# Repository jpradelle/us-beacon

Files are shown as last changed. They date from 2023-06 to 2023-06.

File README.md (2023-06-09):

# Ultrasonic indoor positioning system
This project contains electronic card design and software to build an indoor 2D positioning system based on ultrasonic 
emitters and receivers with Time Difference Of Arrival (TDOA) algorithm to determine position.

## Context
This project has been made during French Robotic Cup which takes place in european Eurobot contest. During this contest,
2 teams are playing one against the other, with one or two bots, to achieve some objectives, on a game table of 2 per 3
meters. Bots must not enter in collision with other team bots, purpose of this project is to determine quite precisely
position of 2 opponent bots.

Contest rules allow to place 3 fixed beacons on dedicated table places which will be called receivers, and a 
80mm\*80mm\*80mm beacon on each opponent bot which will be called emitters.

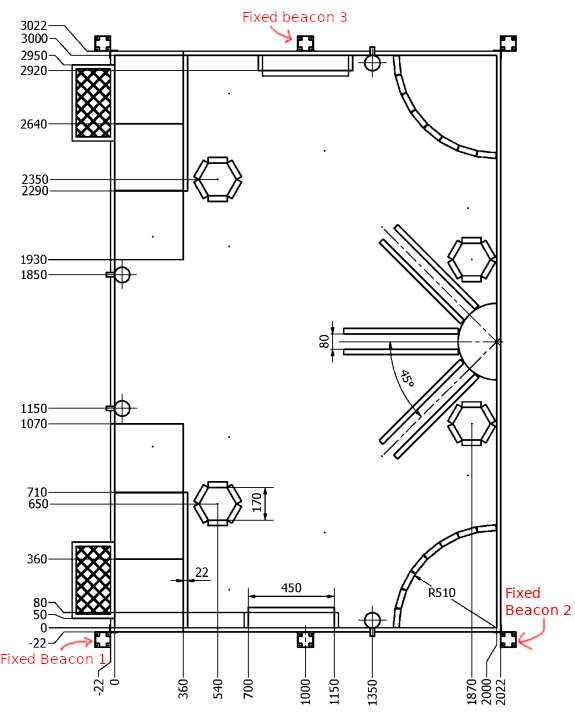
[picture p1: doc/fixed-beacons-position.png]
Fixed beacons position


See [contest rules](doc/E2017_Rules_EN.pdf) for more details.

### Extra considerations
* Due to intensive usage of 40kHz ultrasonic modules by other teams, we avoided use of 40kHz frequency.
* To avoid possible interference with other teams, a sort of "modulation" have been implemented.
* Using low frequency ultrasonic transceivers and receivers allow to emit/receive on a wide angle.

## Principle
An emitter is placed on opponent bot, emitter will emit every 75ms a signal over 360°. One of the three fixed receivers
will receive the signal first at time reference T. Due to slow speed of sound, the 2nd receives a bit later at T + dt1,
and the 3rd later next at T + dt2. Knowing speed of sound, dt1 and dt2 can be converted to distance dr1 and dr2. With
only dr1 and dr2 and a Time Difference Of Arrival (TDOA) algorithm, we can compute position of emitter on a plan.

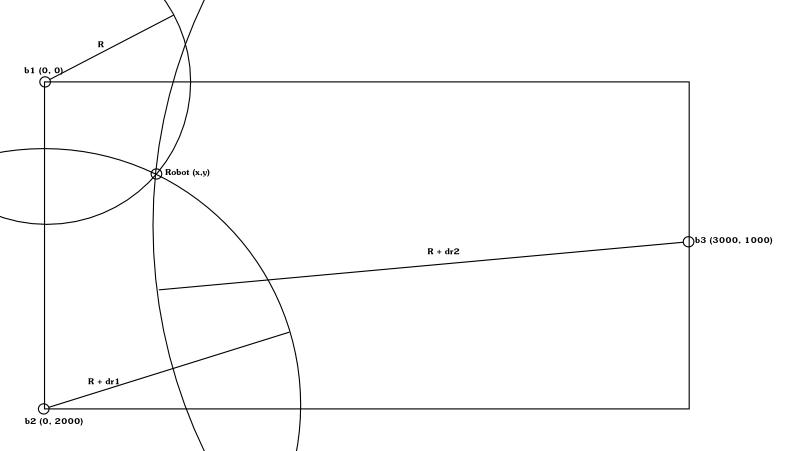
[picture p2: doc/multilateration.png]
multilateration


R is unknown, only dr1 and dr2 are determined by the system.

## System accuracy
TODO

## Architecture
Project is made of following parts.

### 2 emitters
One working with 25kHz frequency, one with 32.8kHz frequency. Emitters are made of:
* 1 9V battery
* 1 ATtiny45 microcontroller for pulse generation
* 4 ultrasonic transceivers
* some electronic for power supply, H bridge to run transceivers, ...

### 3 receivers
Each receiver beacon is made with one cards to receive 25kHz another one to receive 32.8kHz signals with 2 or 3
ultrasonic receivers.

Each ultrasonic receiver is made of
* 1 ultrasonic receiver
* 1 4 channels TLO74CN Operational Amplifier
* Some resistors, capacitors and schottky diodes for signal amplification and filtering
* 1 ATtiny45 for reading analog input and building a simple HIGH signal when ultrasonic signal is received

It contains also a power card which ensure different power conversions and aggregate demodulated signals from receivers,
made of:
* 2 9V battery
* 1 12V NCP1117DT12RKG convertor
* 1 5V R-78E5.0-0.5 convertor
* 1 3.3 LP2950ACDT-3.3RG convertor (for receiver beacon 1 only)
* Few connectors

#### Receiver 1
Contains 1 power card, 1 card with 2 receiver channels of 25kHz and 1 card with 2 receiver channels of 32.8kHz.

It also contains 1 RF card, which receive all numerical signals produced by receivers channels, compute TDOA algorithm
and send position by serial to RF module. It is made of:
* 1 Teensy 3.2 micro controller
* 1 RFBee (or 1 ESP8266, extra adaptor card needed)
* Few 3.3V zener diodes and schottky diodes
* Few connectors

#### Receiver 2
Contains 1 power card, 1 card with 2 receiver channels of 25kHz and 1 card with 2 receiver channels of 32.8kHz.

#### Receiver 3
Contains 1 power card, 1 card with 3 receiver channels of 25kHz and 1 card with 3 receiver channels of 32.8kHz.

## Folder structure of project
### Simulation
[simu](simu) folder contains some simulations for testing different TOA and TDOA algorithms.
See [simu/README.md](simu/README.md) for more details of algorithms performances.

### Electronics
[elec](elec) folder contains electronic designs of one 25kHz emitter, one 32.8kHz emitter, 3 receivers of 25kHz and
32.8kHz, and other power cards. See [elec/README.md](elec/README.md) for more information.

### Code
[code](code) folder contains code of all microcontroller used in this project. See [code/README.md](code/README.md) for
more information.

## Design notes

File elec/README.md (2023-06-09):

# Electronic
This folder contains needed electronics schema made with Kicad software for building working solution for 2 bots
positioning.

## Kicad projects
### 25kHz emitter
Electronic schematics and PCB drawings are made in [emetteur 25khz](emetteur%2025khz) project.

PDF schematics [here](../doc/elec/25khz_emitter_schematics.pdf)

### 32.8kHz emitter
Electronic schematics and PCB drawings are made in [emetteur 32khz](emetteur%2032khz) project.

PDF schematics [here](../doc/elec/32khz_emitter_schematics.pdf)

### 3 sets of 25kHz receivers
Electronic schematics and PCB drawings are made in [recepteur 25khz](recepteur%2025khz) project.

PDF schematics [here](../doc/elec/25khz_receiver_schematics.pdf)

Project contains stuff for building 2 fixed receiving beacons made of 2 ultrasonic receivers and 1 fixed receiving
beacon made of 3 ultrasonic receivers.

This projects contains other cards, see after.

### 3 sets of 32.8kHz receivers
Electronic schematics and PCB drawings are made in [recepteur 32khz](recepteur%2032khz) project.

PDF schematics [here](../doc/elec/32khz_receiver_schematics.pdf)

Project contains stuff for building 2 fixed receiving beacons made of 2 ultrasonic receivers and 1 fixed receiving
beacon made of 3 ultrasonic receivers.

### 3 power cards
Electronic schematics and PCB drawings are made in [recepteur 25khz](recepteur%2025khz) project.

Those 3 power cards are made for powering receiving cards and aggregating receiving cards signal to output them on one
connector.

### RF card
Electronic schematics and PCB drawings are made in [recepteur 25khz](recepteur%2025khz) project.

This RF card made for running TDOA algorithm with signals given from 3 power cards on a teensy microcontroller, found
position is expected to be transmitted by serial to RF card.

## Bill Of Material
### 25kHz emitter
| Item | Qty | Reference(s) | RadioSpares ref |
|---|-----|---|---|
| 100n | 1 | C1 | 264-4416 |
| LED | 1 | D1 | |
| ATTINY45-P | 1 | IC1 | 696-2614 |
| CONN_2 | 5 | P1, P3, P4, P5, P6 | 163-5303, 163-5305 |
| 2N3904 | 8 | Q1, Q4, Q5, Q7, Q9, Q12, Q14, Q16 | 739-0397 |
| 2N3906 | 8 | Q2, Q3, Q6, Q8, Q10, Q11, Q13, Q15 | 739-0375 |
| 22k | 16  | R1, R2, R4, R5, R7, R8, R9, R10, R11, R12, R16, R17, R18, R19, R20, R21 | 740-9016 |
| 1k | 5 | R3, R6, R13, R14, R15 | 740-8971 |
| 10k | 1 | R22 | 740-9072 |
| R-78E5.0-0.5 | 1 | REGUL1 | 757-7239 |
| SWITCH | 1 | U1 | 734-7315 |

+ 4 25kHz Ultrasonic transmitters

### 32.8kHz emitter
| Item | Qty | Reference(s) | RadioSpares ref |
|---|-----|---|---|
| 100n | 1 | C1 | 264-4416 |
| LED | 1 | D1 | |
| ATTINY45-P | 1 | IC1 | 696-2614 |
| CONN_2 | 5 | P1, P3, P4, P5, P6 | 163-5303, 163-5305 |
| 2N3904 | 8 | Q1, Q4, Q5, Q7, Q9, Q12, Q14, Q16 | 739-0397 |
| 2N3906 | 8 | Q2, Q3, Q6, Q8, Q10, Q11, Q13, Q15 | 739-0375 |
| 22k | 16  | R1, R2, R4, R5, R7, R8, R9, R10, R11, R12, R16, R17, R18, R19, R20, R21 | 740-9016 |
| 1k | 5 | R3, R6, R13, R14, R15 | 740-8971 |
| 10k | 1 | R22 | 740-9072 |
| R-78E5.0-0.5 | 1 | REGUL1 | 757-7239 |
| SWITCH | 1 | U1 | 734-7315 |

+ 4 32.8kHz Ultrasonic transmitters

### 25kHz receivers + power cards + RF card
| Value | Qty | Reference(s) | RadioSpares ref |
|---|-----|---|---|
| 10n | 14  | C1, C5, C12, C16, C23, C27, C34, C38, C45, C49, C56, C60, C67, C71 | 264-4371 |
| 470p | 14  | C2, C8, C13, C19, C24, C30, C35, C41, C46, C52, C57, C63, C68, C74 | 264-4315 |
| 47n | 14  | C3, C4, C14, C15, C25, C26, C36, C37, C47, C48, C58, C59, C69, C70 | 147-998 |
| 100n | 21  | C6, C7, C11, C17, C18, C22, C28, C29, C33, C39, C40, C44, C50, C51, C55, C61, C62, C66, C72, C73, C77 | 264-4416 |
| 1n | 14  | C9, C10, C20, C21, C31, C32, C42, C43, C53, C54, C64, C65, C75, C76 | 264-4337 |
| 10µ | 6 | C78, C79, C80, C81, C82, C83 | 440-6553 |
| 1µ | 1 | C84 | |
| DIODESCH | 42  | D1, D2, D3, D4, D5, D6, D7, D8, D9, D10, D11, D12, D13, D14, D15, D16, D17, D18, D19, D20, D21, D22, D23, D24, D25, D26, D27, D28, D39, D41, D43, D45, D47, D49, D51, D53, D55, D57, D59, D61, D63, D65 | 743-5894 |
| LED | 10  | D29, D30, D31, D32, D33, D34, D35, D36, D37, D38 | |
| ZENER | 14  | D40, D42, D44, D46, D48, D50, D52, D54, D56, D58, D60, D62, D64, D66 | 710-4216 |
| ATTINY45-P | 7 | IC1, IC2, IC3, IC4, IC5, IC6, IC7 | 696-2614 |
| TEENSY | 1 | IC8 | |
| CONN_3 | 1 | K1 | 163-5303, 163-5305 |
| CONN_6 | 6 | P1, P4, P5, P8, P10, P17 | 163-5303, 163-5305 |
| CONN_2 | 6 | P2, P3, P6, P7, P12, P13 | 163-5303, 163-5305 |
| CONN_5 | 2 | P9, P19 | 163-5303, 163-5305 |
| CONN_7 | 7 | P11, P14, P15, P16, P18, P20, P21 | 163-5303, 163-5305 |
| CONN_4 | 1 | P22 | 163-5303, 163-5305 |
| 1k | 21  | R1, R2, R5, R11, R12, R13, R14, R17, R27, R33, R34, R37, R45, R46, R49, R55, R56, R59, R65, R66, R69 | 740-8971 |
| 10k | 37  | R3, R4, R8, R15, R16, R20, R23, R24, R25, R26, R30, R35, R36, R40, R43, R44, R47, R48, R52, R57, R58, R62, R67, R68, R72, R75, R76, R77, R78, R79, R80, R81, R82, R83, R84, R85, R86 | 740-9072 |
| 47k | 28  | R6, R7, R9, R10, R18, R19, R21, R22, R28, R29, R31, R32, R38, R39, R41, R42, R50, R51, R53, R54, R60, R61, R63, R64, R70, R71, R73, R74 | 740-9035 |
| 2.2k | 14  | R87, R88, R89, R90, R91, R92, R93, R94, R95, R96, R97, R98, R99, R100 | 810-1750 |
| RFBEE | 1 | RF1 | |
| TL074 | 7 | U1, U2, U3, U4, U9, U10, U11 | 302-621 |
| R-78E5.0-0.5 | 3 | U5, U7, U12 | 757-7239 |
| NCP1117DT12RKG | 3 | U6, U8, U13 | 518-8341 |
| SWITCH | 3 | U14, U15, U16 | 734-7315 |
| LP2950ACDT-3.3RG | 1 | U17 | 805-1416 |
| ULTRASON | 7 | US1, US2, US3, US4, US5, US6, US7 | |

### 32.8kHz receivers
| Value | Qty | Reference(s) | RadioSpares ref |
|---|-----|---|---|
| 6.8n | 14  | C1, C5, C12, C16, C23, C27, C34, C38, C45, C49, C56, C60, C67, C71 | |
| 220p | 14  | C2, C8, C13, C19, C24, C30, C35, C41, C46, C52, C57, C63, C68, C74 | 264-4309 |
| 47n | 14  | C3, C4, C14, C15, C25, C26, C36, C37, C47, C48, C58, C59, C69, C70 | 147-998 |
| 100n | 21  | C6, C7, C11, C17, C18, C22, C28, C29, C33, C39, C40, C44, C50, C51, C55, C61, C62, C66, C72, C73, C77 | 264-4416 |
| 1n | 7 | C9, C20, C31, C42, C53, C64, C75 | 264-4337 |
| 2.2n | 7 | C10, C21, C32, C43, C54, C65, C76 | 264-4359 |
| DIODESCH | 28  | D1, D2, D3, D4, D5, D6, D7, D8, D9, D10, D11, D12, D13, D14, D15, D16, D17, D18, D19, D20, D21, D22, D23, D24, D25, D26, D27, D28 | 743-5894 |
| LED | 7 | D29, D30, D31, D32, D33, D34, D35 | |
| ATTINY45-P | 7 | IC1, IC2, IC3, IC4, IC5, IC6, IC7 | 696-2614 |
| CONN_6 | 2 | P4, P5 | 163-5303, 163-5305 |
| CONN_7 | 1 | P11 | 163-5303, 163-5305 |
| 1k | 21  | R1, R2, R5, R11, R12, R13, R14, R17, R27, R33, R34, R37, R45, R46, R49, R55, R56, R59, R65, R66, R69 | 740-8971 |
| 22k | 14  | R3, R8, R15, R20, R25, R30, R35, R40, R47, R52, R57, R62, R67, R72 | 740-9016 |
| 6.8k | 7 | R4, R16, R26, R36, R48, R58, R68 | 810-1889 |
| 47k | 28  | R6, R7, R9, R10, R18, R19, R21, R22, R28, R29, R31, R32, R38, R39, R41, R42, R50, R51, R53, R54, R60, R61, R63, R64, R70, R71, R73, R74 | 740-9035 |
| 10k | 7 | R77, R78, R79, R80, R81, R82, R83 | 740-9072 |
| TL074 | 7 | U1, U2, U3, U4, U9, U10, U11 | 302-621 |
| ULTRASON | 7 | US1, US2, US3, US4, US5, US6, US7 | |

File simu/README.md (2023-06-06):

# Simulation
This contains some algorithm implementation of Time Of Arrival (TOA) and Time Difference Of Arrival (TDOA) case.
Choosing TOA algorithm would be in case we have access to the 3 distances between each fixed beacon and emitter.
Choosing TDOA algorithm would be in case we only have access to distance difference between 1st and 2nd receiver and 1st
and 3rd receiver, which is the case in that project.

Purpose of this project is to test algorithm result error if we add a small distance error in measurements. We iterate
every table position several times, compute real distances between beacons, add a random error on each distance, compute
algorithm from those errored measurement and compare result with real position.

## Simulated algorithms
### TDOA Fang
Paper explaining it: 
[http://xml.jips-k.org/full-text/view?doi=10.3745/JIPS.04.0172](http://xml.jips-k.org/full-text/view?doi=10.3745/JIPS.04.0172)

Implemented in
[SimuMultilateration/src/com/opensabot/multilateration/tdoa/FangThreePointsLateration.java](SimuMultilateration/src/com/opensabot/multilateration/tdoa/FangThreePointsLateration.java)

### TDOA Iterative three points
Kind of brute force not working solution, you can ignore it.

Implemented in
[SimuMultilateration/src/com/opensabot/multilateration/tdoa/IterativeThreePointsLateration.java](SimuMultilateration/src/com/opensabot/multilateration/tdoa/IterativeThreePointsLateration.java)

### TOA Circle three points
Principle: draw circles around each fixed receiver of radius of measured value, find intersection of the three circules.

Implemented in
[SimuMultilateration/src/com/opensabot/multilateration/toa/CircleThreePointsToaLateration.java](SimuMultilateration/src/com/opensabot/multilateration/toa/CircleThreePointsToaLateration.java)

### TOA TULIP three points
Principle: https://confluence.slac.stanford.edu/display/IEPM/TULIP+Algorithm+Alternative+Trilateration+Method

Implemented in
[SimuMultilateration/src/com/opensabot/multilateration/toa/TulipThreePointsToaLateration.java](SimuMultilateration/src/com/opensabot/multilateration/toa/TulipThreePointsToaLateration.java)

# Run project
Project contains several entry points for different tests. We will focus on `com.opensabot.multilateration.ImageSimu`
which generate a graph of average error of algorithm.

## Configure project
In `com.opensabot.multilateration.ImageSimu` you can update constants:
* `NB_ITERATION = 100` is the number of iteration to run algorithm for each position.
* `ERROR = 68` is the maximum of random error to be added on measurements. 68mm correspond to the distance ran by 5 
  25kHz ultrasonic pulses (340 * 1/25000 * 5 = 0.068m), which feels achievable objective for the hardware.
* `ERROR_THRESHOLD_AVG = 100` is the max value of scale displayed at right of generated image for average error graph.
* `ERROR_THRESHOLD_MAX = 250` is the max value of scale displayed at right of generated image for max error graph.

You can also comment algorithm you don't want to run and chose one and only to run in this block of code
```java
		// Run wanted algorithm
		// TOA algorithms
//		runToa1CircleThreePointsToaLateration(b1, b2, b3, errorMap);
//		runToa2CircleThreePointsToaLateration(b1, b2, b3, b12, b22, b32, errorMap);
//		runToa1TulipThreePointsToaLateration(b1, b2, b3, errorMap);
//		runToa2TulipThreePointsToaLateration(b1, b2, b3, b12, b22, b32, errorMap);
		// TDOA algorithms
		runTdoa1FangThreePointsLateration(b1, b2, b3, errorMap);
//		runTdoa2FangThreePointsLateration(b1, b2, b3, b12, b22, b32, errorMap);
//		runTdoa1IterativeThreePointsLateration(b1, b2, b3, errorMap);
```

Some configuration run only one measurement compute with one set of fixed beacons, and other run it with two sets of
fixed beacons and get average of two measurements.

## Run simulation
Either open and run project with and IDE and ensure working directory is set to `simu/SimuMultilateration`.

Or open a console and go to SimuMultilateration project, and compile it.
```bash
cd simu/SimuMultilateration
javac src/**/*.java -d target/
```

Run viewer
```bash
java -cp target/ com.opensabot.multilateration.ImageSimu
```

# Results
All simulations were ran with a random error between 0 to 68mm added in values that hardware will measure, 500
iterations.

68mm error correspond to an error of 5 ultrasonic pulses at 25kHz.

## TDOA
### Fang algorithm
With one set of 3 fixed receiving beacon:

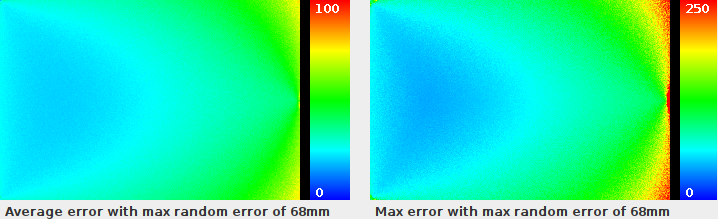
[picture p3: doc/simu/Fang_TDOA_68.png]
FANG_TDOA


With one 2 sets of 3 fixed receiving beacon, final point is average of 2 found positions:

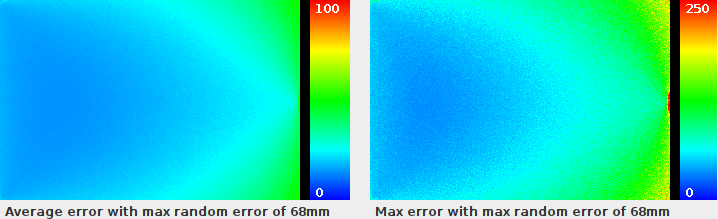
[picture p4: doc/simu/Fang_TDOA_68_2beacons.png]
FANG_TDOA


## TOA
### Circle algorithm
With one set of 3 fixed receiving beacon:

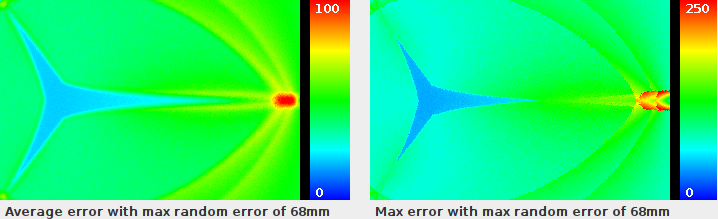
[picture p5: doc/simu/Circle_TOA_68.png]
CIRCLE_TDOA


With one 2 sets of 3 fixed receiving beacon, final point is average of 2 found positions:

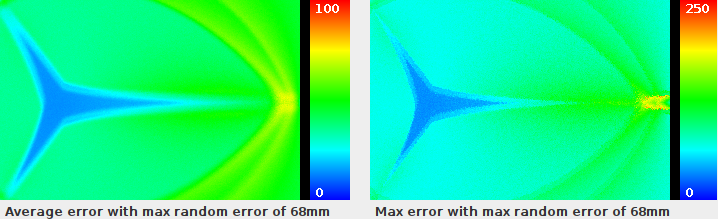
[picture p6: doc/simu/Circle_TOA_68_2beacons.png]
CIRCLE_TDOA


### TULIP algorithm
With one set of 3 fixed receiving beacon:

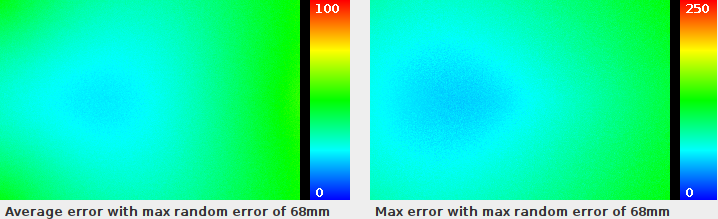
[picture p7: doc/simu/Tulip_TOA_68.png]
TULIP_TDOA


With one 2 sets of 3 fixed receiving beacon, final point is average of 2 found positions:

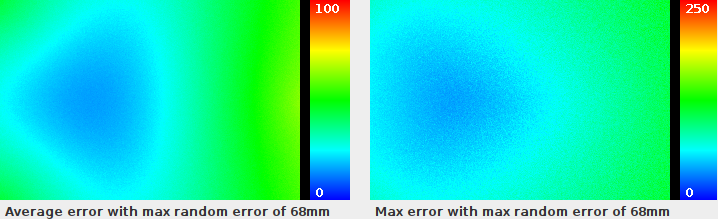
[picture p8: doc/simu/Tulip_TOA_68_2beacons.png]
TULIP_TDOA


## Conclusion
As we can see, choosing a TDAO algorithm instead of TOA will not make system less tolerant to errors in measurement, but
should be easier to implement. Adding multiple receivers even if very closed from each other should also improve system
accuracy. With not really accurate measurement, with an error of 68mm on measured values, worst found position has
almost alway an error of less than 12cm, and even less than 10cm in most cases.

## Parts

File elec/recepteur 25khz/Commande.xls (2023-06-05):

Type | Quantité | Ref | Ref part
100nF | 100 | 390-990 | 2644416
10nF | 50 | 264-4371
1nF | 50 | 264-4337
470pF | 50 | 264-4315
47nF | 50 | 147-998
10µF | 50 | 440-6553
1k Ohm | 100 | 740-8971
10k Ohm | 100 | 740-9072
22k Ohm | 50 | 740-9016
47k Ohm | 100 | 740-9035 | ERJ6RBD4702V
Interrupteur | 8 | 734-7315
ATTINY45-20PU | 20 | 696-2614
Diode schotky | 50 | 743-5894
NCP1117DT12RKG | 5 | 518-8341
TL074CN | 10 | 302-621
Zener 3,3V | 100 | 710-4216
2N3904 | 20 | 739-0397
2N3906BU | 20 | 739-0375
PCB | 3 | 745-0819
LP2950ACDT-3.3RG | 20 | 805-1416
1µF | 50 | 440-6531
Brucelle | 1 | 549-628 |  | http://fr.farnell.com/duratool/1pk-125t-f/pince-brucelle/dp/3127692
 |  |  |  | http://fr.farnell.com/duratool/1pk-110t-f/pince-brucelle-pointe-courbee/dp/3127620
 |  |  |  | http://www.ebay.fr/itm/pince-brucelle-precelle-PINCETTE-Coudee-droite-OUTIL-MAQUETTISME-COURBE-7-modele-/230930073922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
Farnell
Brucelle | 1
Regul 5V | 7

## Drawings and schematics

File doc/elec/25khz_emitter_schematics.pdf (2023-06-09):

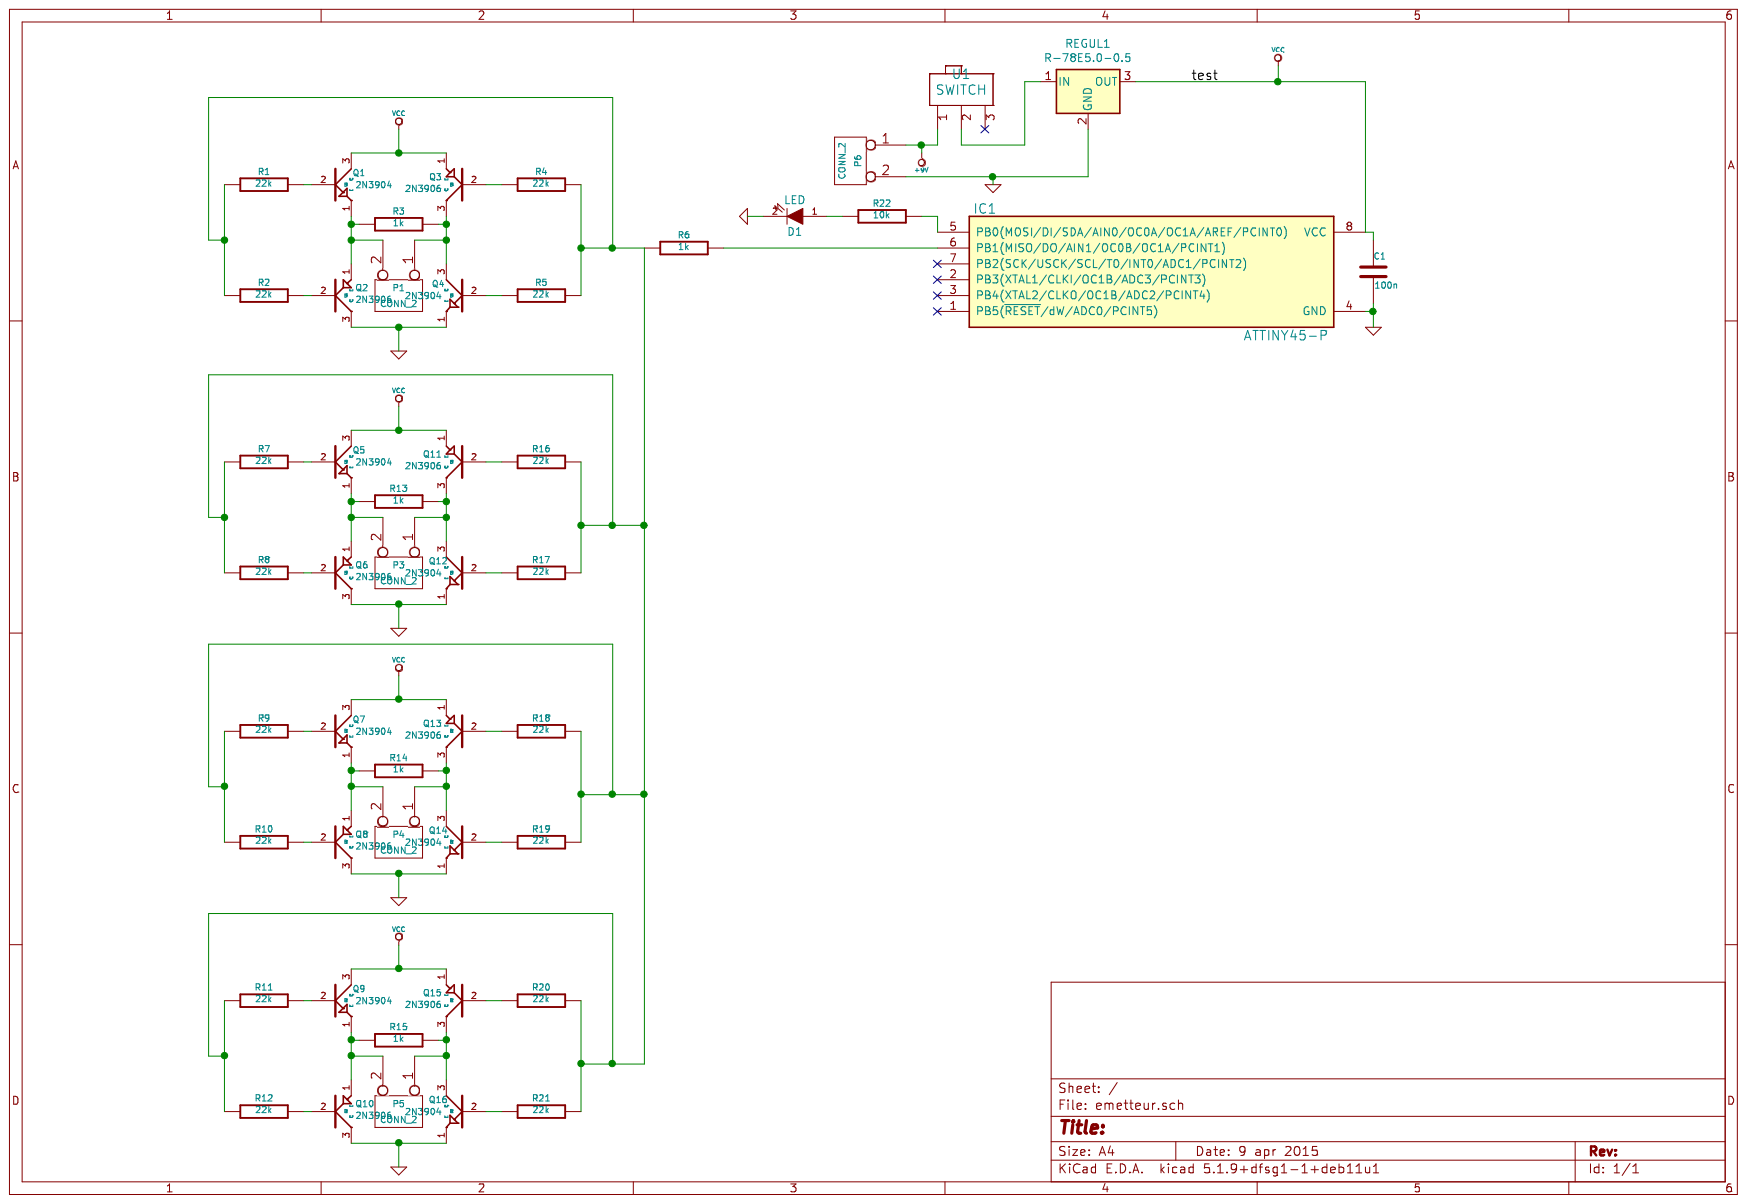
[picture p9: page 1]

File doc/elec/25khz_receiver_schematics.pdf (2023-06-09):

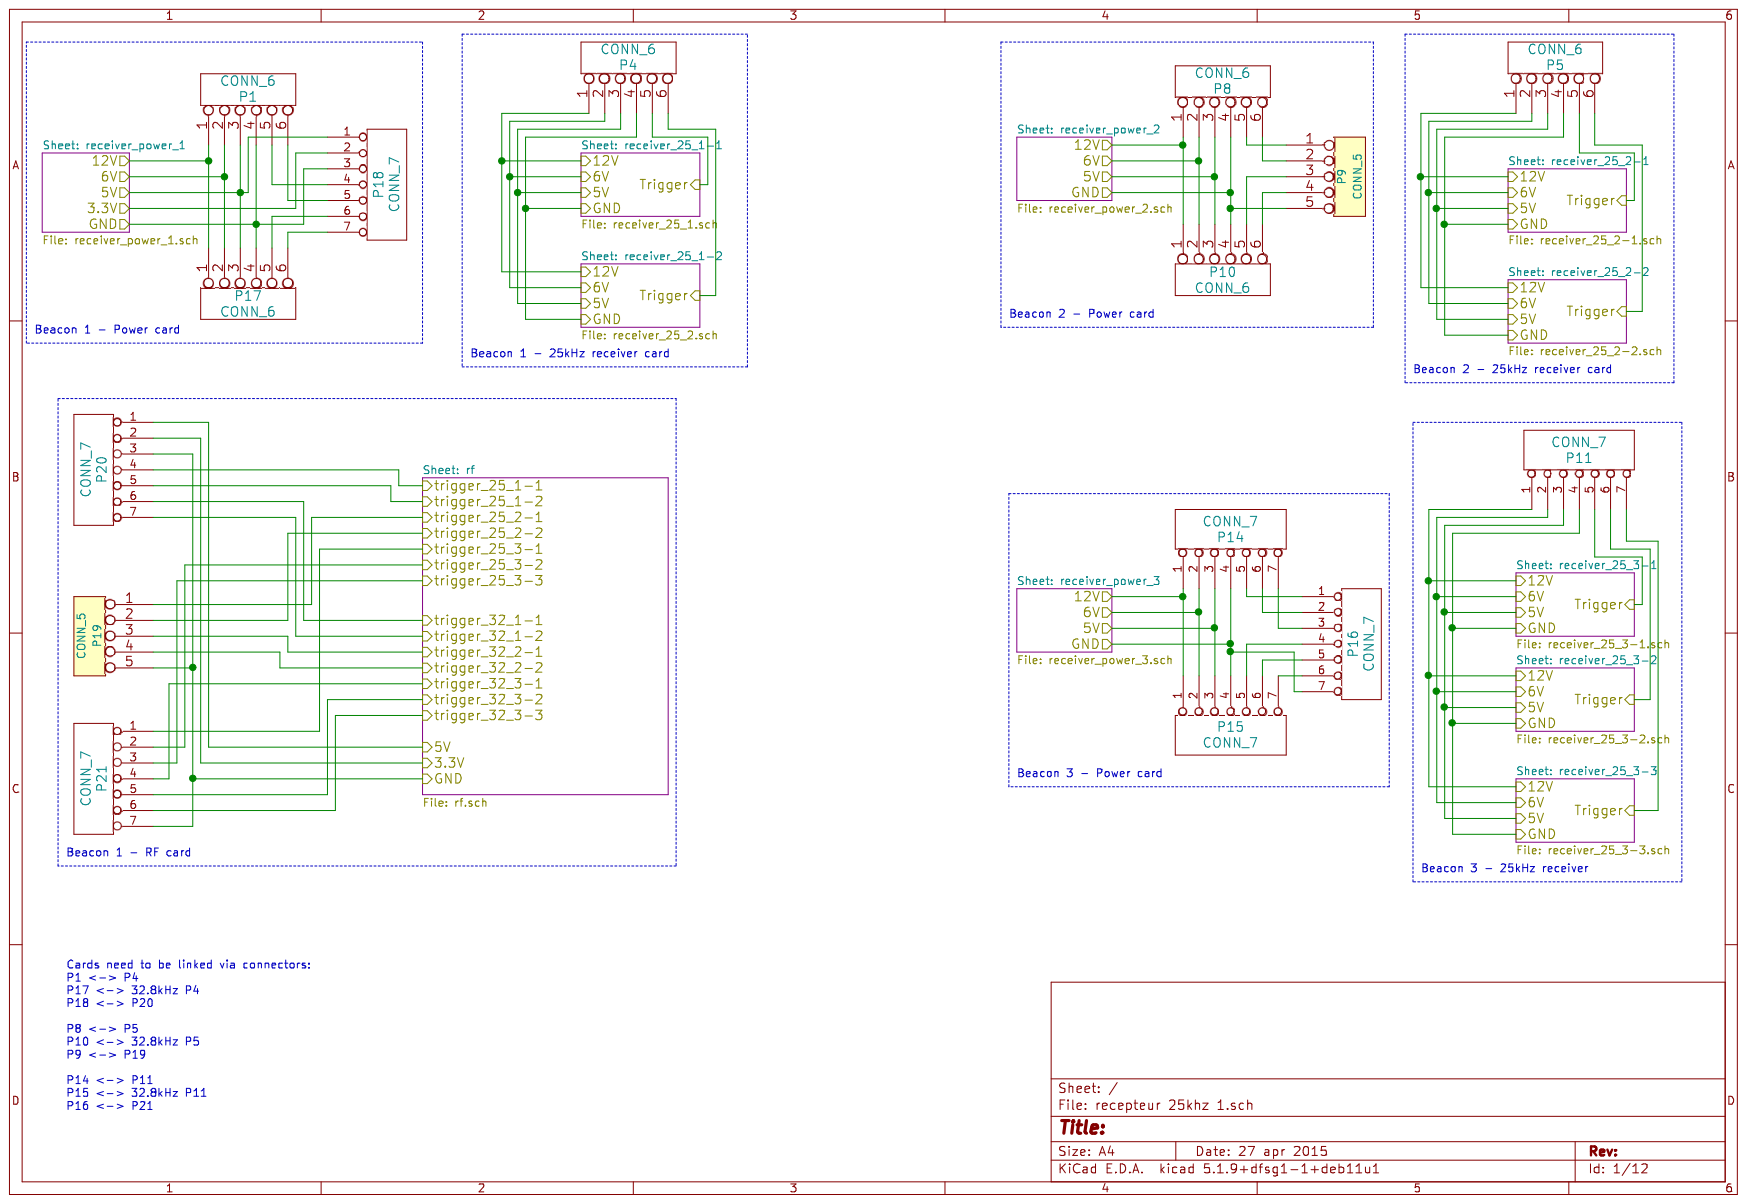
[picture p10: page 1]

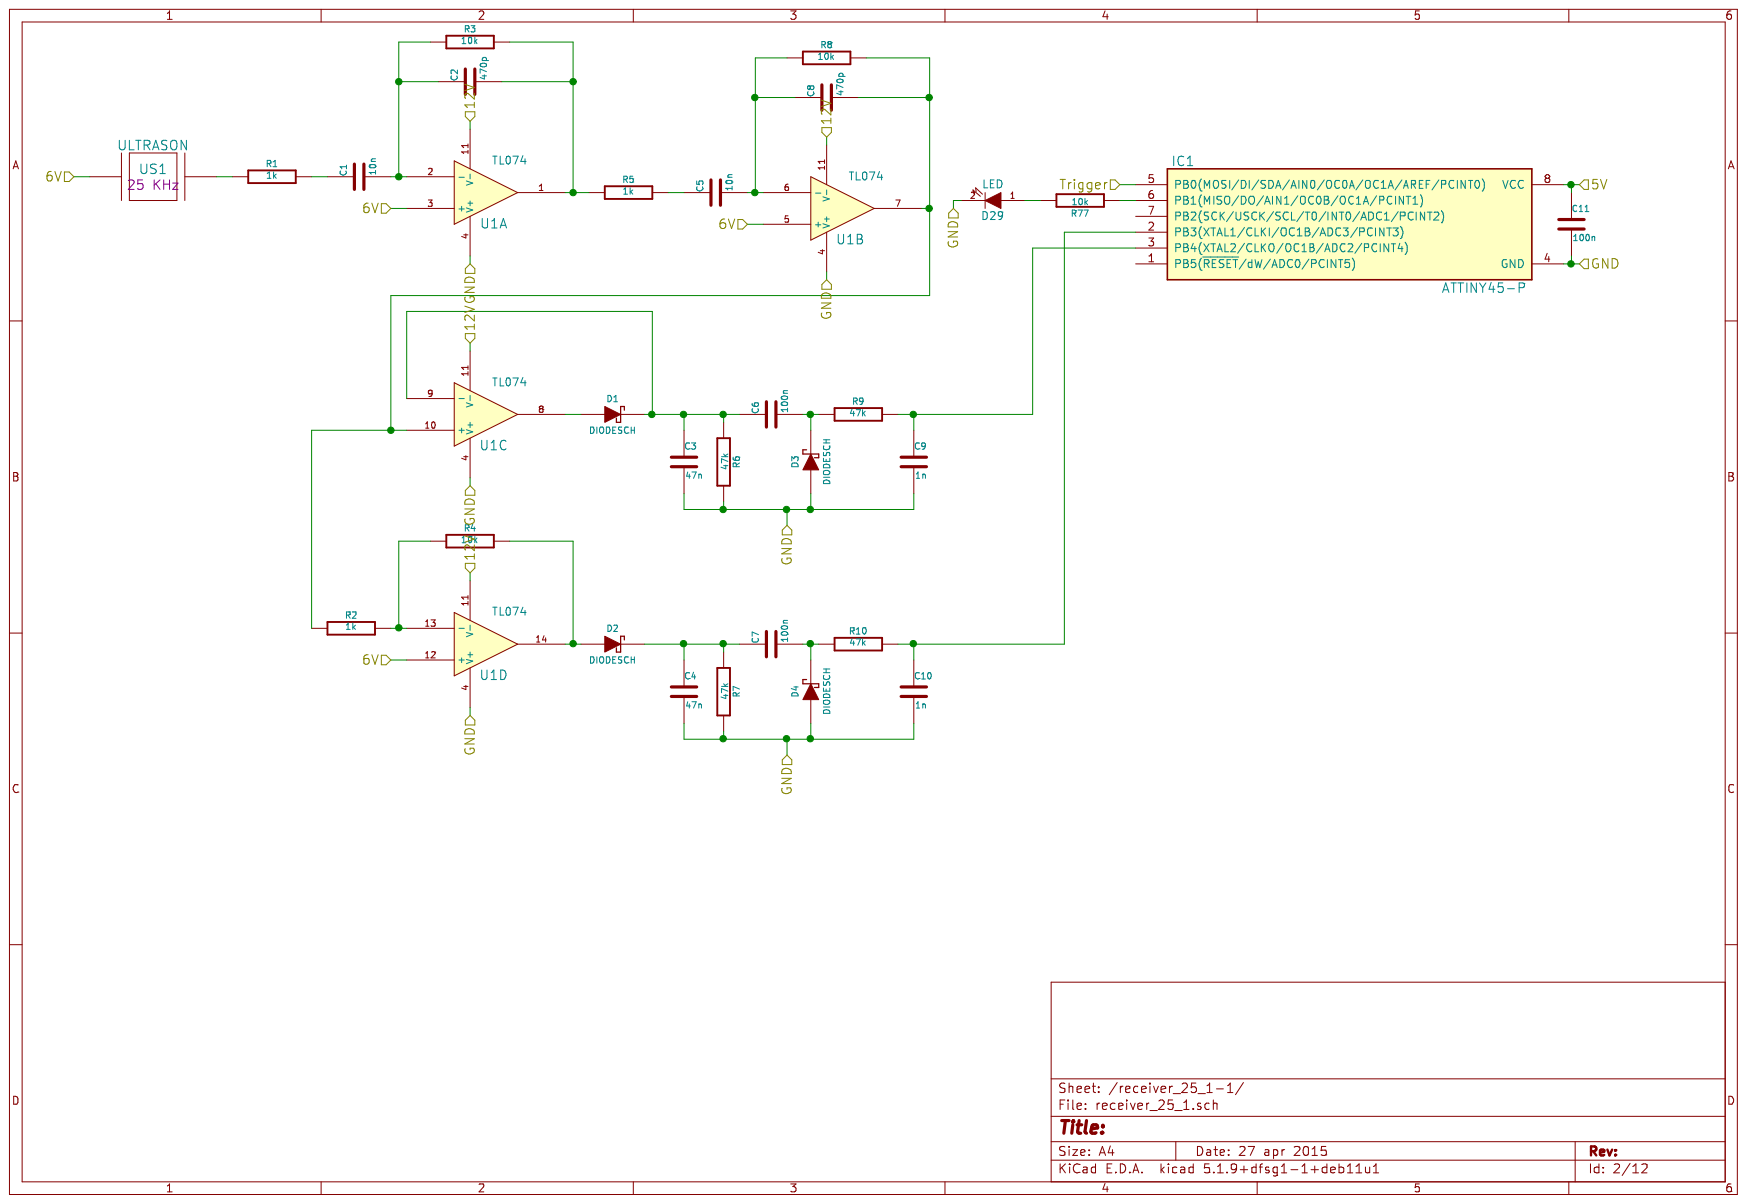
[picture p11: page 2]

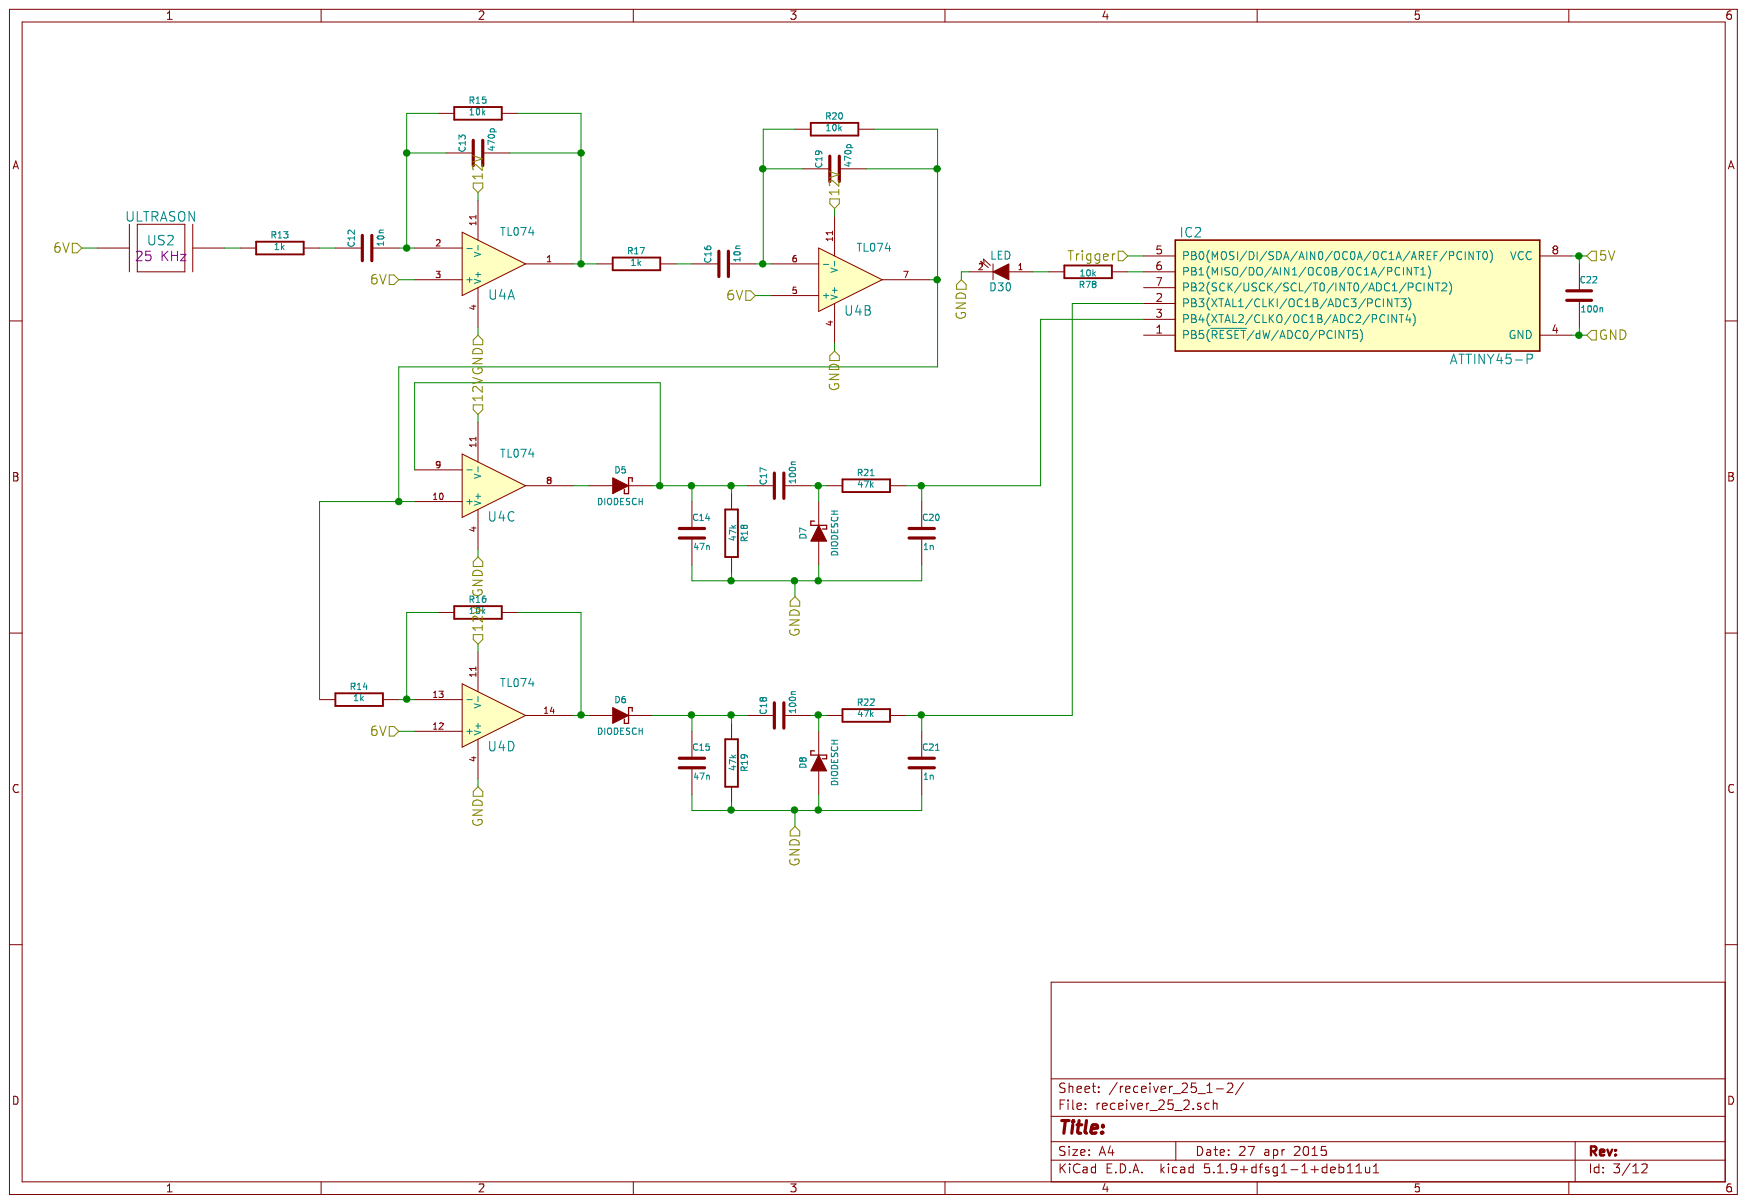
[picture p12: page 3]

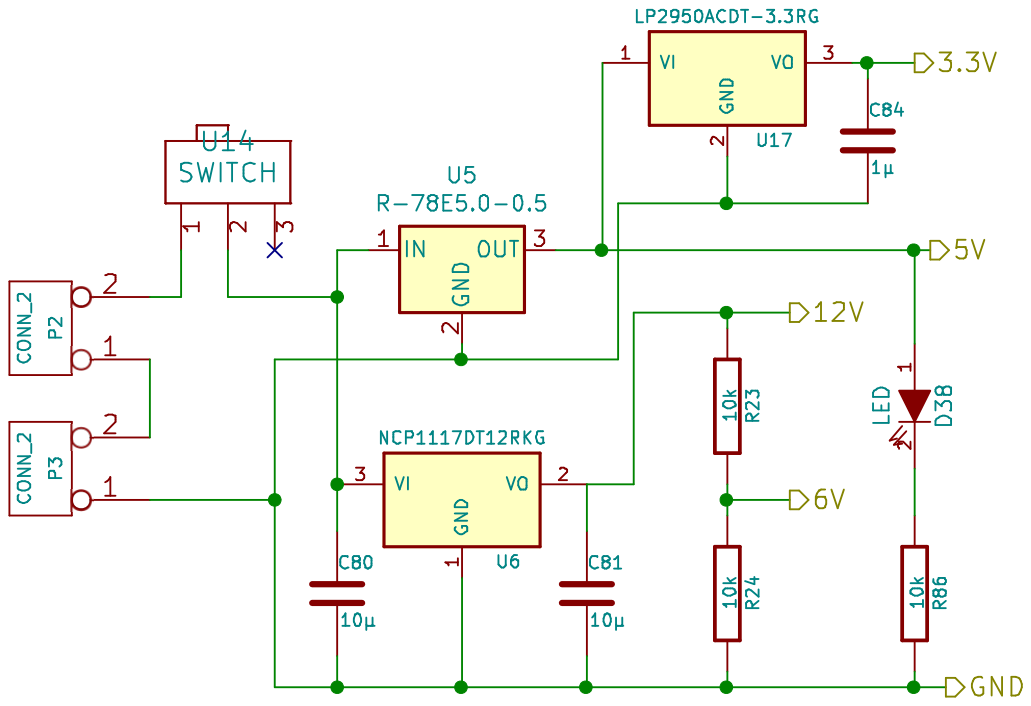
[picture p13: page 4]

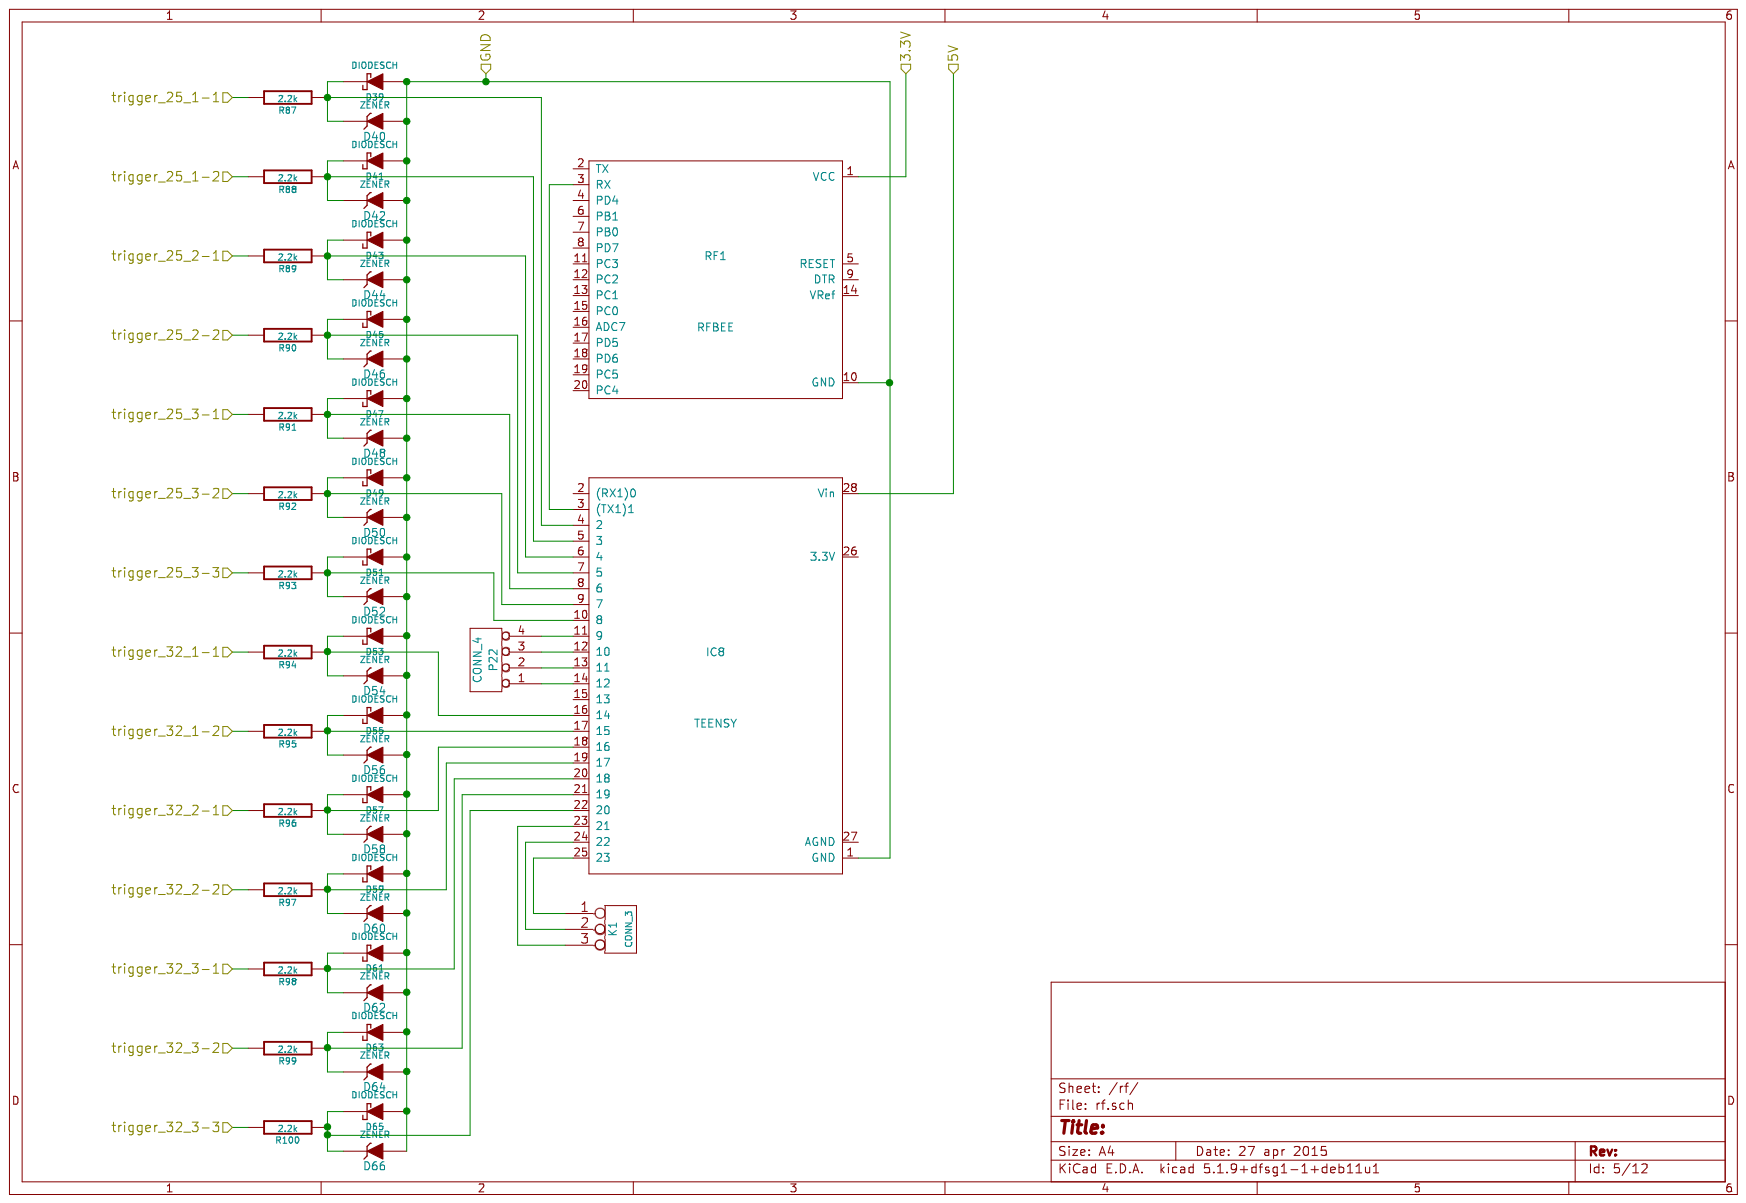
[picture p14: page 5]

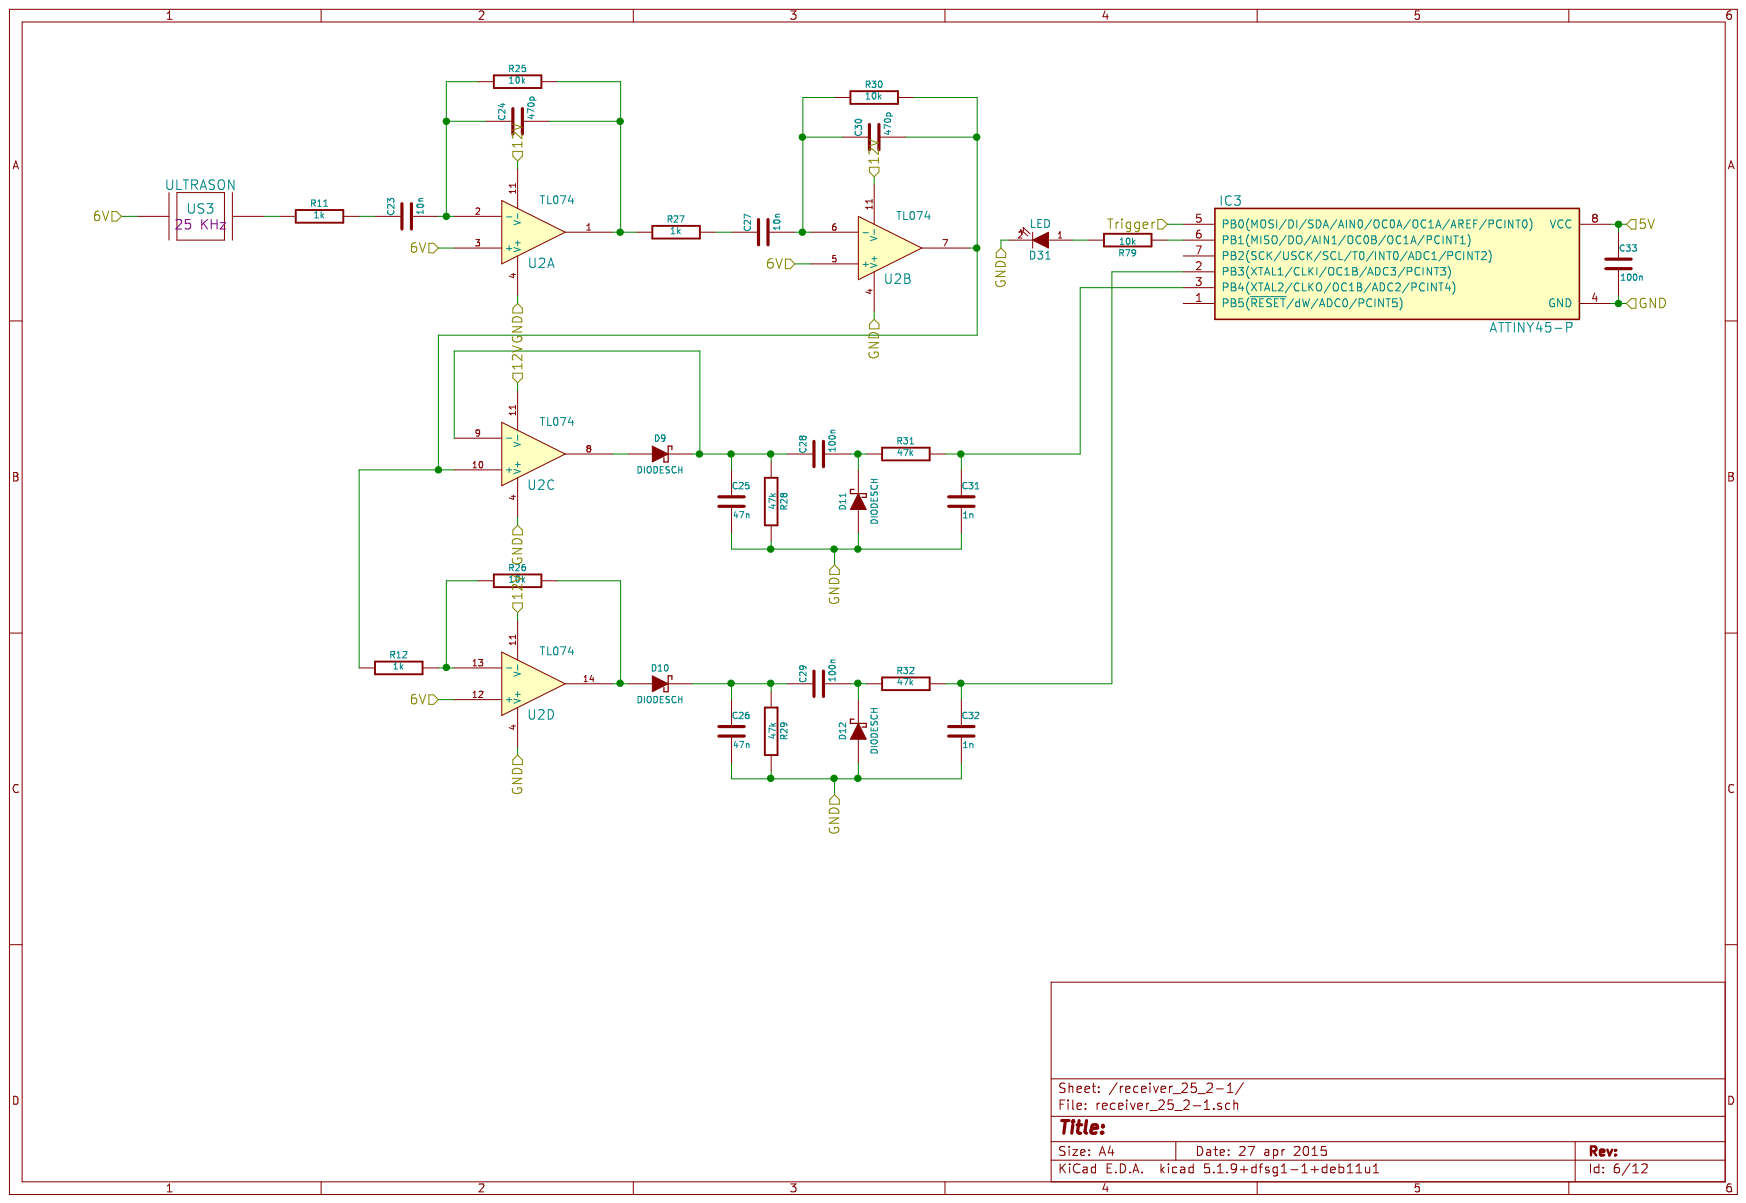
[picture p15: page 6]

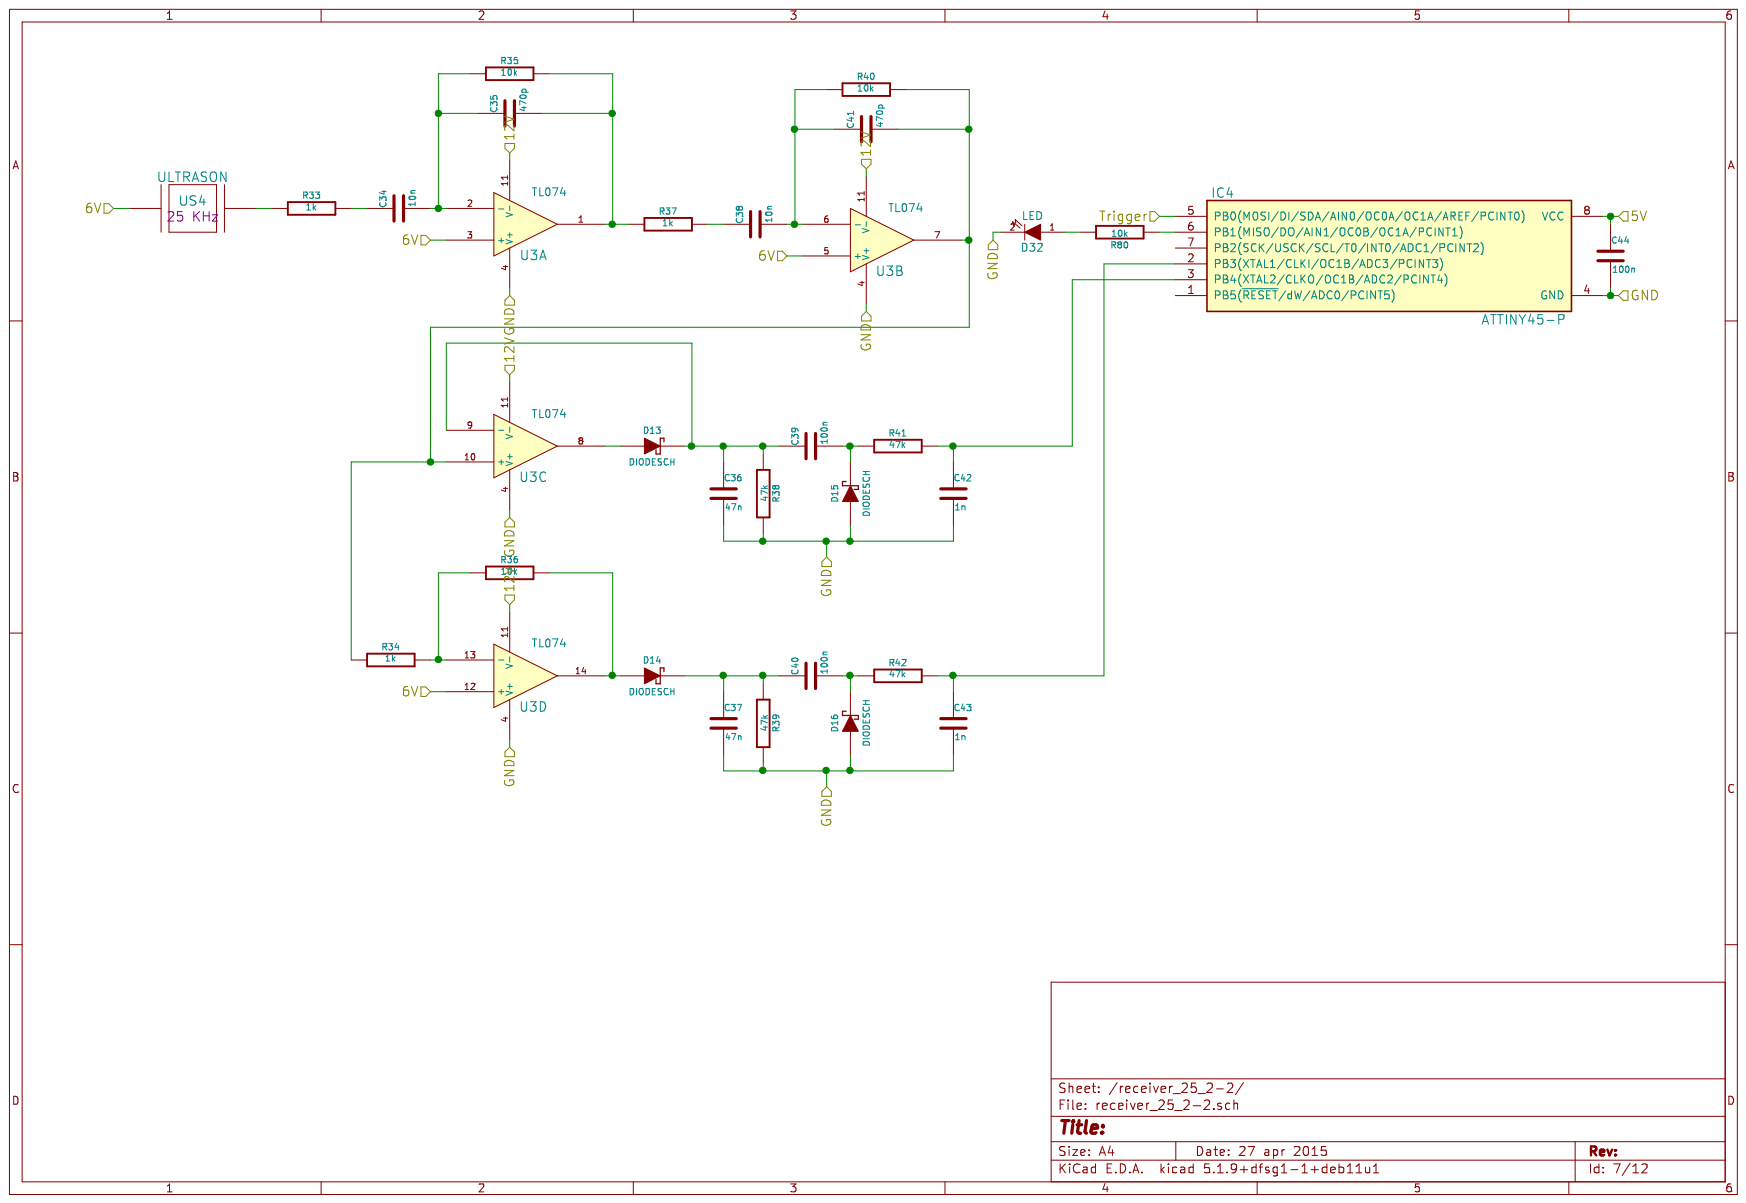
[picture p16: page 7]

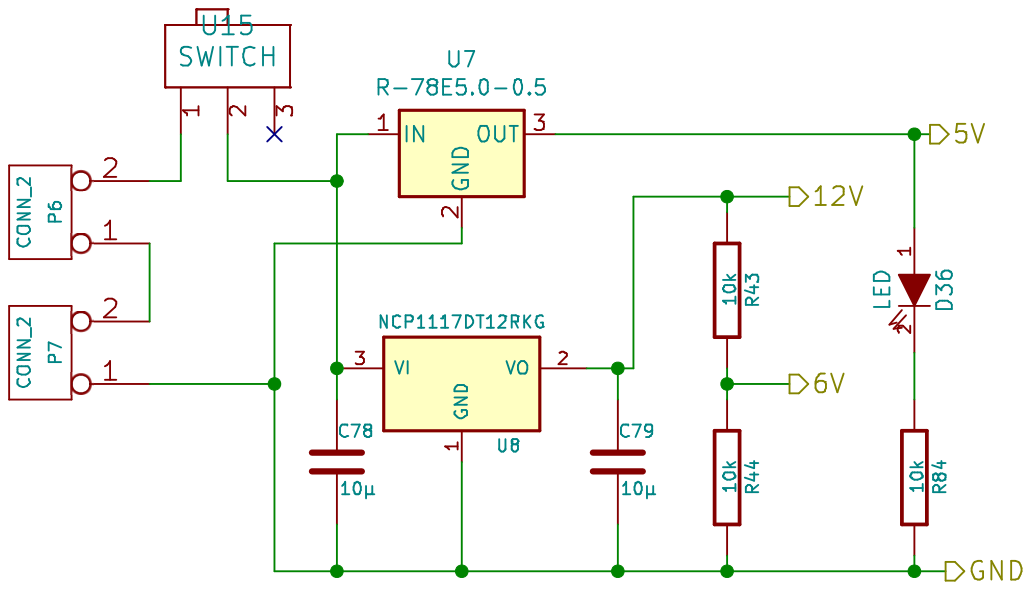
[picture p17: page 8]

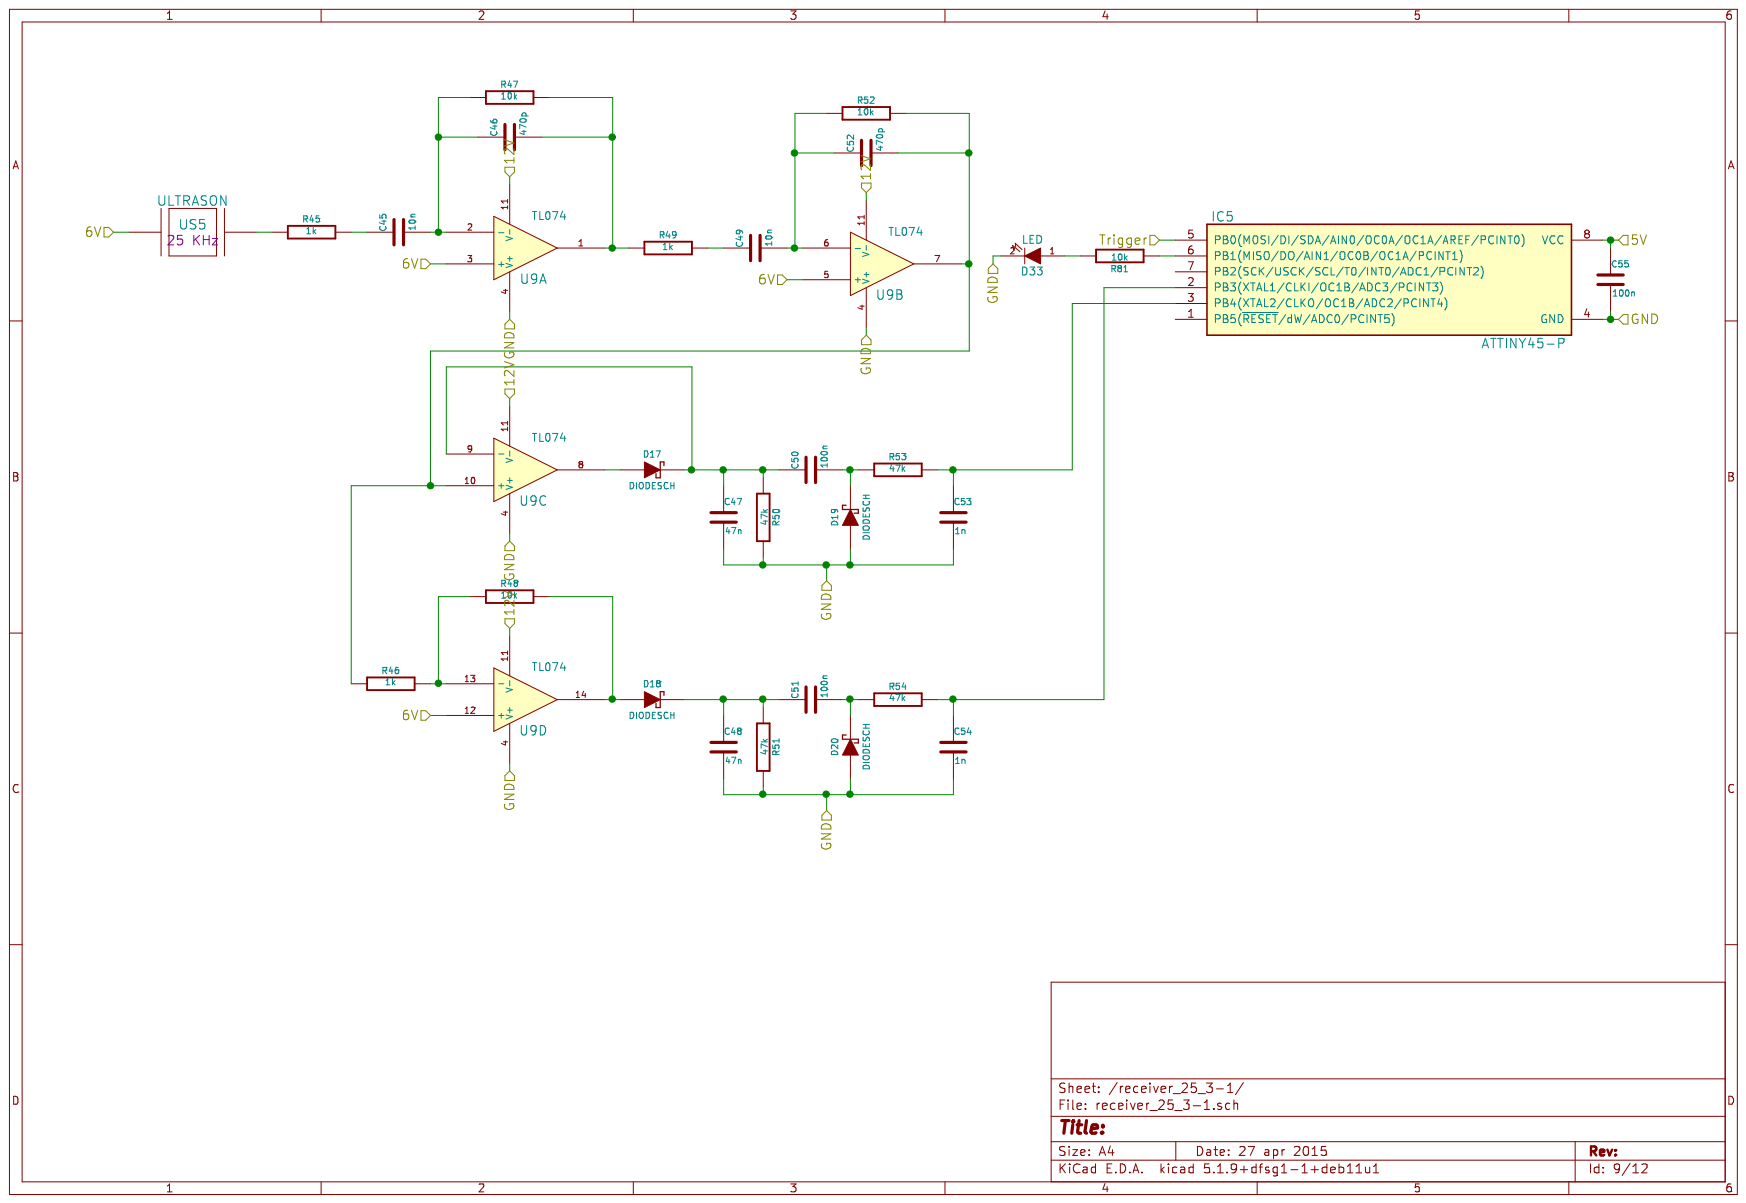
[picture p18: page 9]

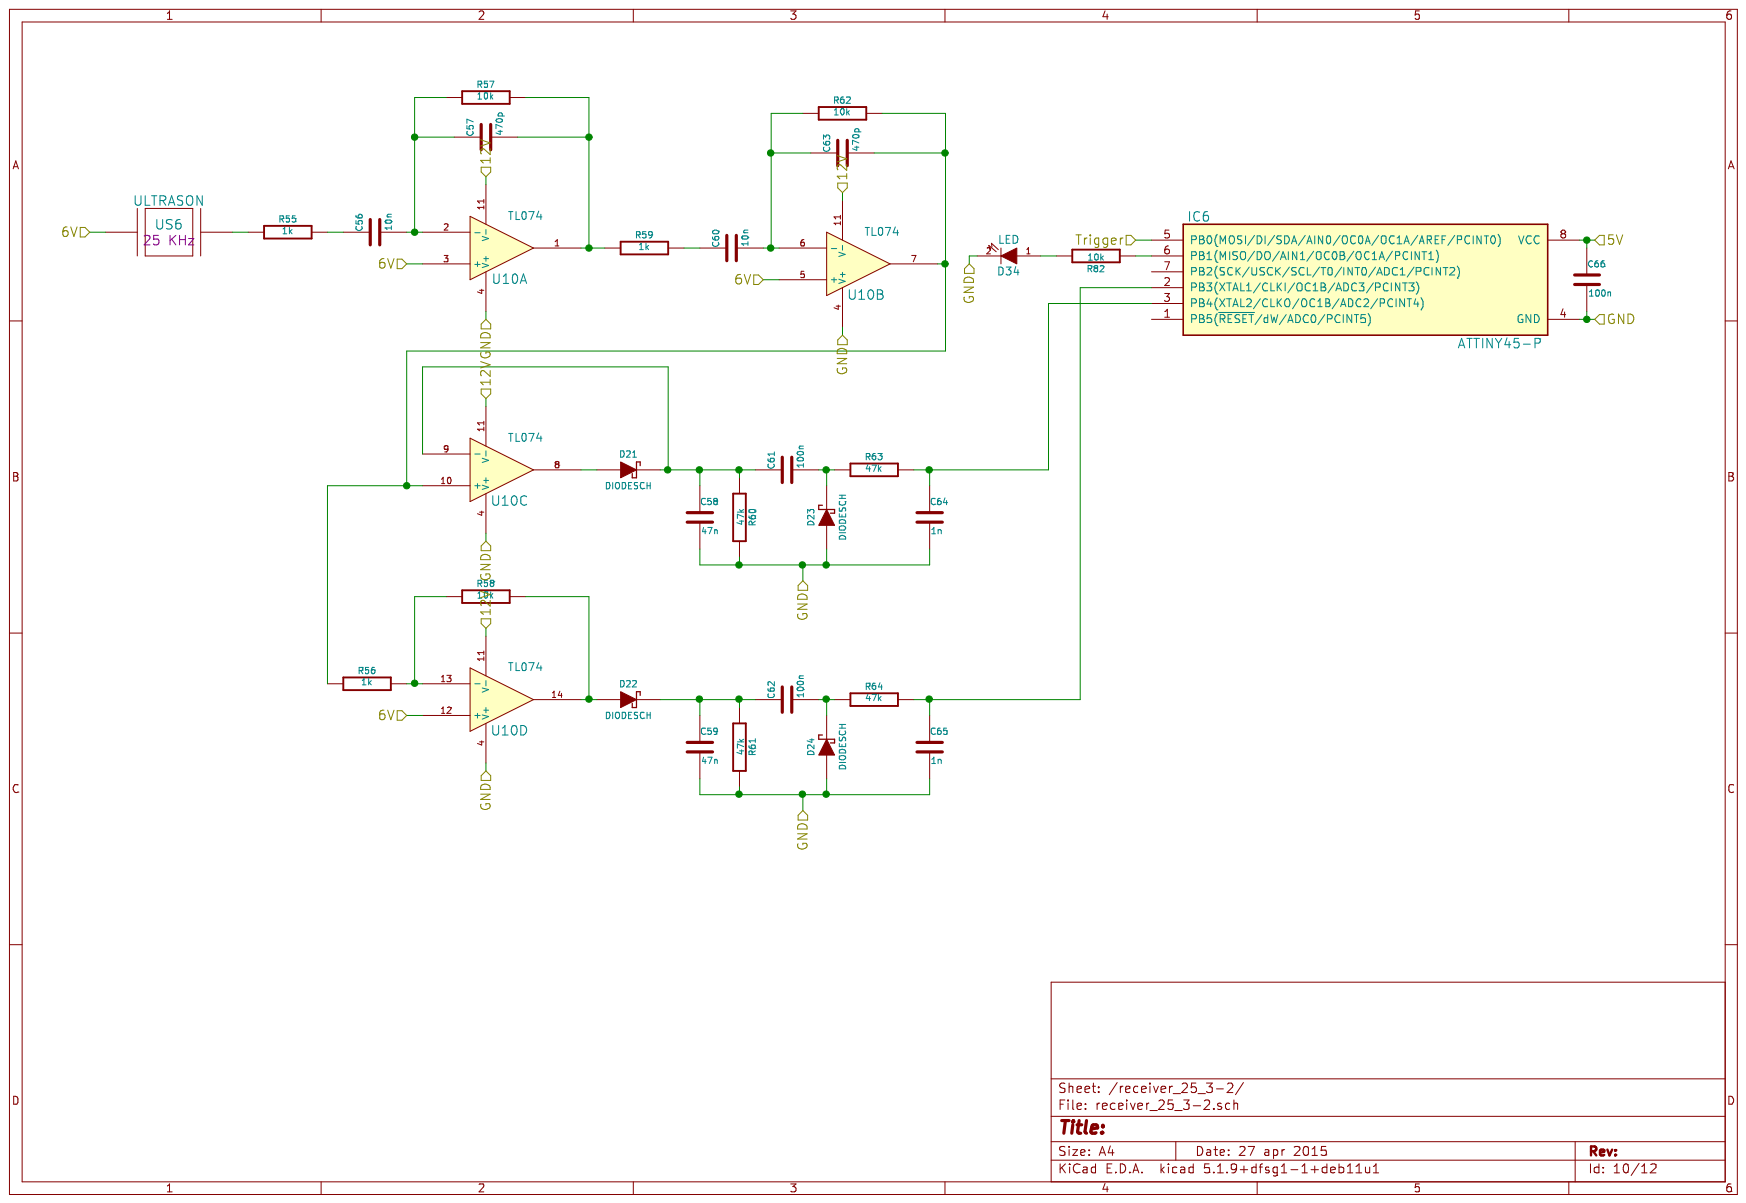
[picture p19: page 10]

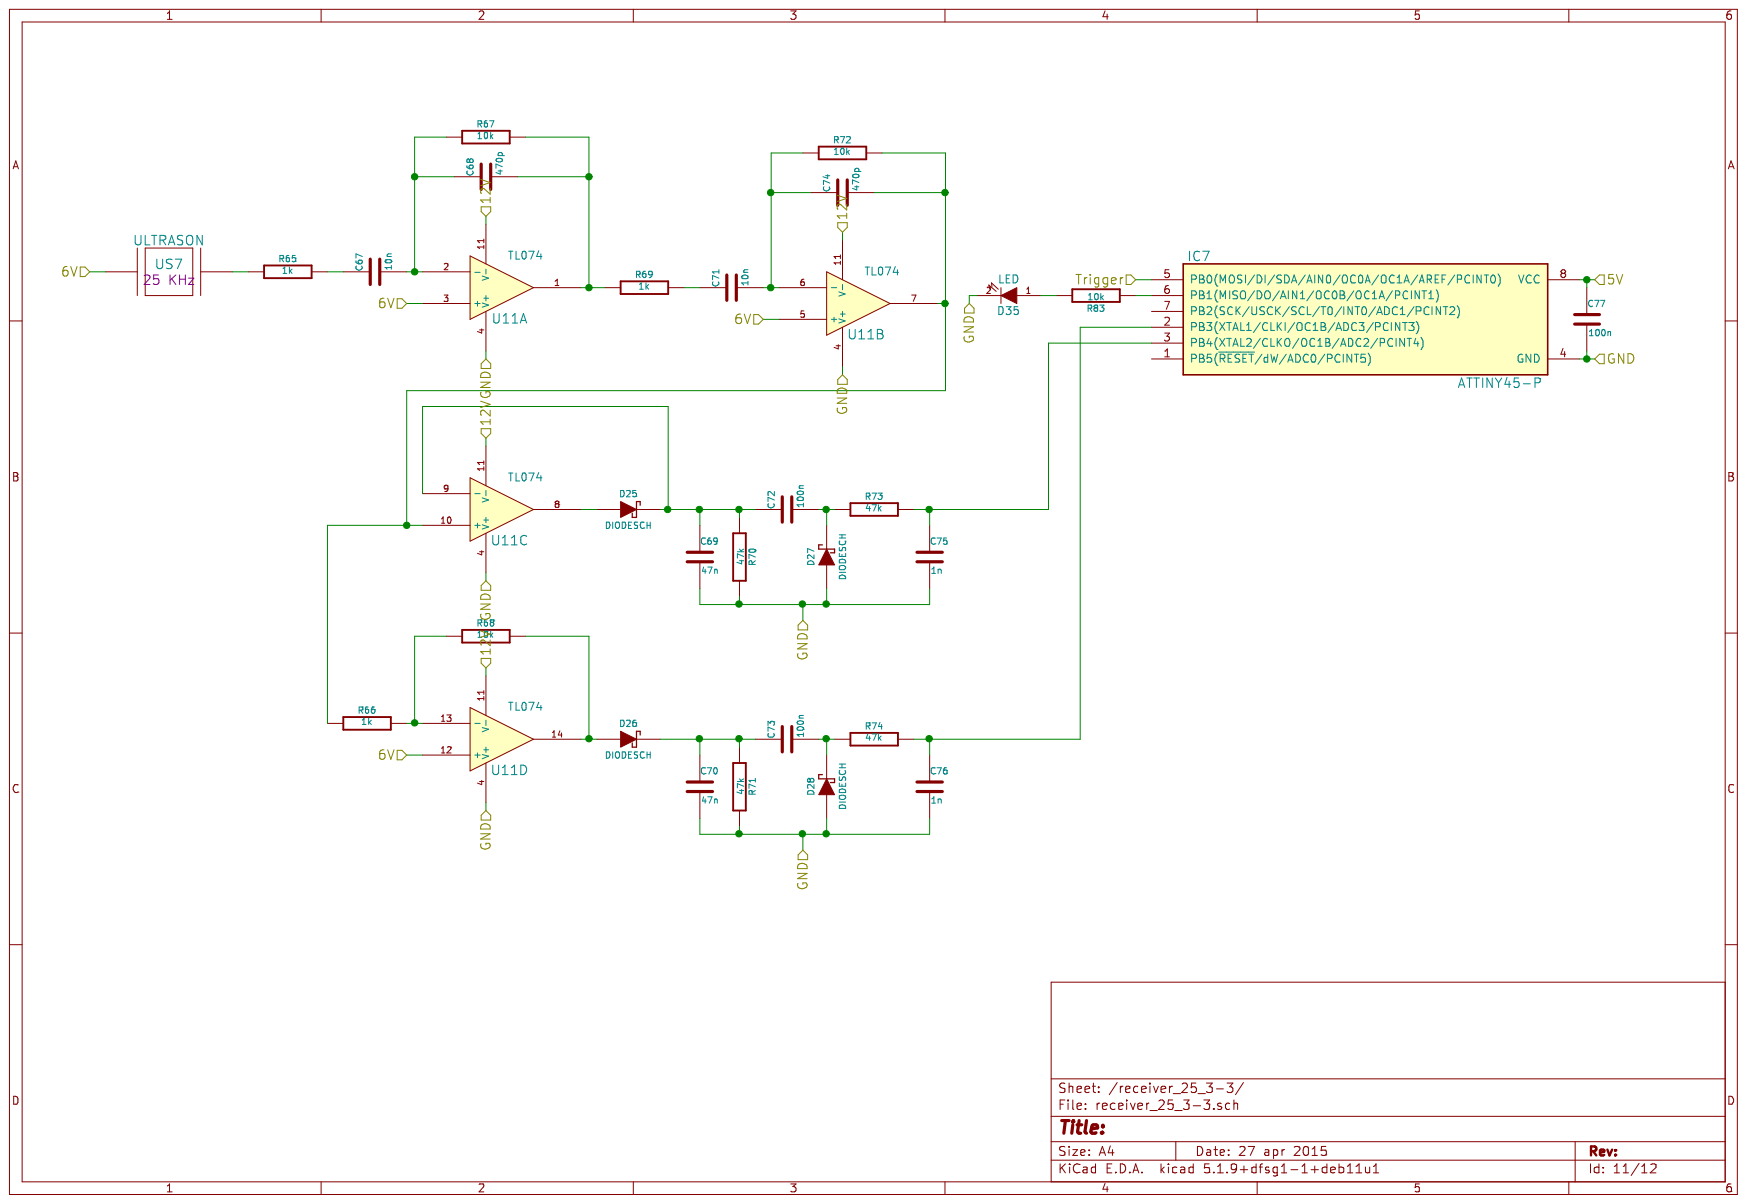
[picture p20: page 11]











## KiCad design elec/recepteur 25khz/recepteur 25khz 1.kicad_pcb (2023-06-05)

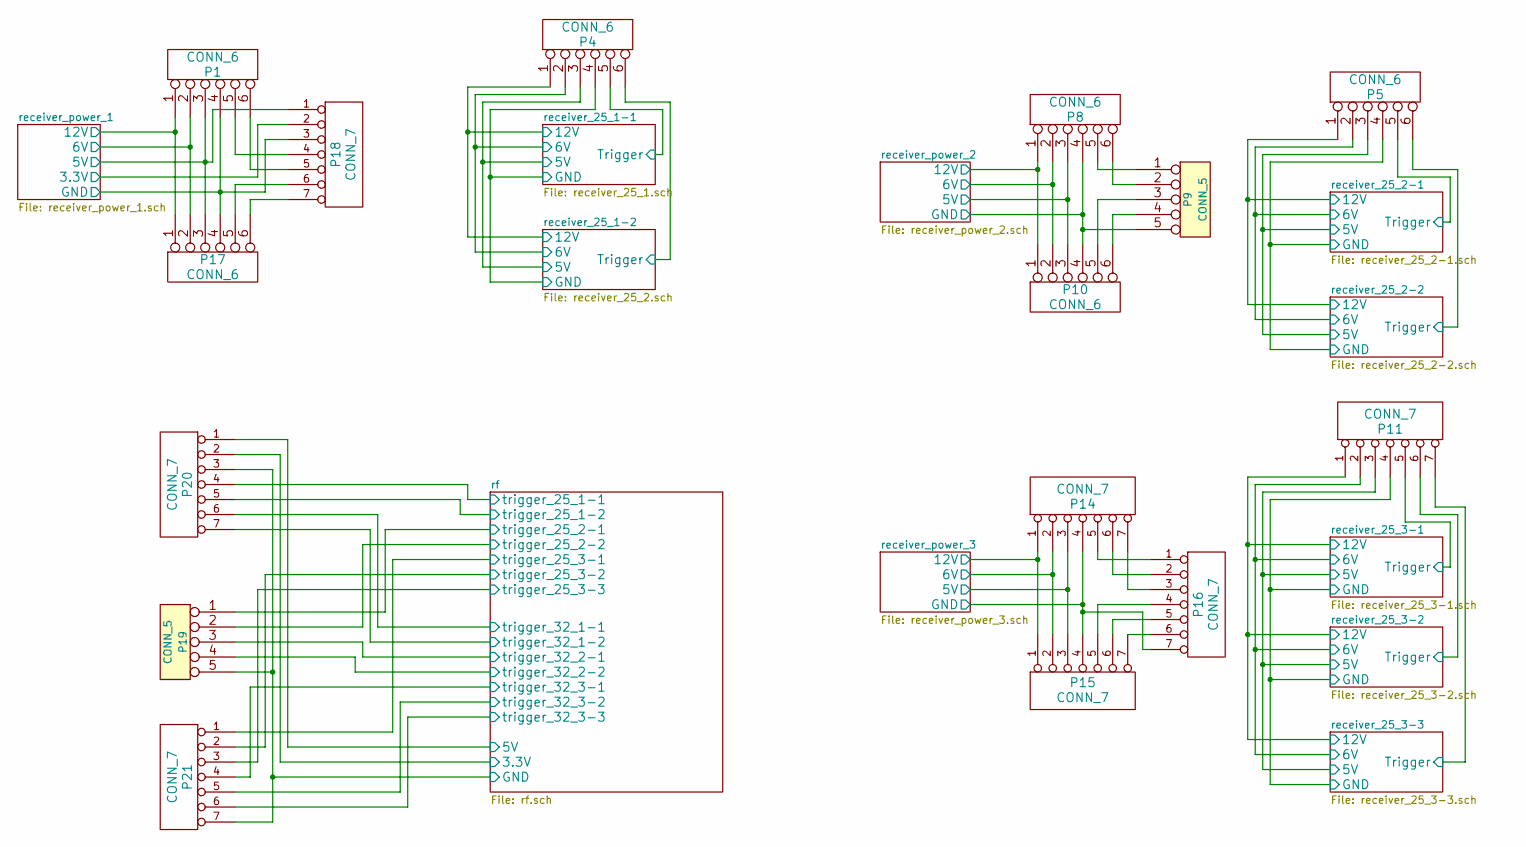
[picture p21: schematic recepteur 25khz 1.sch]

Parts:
P1, P4, P5, P8, P10, P17: CONN_6
P9, P19: CONN_5
P11, P14, P15, P16, P18, P20, P21: CONN_7

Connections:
/receiver_25_1-1/5V: P4.3; also elsewhere on the board
/receiver_25_1-1/6V: P4.2; also elsewhere on the board
/receiver_25_1-1/12V: P4.1; also elsewhere on the board
/receiver_25_1-1/GND: P4.4; also elsewhere on the board
/receiver_25_1-1/Trigger: P4.5; also elsewhere on the board
/receiver_25_1-2/Trigger: P4.6; also elsewhere on the board
/receiver_25_2-1/5V: P5.3; also elsewhere on the board
/receiver_25_2-1/6V: P5.2; also elsewhere on the board
/receiver_25_2-1/12V: P5.1; also elsewhere on the board
/receiver_25_2-1/GND: P5.4; also elsewhere on the board
/receiver_25_2-1/Trigger: P5.5; also elsewhere on the board
/receiver_25_2-2/Trigger: P5.6; also elsewhere on the board
/receiver_25_3-1/5V: P11.3; also elsewhere on the board
/receiver_25_3-1/6V: P11.2; also elsewhere on the board
/receiver_25_3-1/12V: P11.1; also elsewhere on the board
/receiver_25_3-1/GND: P11.4; also elsewhere on the board
/receiver_25_3-1/Trigger: P11.5; also elsewhere on the board
/receiver_25_3-2/Trigger: P11.6; also elsewhere on the board
/receiver_25_3-3/Trigger: P11.7; also elsewhere on the board
/receiver_power_1/3.3V: P18.2; also elsewhere on the board
/receiver_power_1/5V: P1.3, P17.3, P18.1; also elsewhere on the board
/receiver_power_1/6V: P1.2, P17.2; also elsewhere on the board
/receiver_power_1/12V: P1.1, P17.1; also elsewhere on the board
/receiver_power_1/GND: P1.4, P17.4, P18.3; also elsewhere on the board
/receiver_power_2/5V: P8.3, P10.3; also elsewhere on the board
/receiver_power_2/6V: P8.2, P10.2; also elsewhere on the board
/receiver_power_2/12V: P8.1, P10.1; also elsewhere on the board
/receiver_power_2/GND: P8.4, P9.5, P10.4; also elsewhere on the board
/receiver_power_3/5V: P14.3, P15.3; also elsewhere on the board
/receiver_power_3/6V: P14.2, P15.2; also elsewhere on the board
/receiver_power_3/12V: P14.1, P15.1; also elsewhere on the board
/receiver_power_3/GND: P14.4, P15.4, P16.7; also elsewhere on the board
/rf/3.3V: P20.2; also elsewhere on the board
/rf/5V: P20.1; also elsewhere on the board
/rf/GND: P19.5, P20.3, P21.7; also elsewhere on the board
/rf/trigger_25_1-1: P20.4; also elsewhere on the board
/rf/trigger_25_1-2: P20.5; also elsewhere on the board
/rf/trigger_25_2-1: P19.1; also elsewhere on the board
/rf/trigger_25_2-2: P19.2; also elsewhere on the board
/rf/trigger_25_3-1: P21.1; also elsewhere on the board
/rf/trigger_25_3-2: P21.2; also elsewhere on the board
/rf/trigger_25_3-3: P21.3; also elsewhere on the board
/rf/trigger_32_1-1: P20.6; also elsewhere on the board
/rf/trigger_32_1-2: P20.7; also elsewhere on the board
/rf/trigger_32_2-1: P19.3; also elsewhere on the board
/rf/trigger_32_2-2: P19.4; also elsewhere on the board
/rf/trigger_32_3-1: P21.4; also elsewhere on the board
/rf/trigger_32_3-2: P21.5; also elsewhere on the board
/rf/trigger_32_3-3: P21.6; also elsewhere on the board
unnamed: P1.5, P18.4
unnamed: P1.6, P18.5
unnamed: P8.5, P9.1
unnamed: P8.6, P9.2
unnamed: P9.3, P10.5
unnamed: P9.4, P10.6
unnamed: P14.5, P16.1
unnamed: P14.6, P16.2
unnamed: P14.7, P16.3
unnamed: P15.5, P16.4
unnamed: P15.6, P16.5
unnamed: P15.7, P16.6
unnamed: P17.5, P18.6
unnamed: P17.6, P18.7

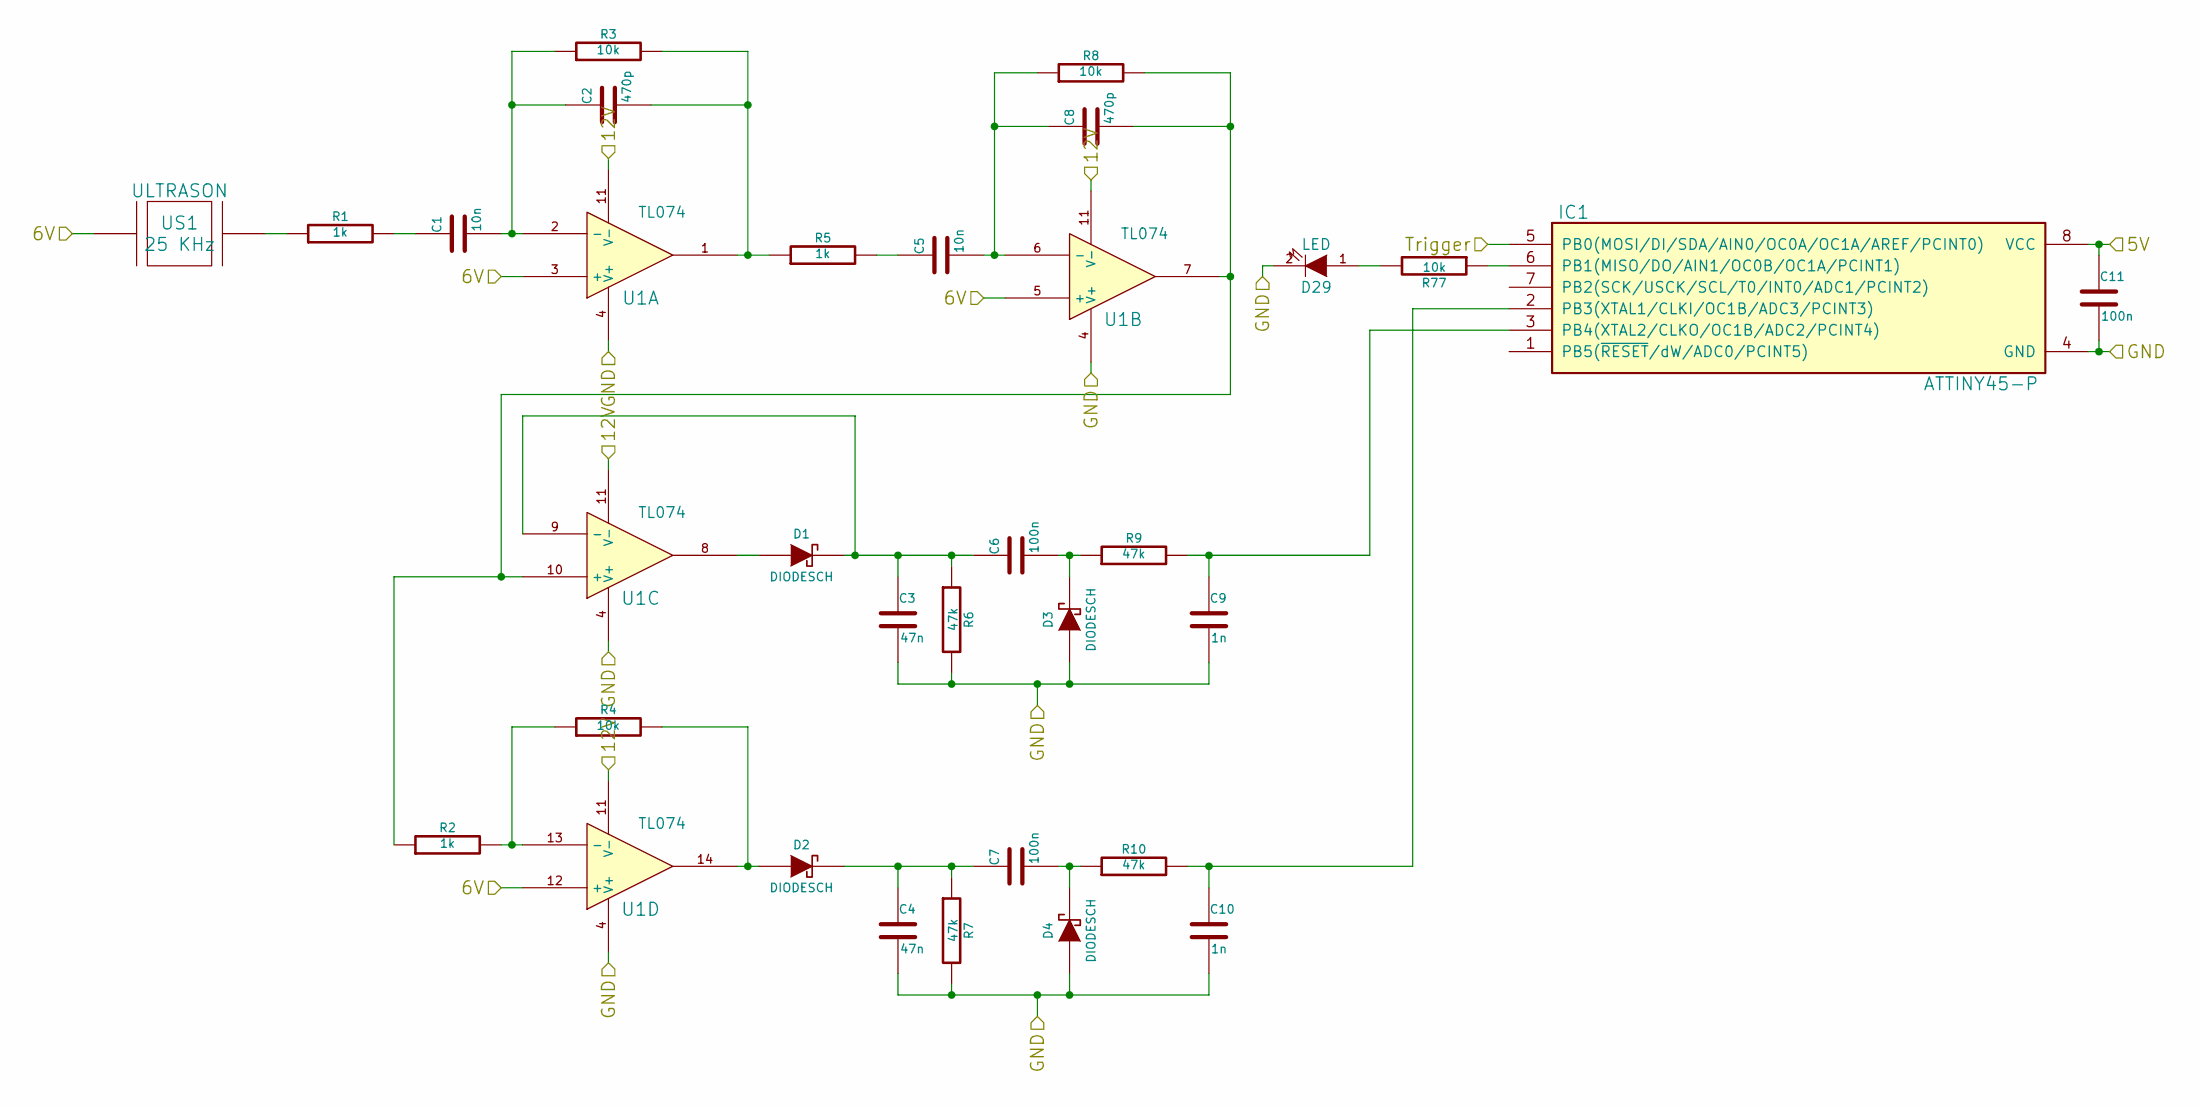
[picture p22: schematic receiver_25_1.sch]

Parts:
C1, C5: 10n
C2, C8: 470p
C3, C4: 47n
C6, C7, C11: 100n
C9, C10: 1n
D1, D2, D3, D4: DIODESCH
D29: LED
IC1: ATTINY45-P; DIP8
R1, R2, R5: 1k
R3, R4, R8, R77: 10k
R6, R7, R9, R10: 47k
U1: TL074
US1: ULTRASON

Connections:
/receiver_25_1-1/5V: C11.1, IC1.8 (VCC); also elsewhere on the board
/receiver_25_1-1/6V: U1.3 (+), U1.5 (+), U1.12 (+), US1.1; also elsewhere on the board
/receiver_25_1-1/12V: U1.11 (V-); also elsewhere on the board
/receiver_25_1-1/GND: C3.2, C4.2, C9.2, C10.2, C11.2, D3.1 (A), D4.1 (A), D29.2 (K), IC1.4 (GND), R6.2, R7.2, U1.4 (V+); also elsewhere on the board
/receiver_25_1-1/Trigger: IC1.5 (PB0(MOSI/DI/SDA/AIN0/OC0A/OC1A/AREF/PCI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); also elsewhere on the board
unnamed: C1.1, R1.2
unnamed: C1.2, C2.1, R3.1, U1.2 (-)
unnamed: C2.2, R3.2, R5.1, U1.1
unnamed: C3.1, C6.1, D1.2 (K), R6.1, U1.9 (-)
unnamed: C4.1, C7.1, D2.2 (K), R7.1
unnamed: C5.1, R5.2
unnamed: C5.2, C8.1, R8.1, U1.6 (-)
unnamed: C6.2, D3.2 (K), R9.1
unnamed: C7.2, D4.2 (K), R10.1
unnamed: C8.2, R2.1, R8.2, U1.7, U1.10 (+)
unnamed: C9.1, IC1.3 (PB4(XTAL2/CLKO/OC1B/ADC2/PCINT4)), R9.2
unnamed: C10.1, IC1.2 (PB3(XTAL1/CLKI/OC1B/ADC3/PCINT3)), R10.2
unnamed: D1.1 (A), U1.8
unnamed: D2.1 (A), R4.2, U1.14
unnamed: D29.1 (A), R77.2
unnamed: IC1.6 (PB1(MISO/DO/AIN1/OC0B/OC1A/PCINT1)), R77.1
unnamed: R1.1, US1.2
unnamed: R2.2, R4.1, U1.13 (-)

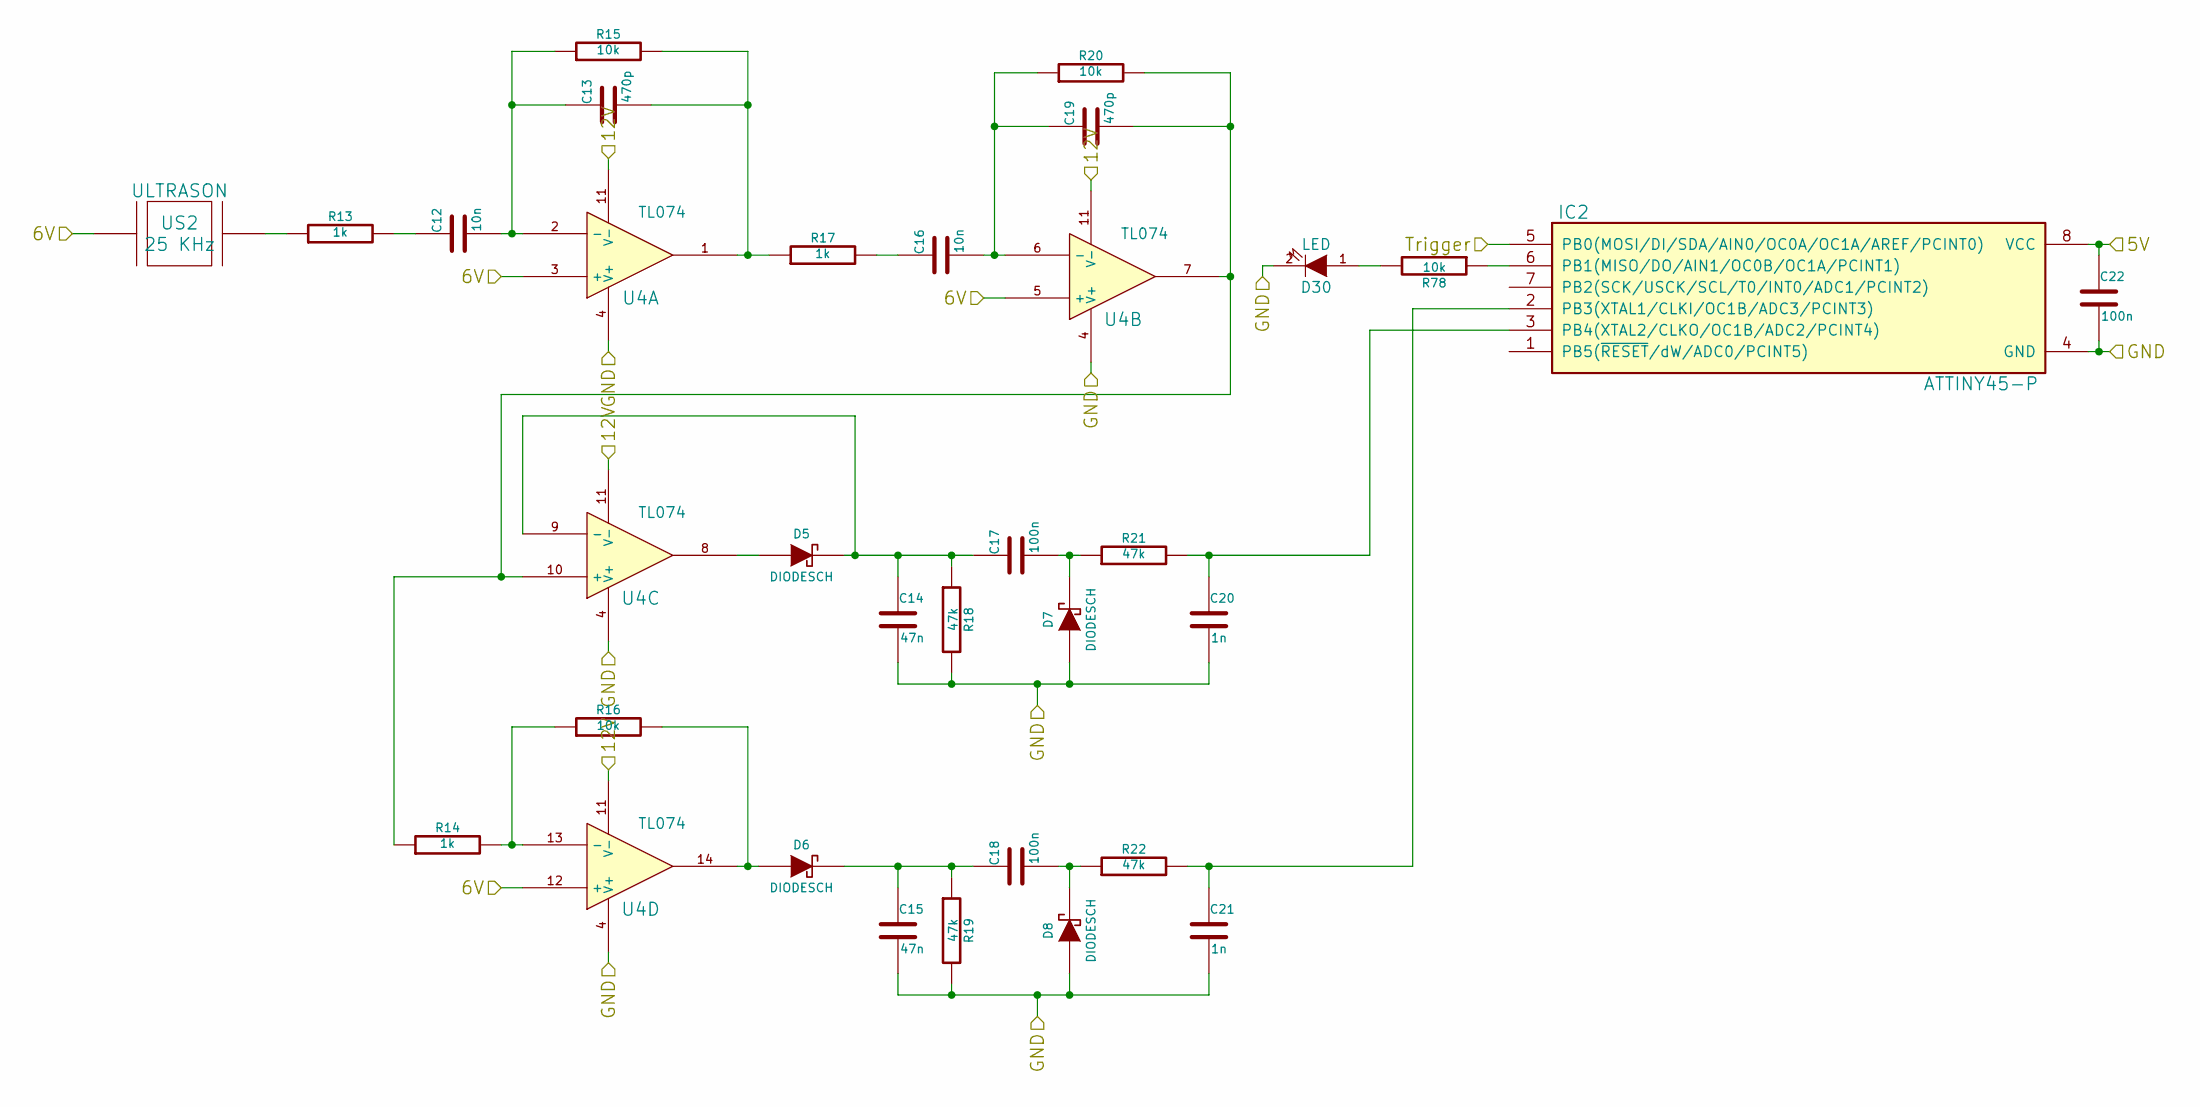
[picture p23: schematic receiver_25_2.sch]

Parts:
C12, C16: 10n
C13, C19: 470p
C14, C15: 47n
C17, C18, C22: 100n
C20, C21: 1n
D5, D6, D7, D8: DIODESCH
D30: LED
IC2: ATTINY45-P; DIP8
R13, R14, R17: 1k
R15, R16, R20, R78: 10k
R18, R19, R21, R22: 47k
U4: TL074
US2: ULTRASON

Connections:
/receiver_25_1-1/5V: C22.1, IC2.8 (VCC); also elsewhere on the board
/receiver_25_1-1/6V: U4.3 (+), U4.5 (+), U4.12 (+), US2.1; also elsewhere on the board
/receiver_25_1-1/12V: U4.11 (V-); also elsewhere on the board
/receiver_25_1-1/GND: C14.2, C15.2, C20.2, C21.2, C22.2, D7.1 (A), D8.1 (A), D30.2 (K), IC2.4 (GND), R18.2, R19.2, U4.4 (V+); also elsewhere on the board
/receiver_25_1-2/Trigger: IC2.5 (PB0(MOSI/DI/SDA/AIN0/OC0A/OC1A/AREF/PCI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); also elsewhere on the board
unnamed: C12.1, R13.2
unnamed: C12.2, C13.1, R15.1, U4.2 (-)
unnamed: C13.2, R15.2, R17.1, U4.1
unnamed: C14.1, C17.1, D5.2 (K), R18.1, U4.9 (-)
unnamed: C15.1, C18.1, D6.2 (K), R19.1
unnamed: C16.1, R17.2
unnamed: C16.2, C19.1, R20.1, U4.6 (-)
unnamed: C17.2, D7.2 (K), R21.1
unnamed: C18.2, D8.2 (K), R22.1
unnamed: C19.2, R14.1, R20.2, U4.7, U4.10 (+)
unnamed: C20.1, IC2.3 (PB4(XTAL2/CLKO/OC1B/ADC2/PCINT4)), R21.2
unnamed: C21.1, IC2.2 (PB3(XTAL1/CLKI/OC1B/ADC3/PCINT3)), R22.2
unnamed: D5.1 (A), U4.8
unnamed: D6.1 (A), R16.2, U4.14
unnamed: D30.1 (A), R78.2
unnamed: IC2.6 (PB1(MISO/DO/AIN1/OC0B/OC1A/PCINT1)), R78.1
unnamed: R13.1, US2.2
unnamed: R14.2, R16.1, U4.13 (-)

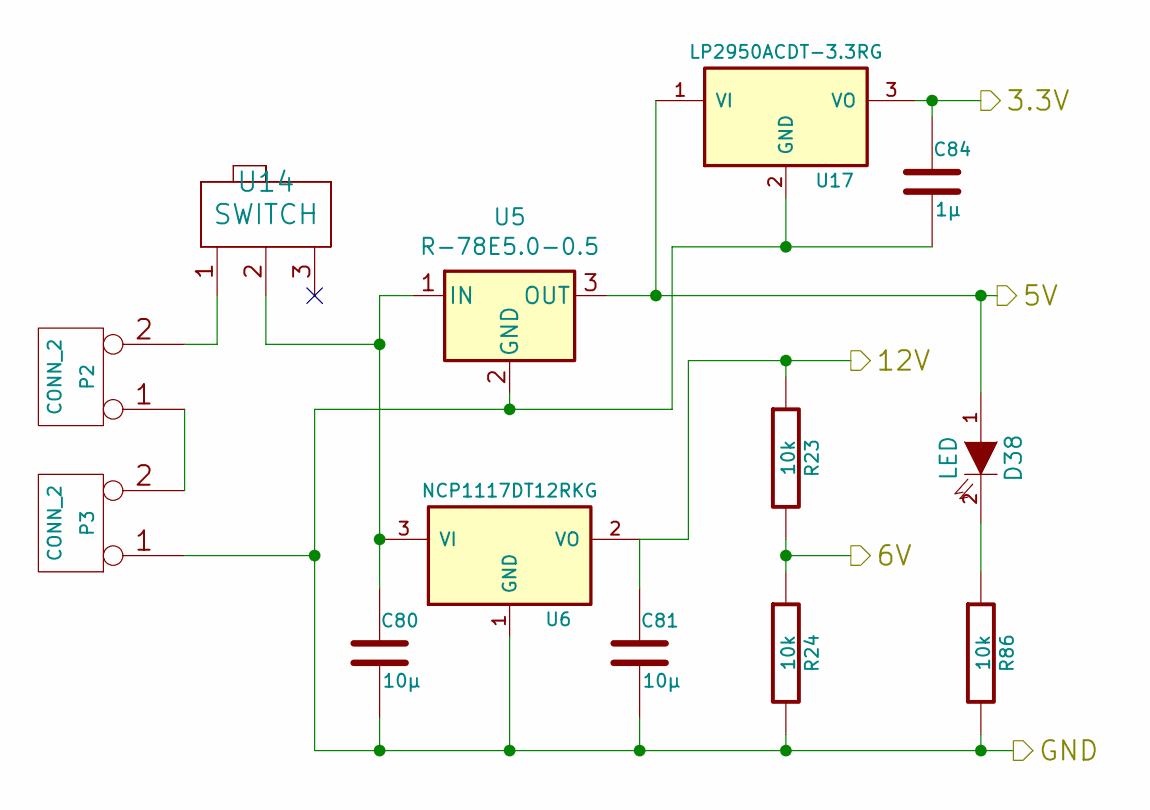
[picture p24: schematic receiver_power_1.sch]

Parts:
C80, C81: 10µ
C84: 1µ
D38: LED
P2, P3: CONN_2
R23, R24, R86: 10k
U5: R-78E5.0-0.5; Converter_DCDC_RECOM_R-78E-0.5_THT
U6: NCP1117DT12RKG
U14: SWITCH
U17: LP2950ACDT-3.3RG

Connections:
/receiver_power_1/3.3V: C84.1, U17.3 (VO); also elsewhere on the board
/receiver_power_1/5V: D38.1 (A), U5.3 (OUT), U17.1 (VI); also elsewhere on the board
/receiver_power_1/6V: R23.2, R24.1; also elsewhere on the board
/receiver_power_1/12V: C81.1, R23.1, U6.2 (VO); also elsewhere on the board
/receiver_power_1/GND: C80.2, C81.2, C84.2, P3.1, R24.2, R86.2, U5.2 (GND), U6.1 (GND), U17.2 (GND); also elsewhere on the board
unnamed: C80.1, U5.1 (IN), U6.3 (VI), U14.2
unnamed: D38.2 (K), R86.1
unnamed: P2.1, P3.2 (PM)
unnamed: P2.2 (PM), U14.1

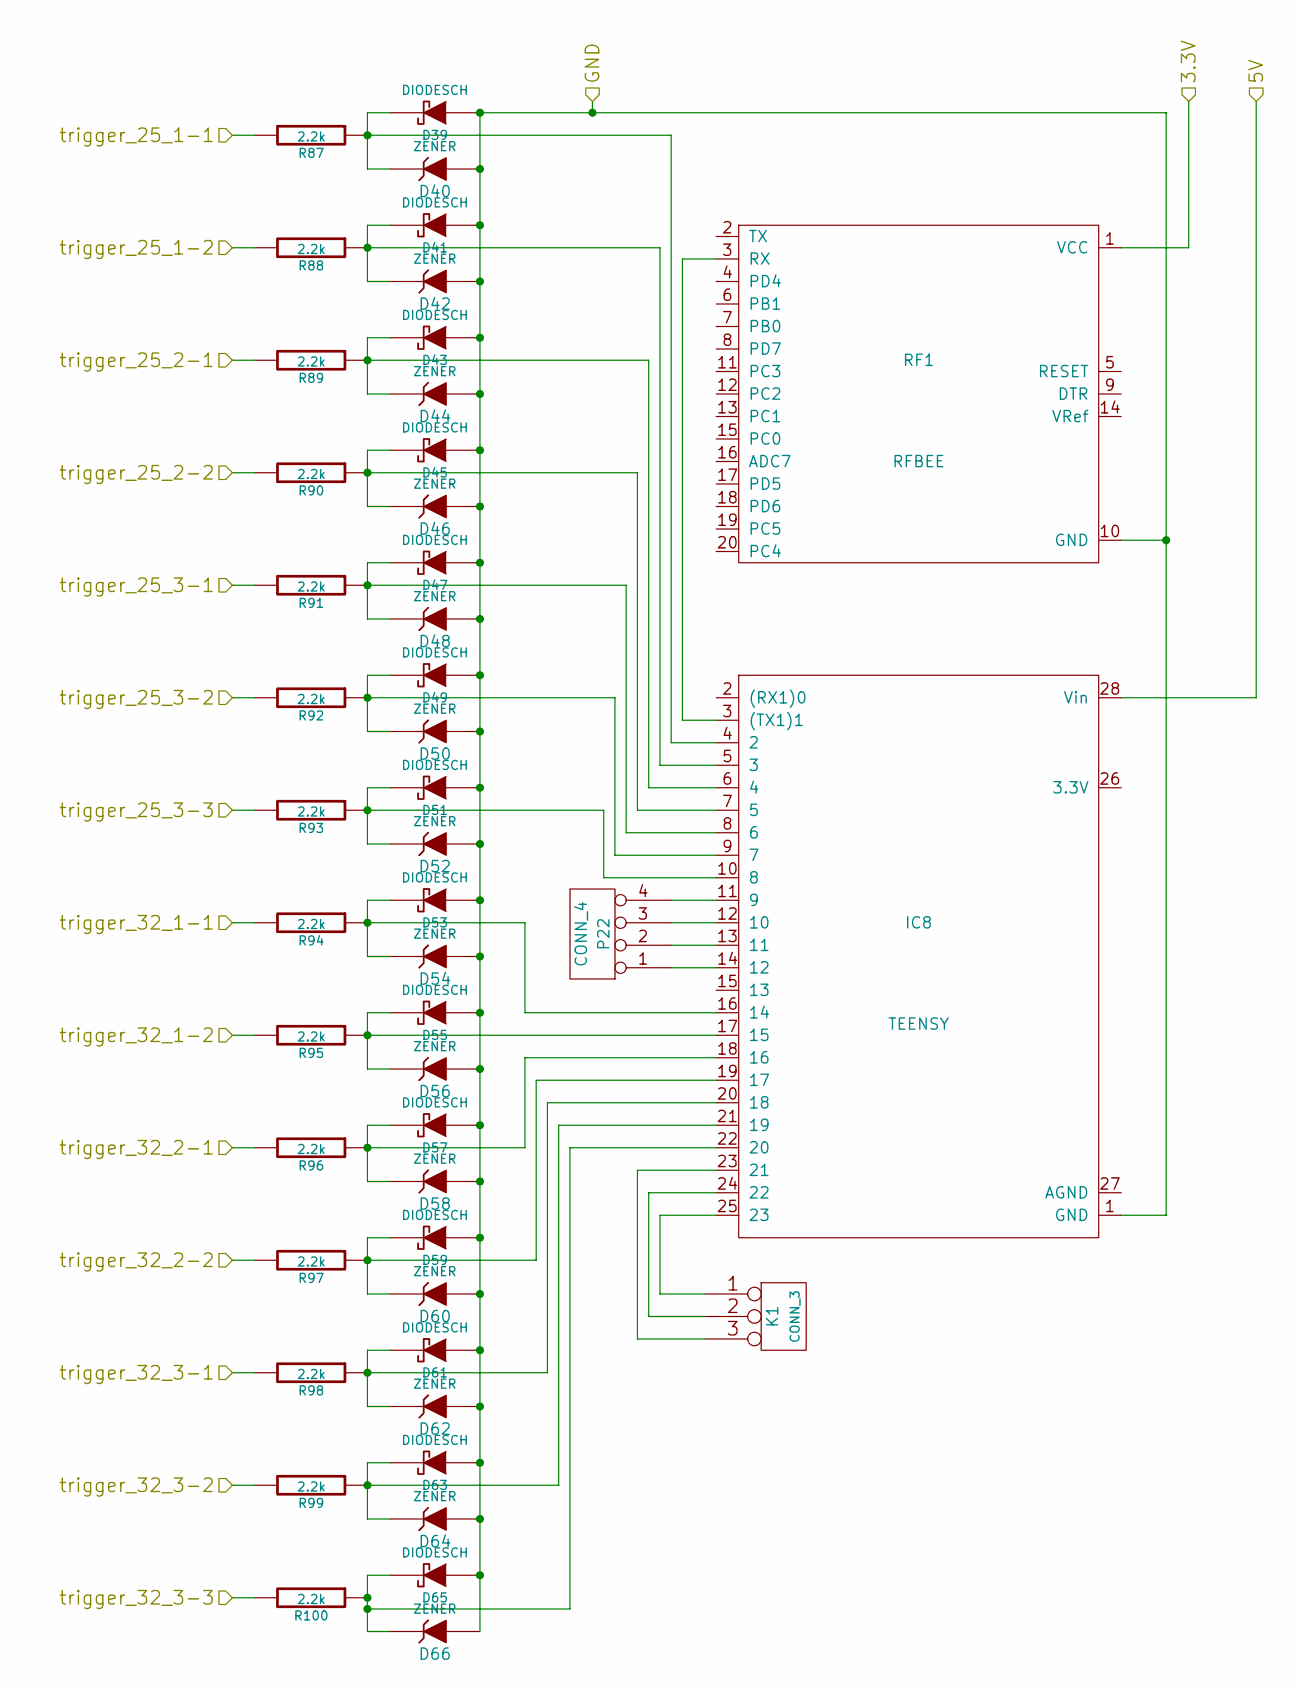
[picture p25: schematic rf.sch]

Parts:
D39, D41, D43, D45, D47, D49, D51, D53, D55, D57, D59, D61, D63, D65: DIODESCH
D40, D42, D44, D46, D48, D50, D52, D54, D56, D58, D60, D62, D64, D66: ZENER
IC8: TEENSY; Teensy
K1: CONN_3
P22: CONN_4
R87, R88, R89, R90, R91, R92, R93, R94, R95, R96, R97, R98, R99, R100: 2.2k
RF1: RFBEE; zigbee

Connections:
/rf/3.3V: RF1.1 (VCC); also elsewhere on the board
/rf/5V: IC8.28 (Vin); also elsewhere on the board
/rf/GND: D39.1 (A), D40.1 (A), D41.1 (A), D42.1 (A), D43.1 (A), D44.1 (A), D45.1 (A), D46.1 (A), D47.1 (A), D48.1 (A), D49.1 (A), D50.1 (A), D51.1 (A), D52.1 (A), D53.1 (A), D54.1 (A), D55.1 (A), D56.1 (A), D57.1 (A), D58.1 (A), D59.1 (A), D60.1 (A), D61.1 (A), D62.1 (A), D63.1 (A), D64.1 (A), D65.1 (A), D66.1 (A), IC8.1 (GND), RF1.10 (GND); also elsewhere on the board
/rf/trigger_25_1-1: R87.2; also elsewhere on the board
/rf/trigger_25_1-2: R88.2; also elsewhere on the board
/rf/trigger_25_2-1: R89.2; also elsewhere on the board
/rf/trigger_25_2-2: R90.2; also elsewhere on the board
/rf/trigger_25_3-1: R91.2; also elsewhere on the board
/rf/trigger_25_3-2: R92.2; also elsewhere on the board
/rf/trigger_25_3-3: R93.2; also elsewhere on the board
/rf/trigger_32_1-1: R94.2; also elsewhere on the board
/rf/trigger_32_1-2: R95.2; also elsewhere on the board
/rf/trigger_32_2-1: R96.2; also elsewhere on the board
/rf/trigger_32_2-2: R97.2; also elsewhere on the board
/rf/trigger_32_3-1: R98.2; also elsewhere on the board
/rf/trigger_32_3-2: R99.2; also elsewhere on the board
/rf/trigger_32_3-3: R100.2; also elsewhere on the board
unnamed: D39.2 (K), D40.2 (K), IC8.4 (2), R87.1
unnamed: D41.2 (K), D42.2 (K), IC8.5 (3), R88.1
unnamed: D43.2 (K), D44.2 (K), IC8.6 (4), R89.1
unnamed: D45.2 (K), D46.2 (K), IC8.7 (5), R90.1
unnamed: D47.2 (K), D48.2 (K), IC8.8 (6), R91.1
unnamed: D49.2 (K), D50.2 (K), IC8.9 (7), R92.1
unnamed: D51.2 (K), D52.2 (K), IC8.10 (8), R93.1
unnamed: D53.2 (K), D54.2 (K), IC8.16 (14), R94.1
unnamed: D55.2 (K), D56.2 (K), IC8.17 (15), R95.1
unnamed: D57.2 (K), D58.2 (K), IC8.18 (16), R96.1
unnamed: D59.2 (K), D60.2 (K), IC8.19 (17), R97.1
unnamed: D61.2 (K), D62.2 (K), IC8.20 (18), R98.1
unnamed: D63.2 (K), D64.2 (K), IC8.21 (19), R99.1
unnamed: D65.2 (K), D66.2 (K), IC8.22 (20), R100.1
unnamed: IC8.3 ((TX1)1), RF1.3 (RX)
unnamed: IC8.11 (9), P22.4
unnamed: IC8.12 (10), P22.3
unnamed: IC8.13 (11), P22.2
unnamed: IC8.14 (12), P22.1
unnamed: IC8.23 (21), K1.3
unnamed: IC8.24 (22), K1.2 (PM)
unnamed: IC8.25 (23), K1.1

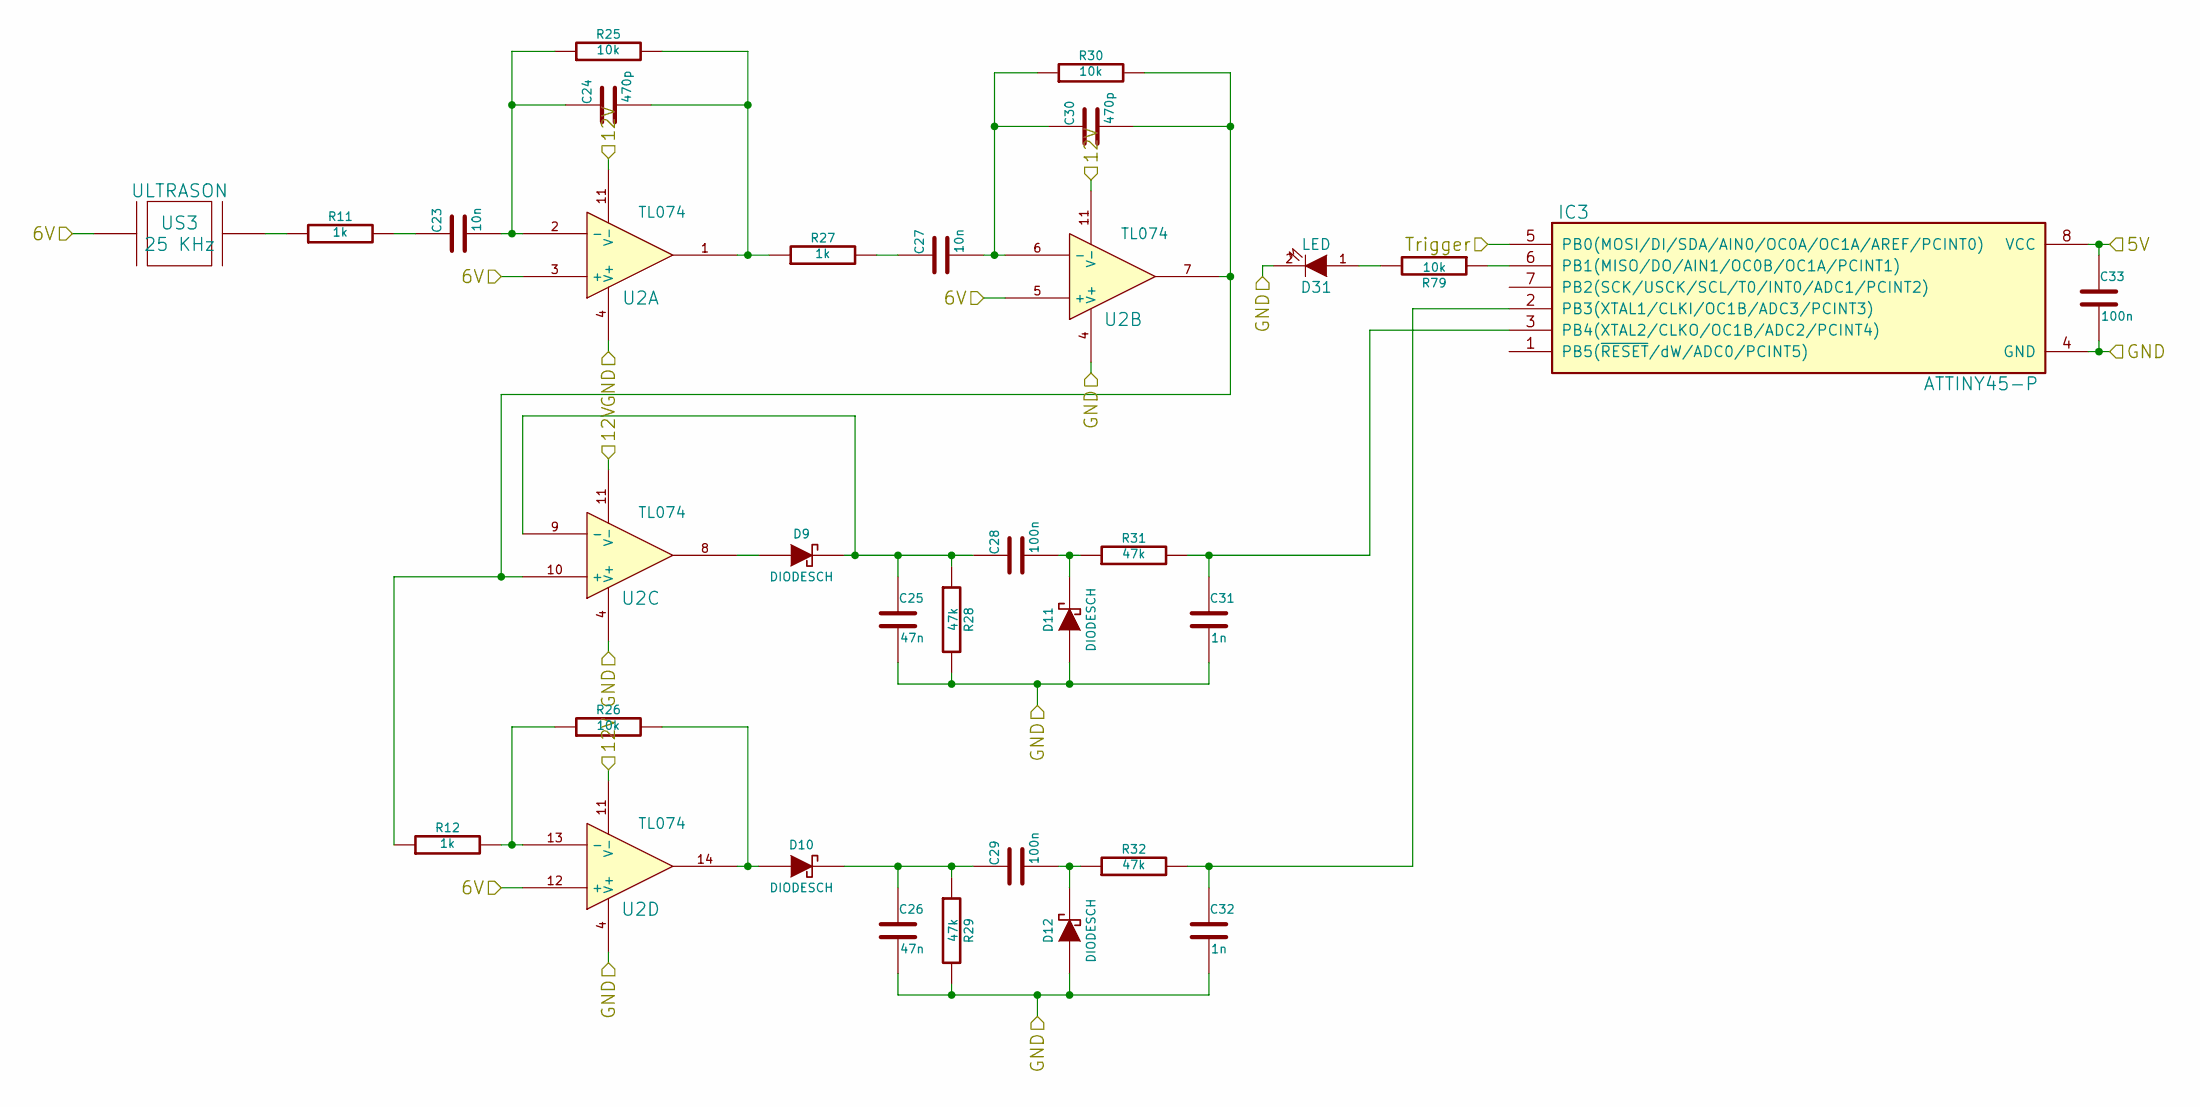
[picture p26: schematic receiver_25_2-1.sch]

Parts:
C23, C27: 10n
C24, C30: 470p
C25, C26: 47n
C28, C29, C33: 100n
C31, C32: 1n
D9, D10, D11, D12: DIODESCH
D31: LED
IC3: ATTINY45-P; DIP8
R11, R12, R27: 1k
R25, R26, R30, R79: 10k
R28, R29, R31, R32: 47k
U2: TL074
US3: ULTRASON

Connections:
/receiver_25_2-1/5V: C33.1, IC3.8 (VCC); also elsewhere on the board
/receiver_25_2-1/6V: U2.3 (+), U2.5 (+), U2.12 (+), US3.1; also elsewhere on the board
/receiver_25_2-1/12V: U2.11 (V-); also elsewhere on the board
/receiver_25_2-1/GND: C25.2, C26.2, C31.2, C32.2, C33.2, D11.1 (A), D12.1 (A), D31.2 (K), IC3.4 (GND), R28.2, R29.2, U2.4 (V+); also elsewhere on the board
/receiver_25_2-1/Trigger: IC3.5 (PB0(MOSI/DI/SDA/AIN0/OC0A/OC1A/AREF/PCI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); also elsewhere on the board
unnamed: C23.1, R11.2
unnamed: C23.2, C24.1, R25.1, U2.2 (-)
unnamed: C24.2, R25.2, R27.1, U2.1
unnamed: C25.1, C28.1, D9.2 (K), R28.1, U2.9 (-)
unnamed: C26.1, C29.1, D10.2 (K), R29.1
unnamed: C27.1, R27.2
unnamed: C27.2, C30.1, R30.1, U2.6 (-)
unnamed: C28.2, D11.2 (K), R31.1
unnamed: C29.2, D12.2 (K), R32.1
unnamed: C30.2, R12.1, R30.2, U2.7, U2.10 (+)
unnamed: C31.1, IC3.3 (PB4(XTAL2/CLKO/OC1B/ADC2/PCINT4)), R31.2
unnamed: C32.1, IC3.2 (PB3(XTAL1/CLKI/OC1B/ADC3/PCINT3)), R32.2
unnamed: D9.1 (A), U2.8
unnamed: D10.1 (A), R26.2, U2.14
unnamed: D31.1 (A), R79.2
unnamed: IC3.6 (PB1(MISO/DO/AIN1/OC0B/OC1A/PCINT1)), R79.1
unnamed: R11.1, US3.2
unnamed: R12.2, R26.1, U2.13 (-)

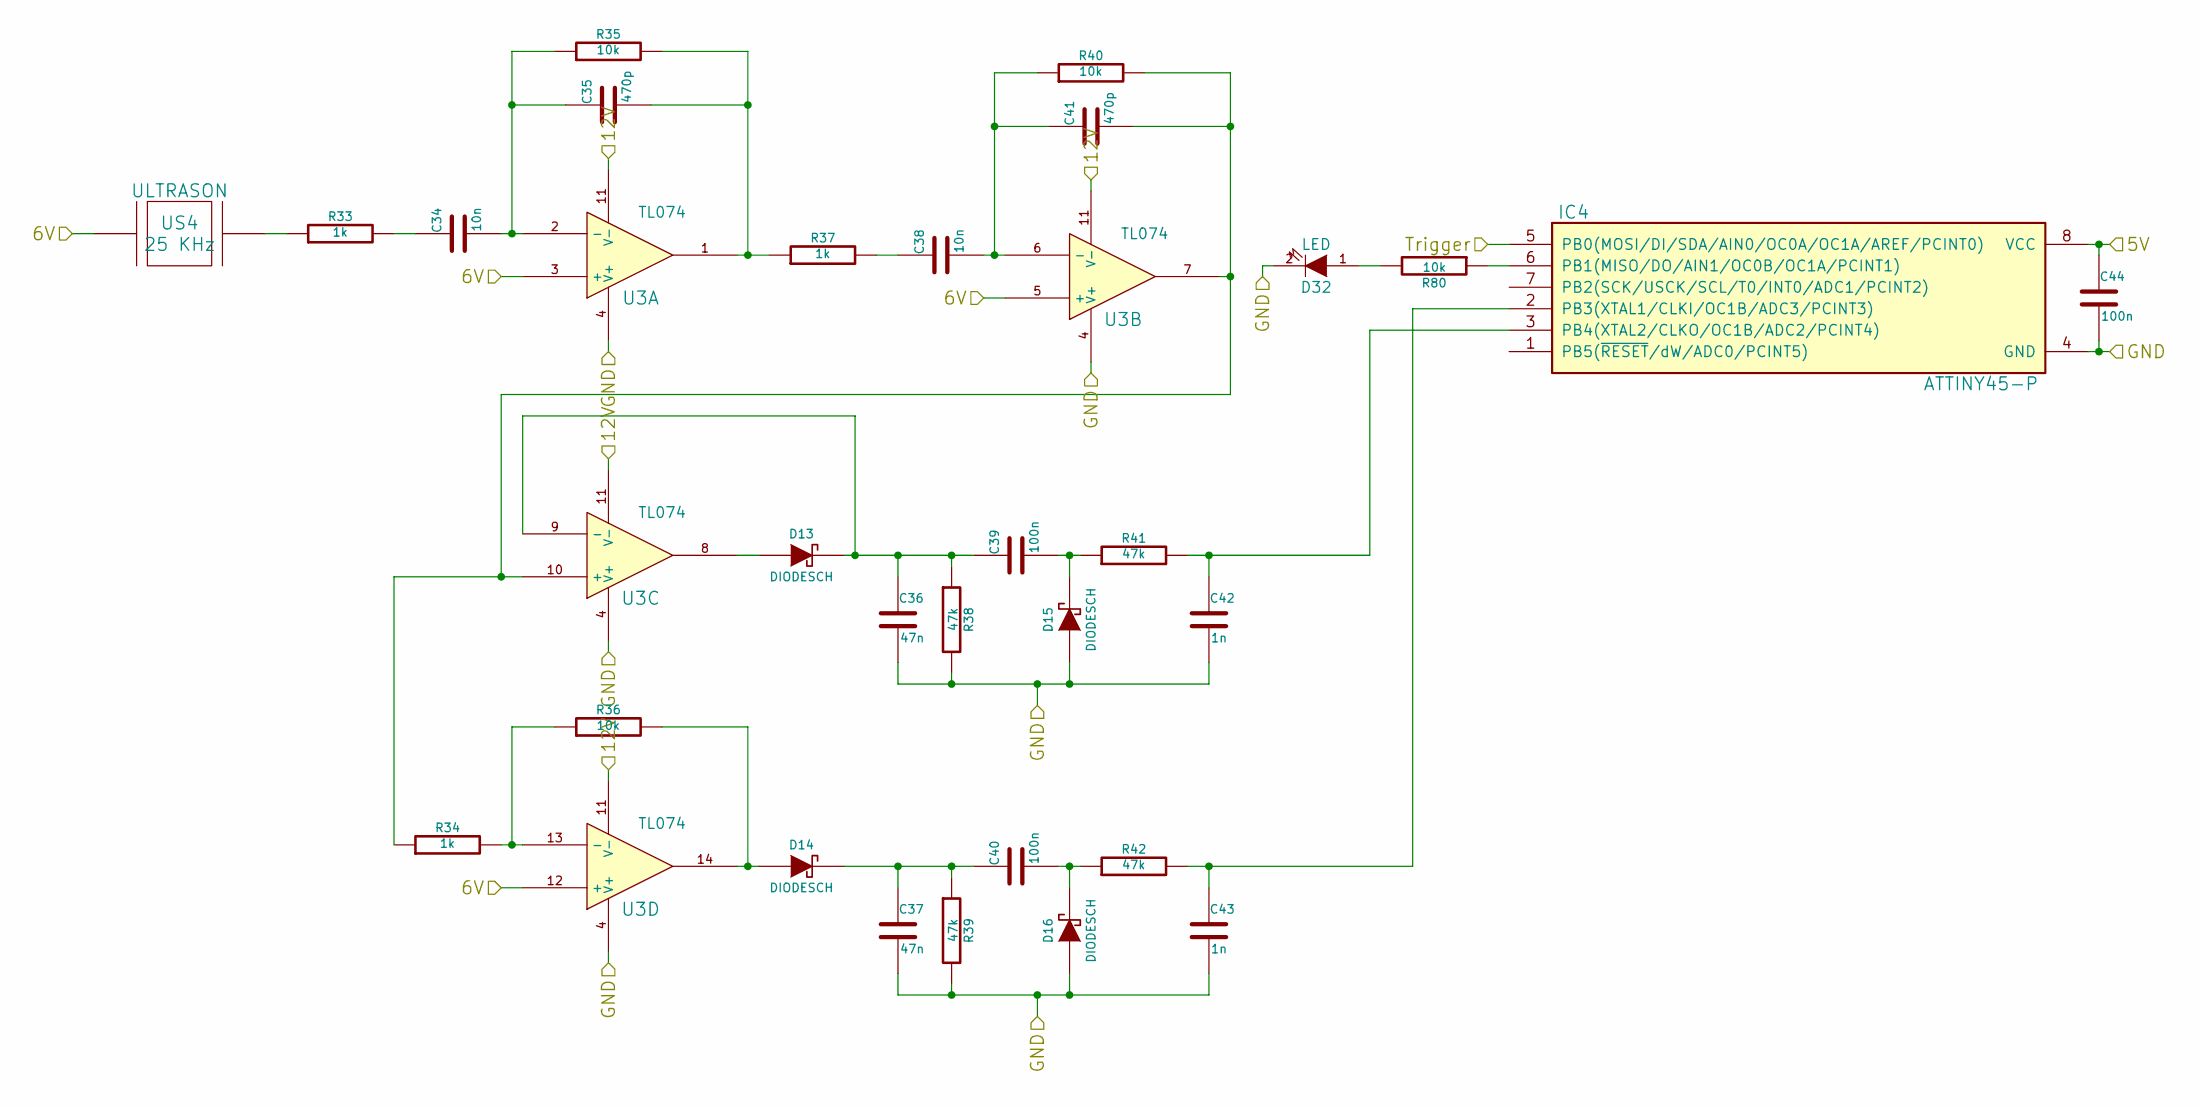
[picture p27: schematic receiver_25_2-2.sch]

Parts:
C34, C38: 10n
C35, C41: 470p
C36, C37: 47n
C39, C40, C44: 100n
C42, C43: 1n
D13, D14, D15, D16: DIODESCH
D32: LED
IC4: ATTINY45-P; DIP8
R33, R34, R37: 1k
R35, R36, R40, R80: 10k
R38, R39, R41, R42: 47k
U3: TL074
US4: ULTRASON

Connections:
/receiver_25_2-1/5V: C44.1, IC4.8 (VCC); also elsewhere on the board
/receiver_25_2-1/6V: U3.3 (+), U3.5 (+), U3.12 (+), US4.1; also elsewhere on the board
/receiver_25_2-1/12V: U3.11 (V-); also elsewhere on the board
/receiver_25_2-1/GND: C36.2, C37.2, C42.2, C43.2, C44.2, D15.1 (A), D16.1 (A), D32.2 (K), IC4.4 (GND), R38.2, R39.2, U3.4 (V+); also elsewhere on the board
/receiver_25_2-2/Trigger: IC4.5 (PB0(MOSI/DI/SDA/AIN0/OC0A/OC1A/AREF/PCI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); also elsewhere on the board
unnamed: C34.1, R33.2
unnamed: C34.2, C35.1, R35.1, U3.2 (-)
unnamed: C35.2, R35.2, R37.1, U3.1
unnamed: C36.1, C39.1, D13.2 (K), R38.1, U3.9 (-)
unnamed: C37.1, C40.1, D14.2 (K), R39.1
unnamed: C38.1, R37.2
unnamed: C38.2, C41.1, R40.1, U3.6 (-)
unnamed: C39.2, D15.2 (K), R41.1
unnamed: C40.2, D16.2 (K), R42.1
unnamed: C41.2, R34.1, R40.2, U3.7, U3.10 (+)
unnamed: C42.1, IC4.3 (PB4(XTAL2/CLKO/OC1B/ADC2/PCINT4)), R41.2
unnamed: C43.1, IC4.2 (PB3(XTAL1/CLKI/OC1B/ADC3/PCINT3)), R42.2
unnamed: D13.1 (A), U3.8
unnamed: D14.1 (A), R36.2, U3.14
unnamed: D32.1 (A), R80.2
unnamed: IC4.6 (PB1(MISO/DO/AIN1/OC0B/OC1A/PCINT1)), R80.1
unnamed: R33.1, US4.2
unnamed: R34.2, R36.1, U3.13 (-)

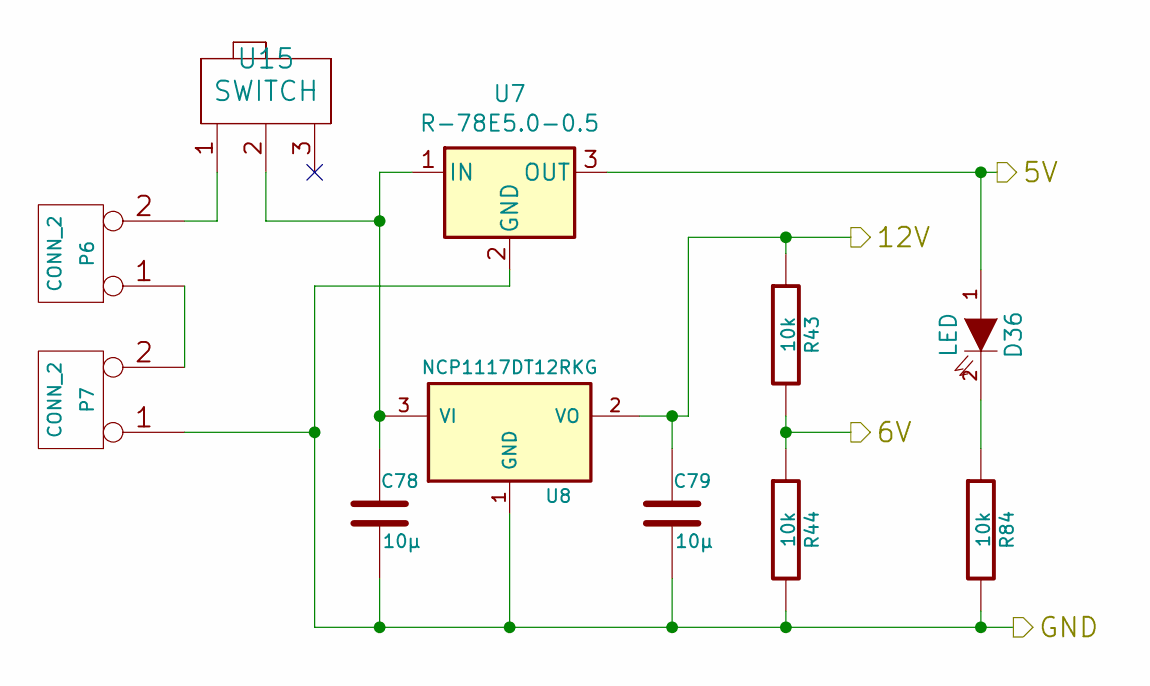
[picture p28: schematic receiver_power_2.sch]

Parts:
C78, C79: 10µ
D36: LED
P6, P7: CONN_2
R43, R44, R84: 10k
U7: R-78E5.0-0.5; Converter_DCDC_RECOM_R-78E-0.5_THT
U8: NCP1117DT12RKG
U15: SWITCH

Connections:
/receiver_power_2/5V: D36.1 (A), U7.3 (OUT); also elsewhere on the board
/receiver_power_2/6V: R43.2, R44.1; also elsewhere on the board
/receiver_power_2/12V: C79.1, R43.1, U8.2 (VO); also elsewhere on the board
/receiver_power_2/GND: C78.2, C79.2, P7.1, R44.2, R84.2, U7.2 (GND), U8.1 (GND); also elsewhere on the board
unnamed: C78.1, U7.1 (IN), U8.3 (VI), U15.2
unnamed: D36.2 (K), R84.1
unnamed: P6.1, P7.2 (PM)
unnamed: P6.2 (PM), U15.1

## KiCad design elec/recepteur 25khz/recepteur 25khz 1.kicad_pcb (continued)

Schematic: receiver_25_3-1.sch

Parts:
C45, C49: 10n
C46, C52: 470p
C47, C48: 47n
C50, C51, C55: 100n
C53, C54: 1n
D17, D18, D19, D20: DIODESCH
D33: LED
IC5: ATTINY45-P; DIP8
R45, R46, R49: 1k
R47, R48, R52, R81: 10k
R50, R51, R53, R54: 47k
U9: TL074
US5: ULTRASON

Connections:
/receiver_25_3-1/5V: C55.1, IC5.8 (VCC); also elsewhere on the board
/receiver_25_3-1/6V: U9.3 (+), U9.5 (+), U9.12 (+), US5.1; also elsewhere on the board
/receiver_25_3-1/12V: U9.11 (V-); also elsewhere on the board
/receiver_25_3-1/GND: C47.2, C48.2, C53.2, C54.2, C55.2, D19.1 (A), D20.1 (A), D33.2 (K), IC5.4 (GND), R50.2, R51.2, U9.4 (V+); also elsewhere on the board
/receiver_25_3-1/Trigger: IC5.5 (PB0(MOSI/DI/SDA/AIN0/OC0A/OC1A/AREF/PCI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); also elsewhere on the board
unnamed: C45.1, R45.2
unnamed: C45.2, C46.1, R47.1, U9.2 (-)
unnamed: C46.2, R47.2, R49.1, U9.1
unnamed: C47.1, C50.1, D17.2 (K), R50.1, U9.9 (-)
unnamed: C48.1, C51.1, D18.2 (K), R51.1
unnamed: C49.1, R49.2
unnamed: C49.2, C52.1, R52.1, U9.6 (-)
unnamed: C50.2, D19.2 (K), R53.1
unnamed: C51.2, D20.2 (K), R54.1
unnamed: C52.2, R46.1, R52.2, U9.7, U9.10 (+)
unnamed: C53.1, IC5.3 (PB4(XTAL2/CLKO/OC1B/ADC2/PCINT4)), R53.2
unnamed: C54.1, IC5.2 (PB3(XTAL1/CLKI/OC1B/ADC3/PCINT3)), R54.2
unnamed: D17.1 (A), U9.8
unnamed: D18.1 (A), R48.2, U9.14
unnamed: D33.1 (A), R81.2
unnamed: IC5.6 (PB1(MISO/DO/AIN1/OC0B/OC1A/PCINT1)), R81.1
unnamed: R45.1, US5.2
unnamed: R46.2, R48.1, U9.13 (-)

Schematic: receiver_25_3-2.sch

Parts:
C56, C60: 10n
C57, C63: 470p
C58, C59: 47n
C61, C62, C66: 100n
C64, C65: 1n
D21, D22, D23, D24: DIODESCH
D34: LED
IC6: ATTINY45-P; DIP8
R55, R56, R59: 1k
R57, R58, R62, R82: 10k
R60, R61, R63, R64: 47k
U10: TL074
US6: ULTRASON

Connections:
/receiver_25_3-1/5V: C66.1, IC6.8 (VCC); also elsewhere on the board
/receiver_25_3-1/6V: U10.3 (+), U10.5 (+), U10.12 (+), US6.1; also elsewhere on the board
/receiver_25_3-1/12V: U10.11 (V-); also elsewhere on the board
/receiver_25_3-1/GND: C58.2, C59.2, C64.2, C65.2, C66.2, D23.1 (A), D24.1 (A), D34.2 (K), IC6.4 (GND), R60.2, R61.2, U10.4 (V+); also elsewhere on the board
/receiver_25_3-2/Trigger: IC6.5 (PB0(MOSI/DI/SDA/AIN0/OC0A/OC1A/AREF/PCI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); also elsewhere on the board
unnamed: C56.1, R55.2
unnamed: C56.2, C57.1, R57.1, U10.2 (-)
unnamed: C57.2, R57.2, R59.1, U10.1
unnamed: C58.1, C61.1, D21.2 (K), R60.1, U10.9 (-)
unnamed: C59.1, C62.1, D22.2 (K), R61.1
unnamed: C60.1, R59.2
unnamed: C60.2, C63.1, R62.1, U10.6 (-)
unnamed: C61.2, D23.2 (K), R63.1
unnamed: C62.2, D24.2 (K), R64.1
unnamed: C63.2, R56.1, R62.2, U10.7, U10.10 (+)
unnamed: C64.1, IC6.3 (PB4(XTAL2/CLKO/OC1B/ADC2/PCINT4)), R63.2
unnamed: C65.1, IC6.2 (PB3(XTAL1/CLKI/OC1B/ADC3/PCINT3)), R64.2
unnamed: D21.1 (A), U10.8
unnamed: D22.1 (A), R58.2, U10.14
unnamed: D34.1 (A), R82.2
unnamed: IC6.6 (PB1(MISO/DO/AIN1/OC0B/OC1A/PCINT1)), R82.1
unnamed: R55.1, US6.2
unnamed: R56.2, R58.1, U10.13 (-)

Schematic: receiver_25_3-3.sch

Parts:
C67, C71: 10n
C68, C74: 470p
C69, C70: 47n
C72, C73, C77: 100n
C75, C76: 1n
D25, D26, D27, D28: DIODESCH
D35: LED
IC7: ATTINY45-P; DIP8
R65, R66, R69: 1k
R67, R68, R72, R83: 10k
R70, R71, R73, R74: 47k
U11: TL074
US7: ULTRASON

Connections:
/receiver_25_3-1/5V: C77.1, IC7.8 (VCC); also elsewhere on the board
/receiver_25_3-1/6V: U11.3 (+), U11.5 (+), U11.12 (+), US7.1; also elsewhere on the board
/receiver_25_3-1/12V: U11.11 (V-); also elsewhere on the board
/receiver_25_3-1/GND: C69.2, C70.2, C75.2, C76.2, C77.2, D27.1 (A), D28.1 (A), D35.2 (K), IC7.4 (GND), R70.2, R71.2, U11.4 (V+); also elsewhere on the board
/receiver_25_3-3/Trigger: IC7.5 (PB0(MOSI/DI/SDA/AIN0/OC0A/OC1A/AREF/PCI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); also elsewhere on the board
unnamed: C67.1, R65.2
unnamed: C67.2, C68.1, R67.1, U11.2 (-)
unnamed: C68.2, R67.2, R69.1, U11.1
unnamed: C69.1, C72.1, D25.2 (K), R70.1, U11.9 (-)
unnamed: C70.1, C73.1, D26.2 (K), R71.1
unnamed: C71.1, R69.2
unnamed: C71.2, C74.1, R72.1, U11.6 (-)
unnamed: C72.2, D27.2 (K), R73.1
unnamed: C73.2, D28.2 (K), R74.1
unnamed: C74.2, R66.1, R72.2, U11.7, U11.10 (+)
unnamed: C75.1, IC7.3 (PB4(XTAL2/CLKO/OC1B/ADC2/PCINT4)), R73.2
unnamed: C76.1, IC7.2 (PB3(XTAL1/CLKI/OC1B/ADC3/PCINT3)), R74.2
unnamed: D25.1 (A), U11.8
unnamed: D26.1 (A), R68.2, U11.14
unnamed: D35.1 (A), R83.2
unnamed: IC7.6 (PB1(MISO/DO/AIN1/OC0B/OC1A/PCINT1)), R83.1
unnamed: R65.1, US7.2
unnamed: R66.2, R68.1, U11.13 (-)

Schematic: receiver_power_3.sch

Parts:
C82, C83: 10µ
D37: LED
P12, P13: CONN_2
R75, R76, R85: 10k
U12: R-78E5.0-0.5; Converter_DCDC_RECOM_R-78E-0.5_THT
U13: NCP1117DT12RKG
U16: SWITCH

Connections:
/receiver_power_3/5V: D37.1 (A), U12.3 (OUT); also elsewhere on the board
/receiver_power_3/6V: R75.2, R76.1; also elsewhere on the board
/receiver_power_3/12V: C83.1, R75.1, U13.2 (VO); also elsewhere on the board
/receiver_power_3/GND: C82.2, C83.2, P13.1, R76.2, R85.2, U12.2 (GND), U13.1 (GND); also elsewhere on the board
unnamed: C82.1, U12.1 (IN), U13.3 (VI), U16.2
unnamed: D37.2 (K), R85.1
unnamed: P12.1, P13.2 (PM)
unnamed: P12.2 (PM), U16.1

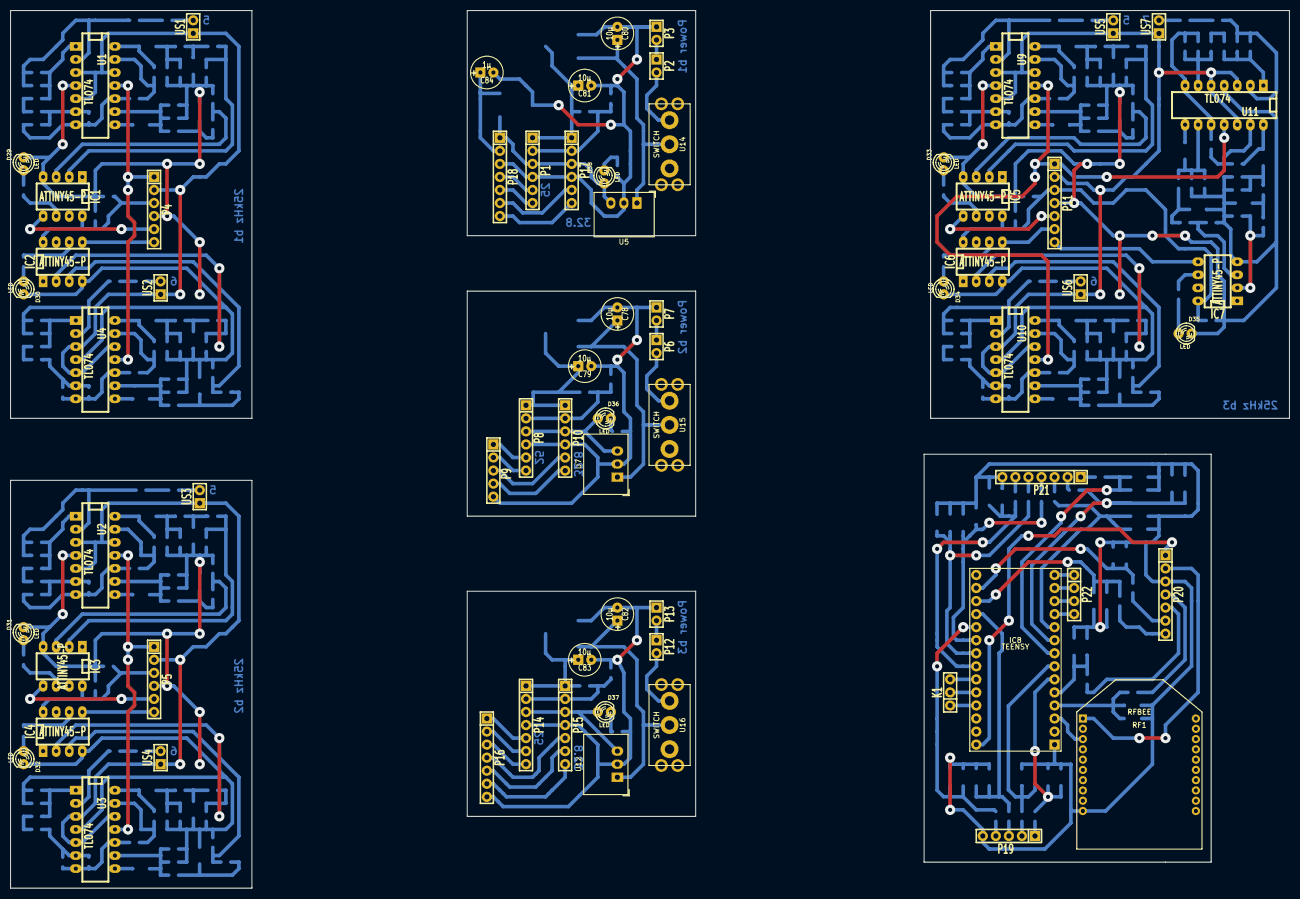
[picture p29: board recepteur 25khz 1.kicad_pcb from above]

Board: 2 copper layers, 248.9 x 170.8 mm, 306 parts (0 on the bottom side), 223 nets.

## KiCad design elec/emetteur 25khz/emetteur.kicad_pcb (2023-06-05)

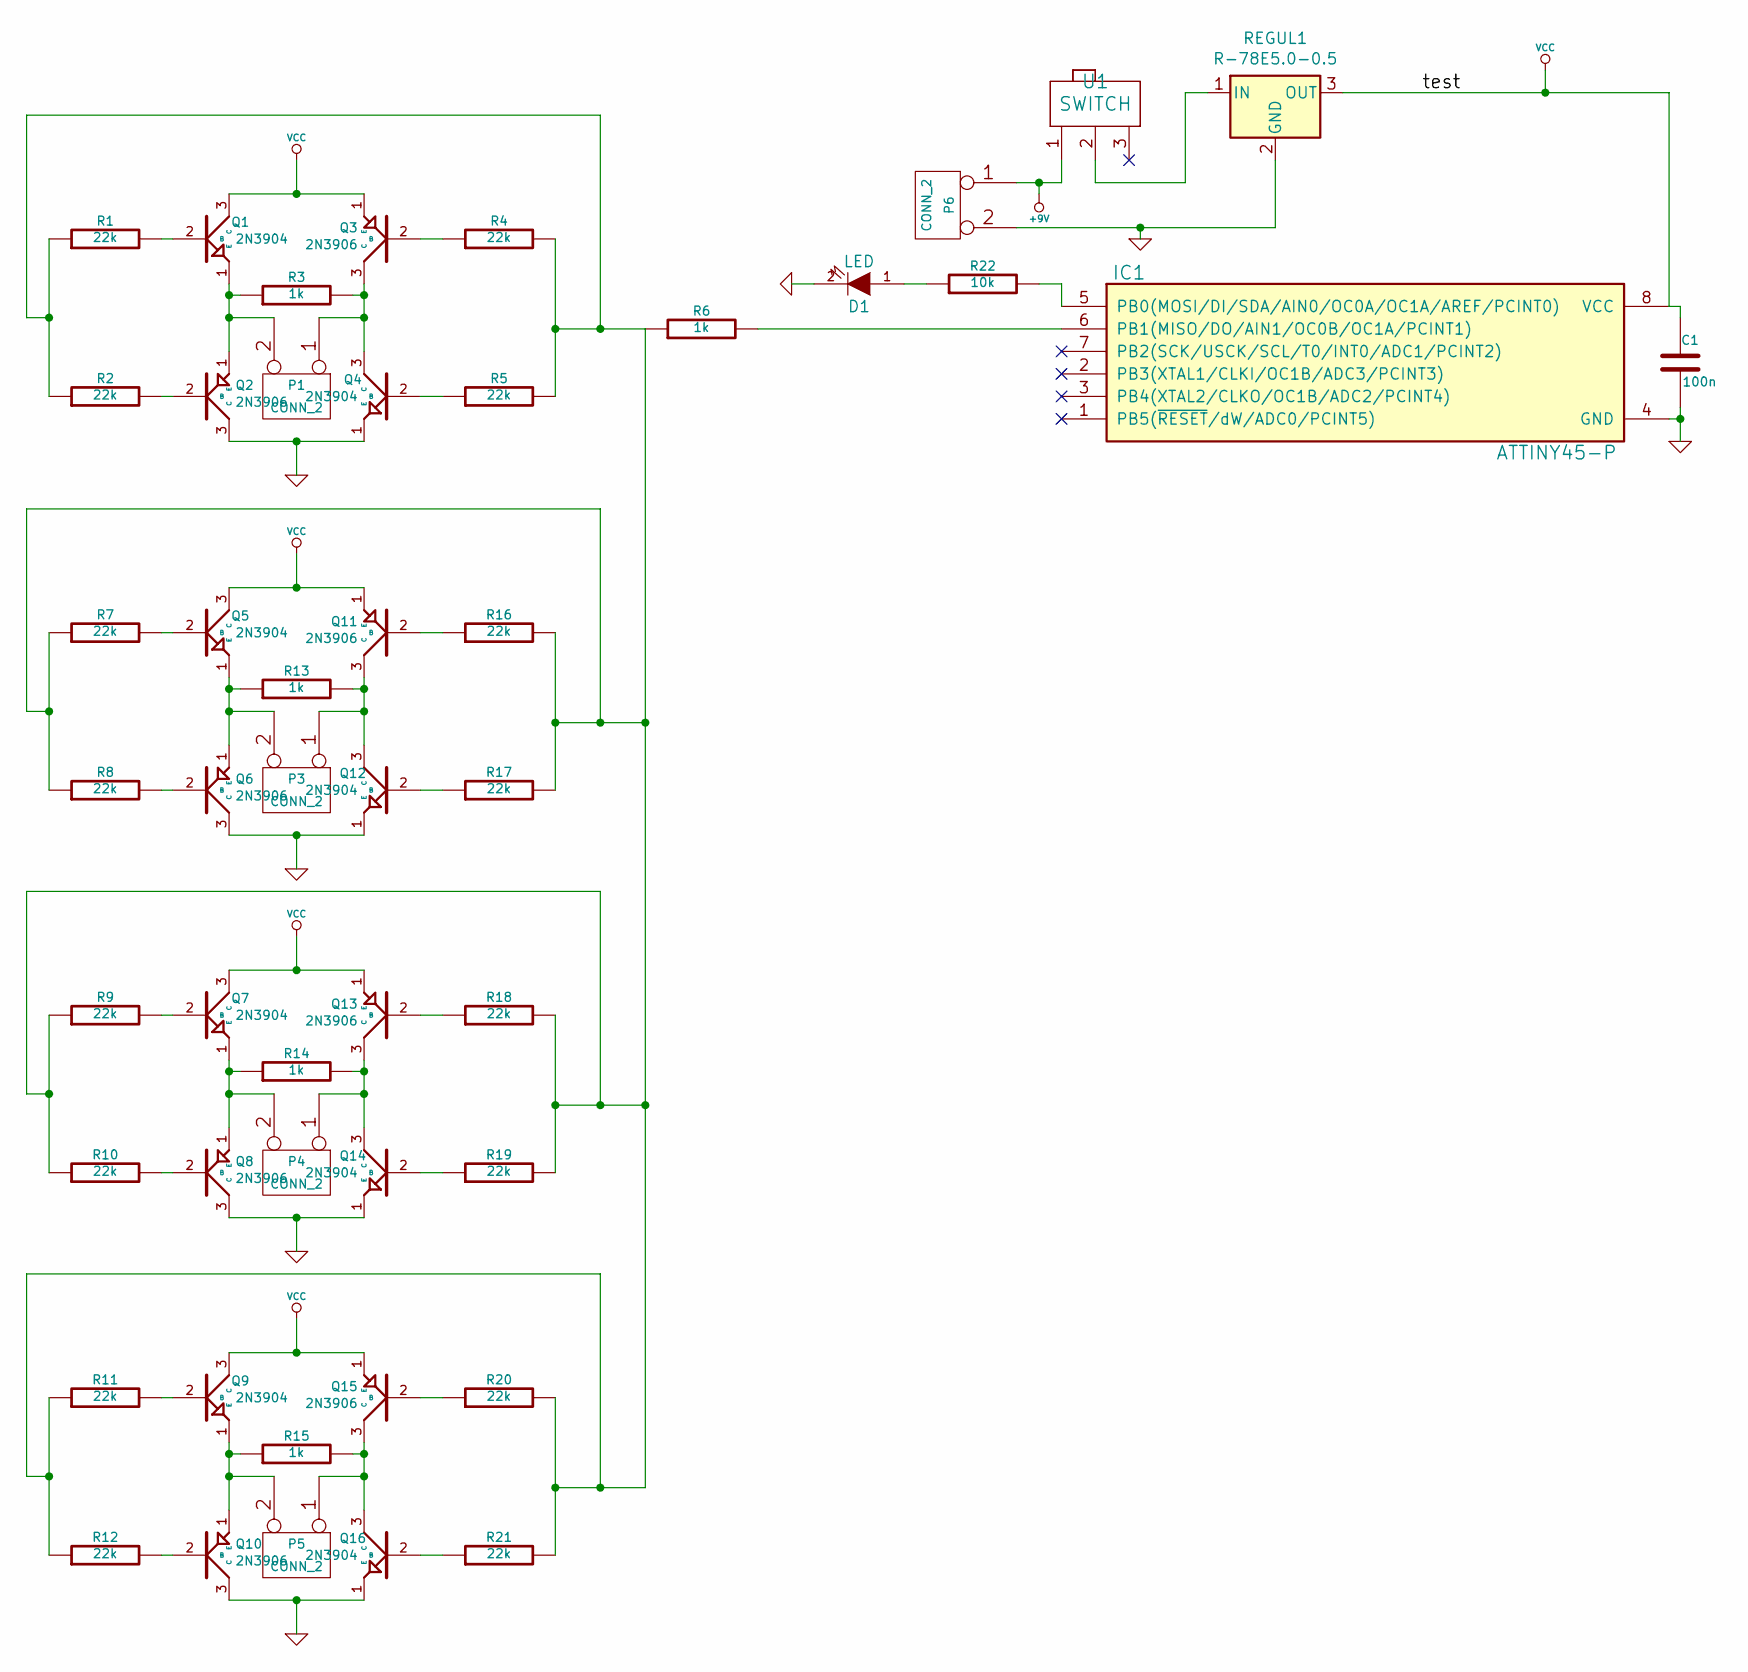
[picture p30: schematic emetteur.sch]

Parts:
C1: 100n
D1: LED
IC1: ATTINY45-P; DIP8
P1, P3, P4, P5, P6: CONN_2
Q1, Q4, Q5, Q7, Q9, Q12, Q14, Q16: 2N3904
Q2, Q3, Q6, Q8, Q10, Q11, Q13, Q15: 2N3906
R1, R2, R4, R5, R7, R8, R9, R10, R11, R12, R16, R17, R18, R19, R20, R21: 22k
R3, R6, R13, R14, R15: 1k
R22: 10k
REGUL1: R-78E5.0-0.5; Converter_DCDC_RECOM_R-78E-0.5_THT
U1: SWITCH

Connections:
+9V: P6.1, U1.1
GND: C1.2, D1.2 (K), IC1.4 (GND), P6.2 (PM), Q2.3 (C), Q4.1 (E), Q6.3 (C), Q8.3 (C), Q10.3 (C), Q12.1 (E), Q14.1 (E), Q16.1 (E), REGUL1.2 (GND)
unnamed: D1.1 (A), R22.1
unnamed: IC1.5 (PB0(MOSI/DI/SDA/AIN0/OC0A/OC1A/AREF/PCI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), R22.2
unnamed: IC1.6 (PB1(MISO/DO/AIN1/OC0B/OC1A/PCINT1)), R6.2
unnamed: P1.1, Q3.3 (C), Q4.3 (C), R3.2
unnamed: P1.2 (PM), Q1.1 (E), Q2.1 (E), R3.1
unnamed: P3.1, Q11.3 (C), Q12.3 (C), R13.2
unnamed: P3.2 (PM), Q5.1 (E), Q6.1 (E), R13.1
unnamed: P4.1, Q13.3 (C), Q14.3 (C), R14.2
unnamed: P4.2 (PM), Q7.1 (E), Q8.1 (E), R14.1
unnamed: P5.1, Q15.3 (C), Q16.3 (C), R15.2
unnamed: P5.2 (PM), Q9.1 (E), Q10.1 (E), R15.1
unnamed: Q1.2 (B), R1.2
unnamed: Q2.2 (B), R2.2
unnamed: Q3.2 (B), R4.1
unnamed: Q4.2 (B), R5.1
unnamed: Q5.2 (B), R7.2
unnamed: Q6.2 (B), R8.2
unnamed: Q7.2 (B), R9.2
unnamed: Q8.2 (B), R10.2
unnamed: Q9.2 (B), R11.2
unnamed: Q10.2 (B), R12.2
unnamed: Q11.2 (B), R16.1
unnamed: Q12.2 (B), R17.1
unnamed: Q13.2 (B), R18.1
unnamed: Q14.2 (B), R19.1
unnamed: Q15.2 (B), R20.1
unnamed: Q16.2 (B), R21.1
unnamed: R1.1, R2.1, R4.2, R5.2, R6.1, R7.1, R8.1, R9.1, R10.1, R11.1, R12.1, R16.2, R17.2, R18.2, R19.2, R20.2, R21.2
unnamed: REGUL1.1 (IN), U1.2
VCC: C1.1, IC1.8 (VCC), Q1.3 (C), Q3.1 (E), Q5.3 (C), Q7.3 (C), Q9.3 (C), Q11.1 (E), Q13.1 (E), Q15.1 (E), REGUL1.3 (OUT)

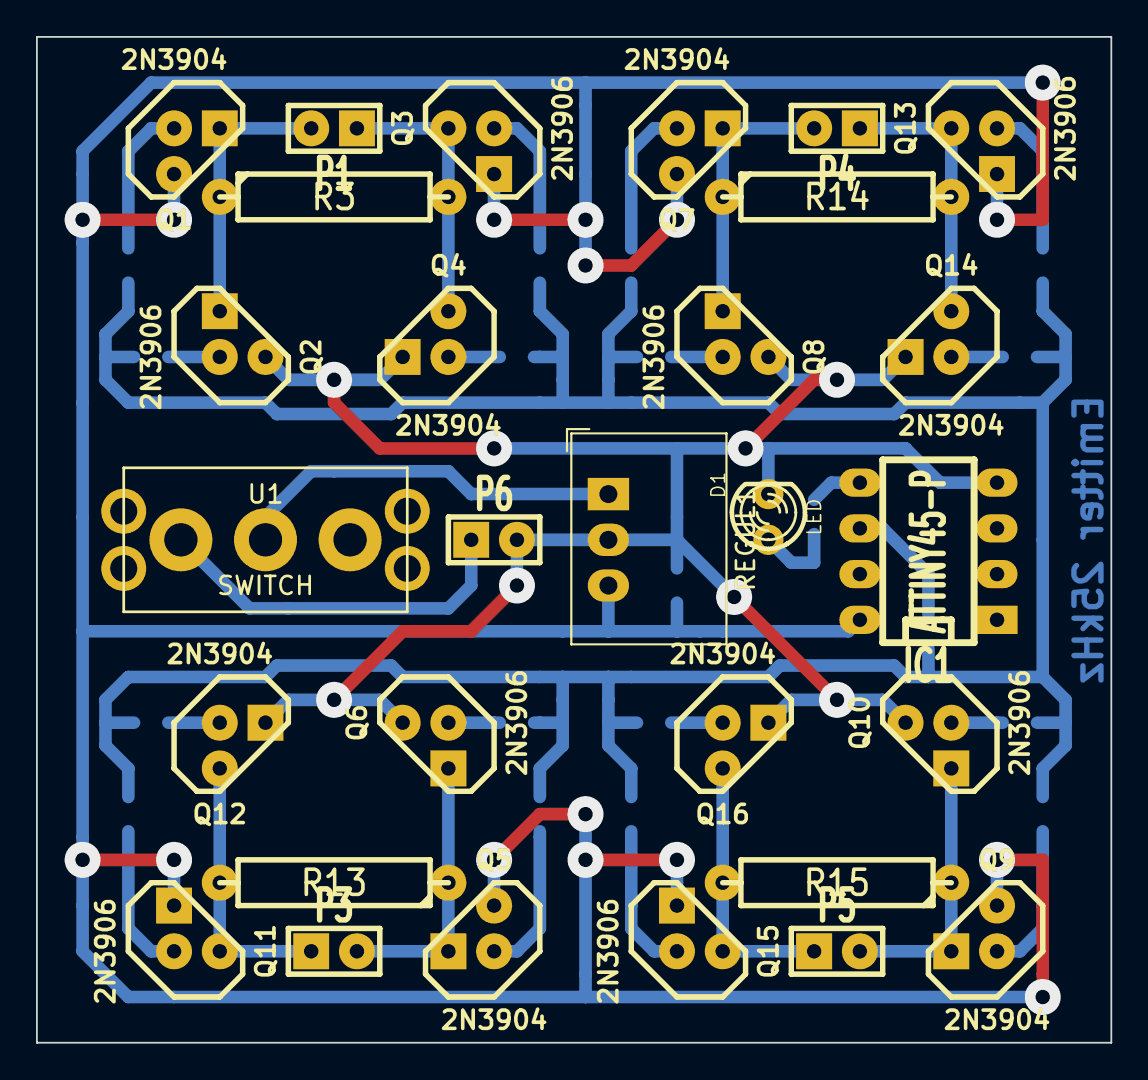
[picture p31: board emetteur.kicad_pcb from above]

Board: 2 copper layers, 59.7 x 55.9 mm, 48 parts (0 on the bottom side), 32 nets.

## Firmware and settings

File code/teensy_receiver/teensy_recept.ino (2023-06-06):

#include <math.h>
#include "SerialMessage.h"
#include "Message.h"

// set this to the hardware serial port you wish to use
#define RF_SERIAL Serial1

#define DEBUG 0

class Point {
  public:
    double x;
    double y;

    Point() : x(0), y(0) {}
    Point(double px, double py) : x(px), y(py) {}
    Point(const Point& p) : x(p.x), y(p.y) {}

    String toString() {
      return "(" + String(x) + ", " + String(y) + ")";
    }

    double distance2(const Point* p) {
      return (x - p->x) * (x - p->x) + (y - p->y) * (y - p->y);
    }

    double distance(const Point* p) {
      return sqrt(distance2(p));
    }
};

class BaseChanger {
  private:
    double _dx;
    double _dy;
    double _theta;

  public:
    BaseChanger(double dx, double dy, double theta) : _dx(dx), _dy(dy), _theta(theta) {}

    Point* change(double x, double y) {
      double nx = cos(_theta) * (x + _dx) - sin(_theta) * (y + _dy);
      double ny = sin(_theta) * (x + _dx) + cos(_theta) * (y + _dy);

      return new Point(nx, ny);
    }

    Point* change(const Point* p) {
      return change(p->x, p->y);
    }

    Point* restore(double x, double y) {
      double nx = - _dx + cos(- _theta) * x - sin(- _theta) * y;
      double ny = - _dy + sin(- _theta) * x + cos(- _theta) * y;

      return new Point(nx, ny);
    }

    Point* restore(const Point* p) {
      return restore(p->x, p->y);
    }
};

Point* BAD_POINT = new Point(-1, -1);

class FangThreePointsLateration {
  private:
    Point _b1;
    Point _b2;
    Point _b3;

    Point* _foundP1;
    Point* _foundP2;

    BaseChanger* turnBase(Point* p1, Point* p2) {
      double dx = p2->x - p1->x;
      double dy = p2->y - p1->y;
      double theta;

      if (dx != 0) {
        double alpha = atan(dy / dx);
        theta = PI - alpha;
      } else {
        theta = PI / 2;
      }

      return new BaseChanger(- p1->x, - p1->y, theta);
    }

    Point* keepGoodPoint(Point* p1, Point* p2, double a, double b, double c) {
      if (a == 0) {
        double p1b = _b2.distance2(p1) - _b1.distance2(p1);
        double p2b = _b2.distance2(p2) - _b1.distance2(p2);
        if (p1b < 0)
          return p2;
        else if (p2b < 0)
          return p1;
        else {
          double bc = b * b;
          if (abs(bc - p1b) < abs(bc - p2b))
            return p1;
          else
            return p2;
        }
      } else if (b == 0) {
        double p1a = _b1.distance2(p1) - _b2.distance2(p1);
        double p2a = _b1.distance2(p2) - _b2.distance2(p2);
        if (p1a < 0)
          return p2;
        else if (p2a < 0)
          return p1;
        else {
          double ac = a * a;
          if (abs(ac - p1a) < abs(ac - p2a))
            return p1;
          else
            return p2;
        }
      } else if (c == 0) {
        double p1c = _b1.distance2(p1) - _b3.distance2(p1);
        double p2c = _b1.distance2(p2) - _b3.distance2(p2);
        if (p1c < 0)
          return p2;
        else if (p2c < 0)
          return p1;
        else {
          double cc = c * c;
          if (abs(cc - p1c) < abs(cc - p2c))
            return p1;
          else
            return p2;
        }
      }

      RF_SERIAL.print("No good point ");
      RF_SERIAL.print(a);
      RF_SERIAL.print(", ");
      RF_SERIAL.print(b);
      RF_SERIAL.print(", ");
      RF_SERIAL.println(c);
      return BAD_POINT;
    }

    double fixDiff(double dr, double baseDistance) {
      // divide by 0 is bad ;) and I don't want to manage cases :P
      // Faking it will cause an error of 0.005 mm, thats OK
      if (dr >= 0 && dr <= 0.005)
        return 0.005;

      // due to error measure, dr can be larger than distance between to bases
      // this is not possible ...
      if (dr > baseDistance)
        return baseDistance;
      return dr;
    }

  public:
    FangThreePointsLateration() : _foundP1(new Point(0, 0)), _foundP2(new Point(0, 0)) {}

    Point* findPoint(Point& b1, Point &b2, Point &b3, double a, double b, double c) {
      _b1 = b1;
      _b2 = b2;
      _b3 = b3;
      
      delete _foundP1;
      delete _foundP2;

      // change base in order to get tb1(0, 0), tb2(x2, 0), tb3(x3, y3)
      Point *tb1, *tb2, *tb3;
      BaseChanger *bc;
      double r21, r31;

      if (a == 0) {
        bc = turnBase(&_b1, &_b2);
        tb1 = bc->change(&_b1);
        tb2 = bc->change(&_b2);
        tb3 = bc->change(&_b3);
        r21 = fixDiff(b, tb1->distance(tb2));
        r31 = fixDiff(c, tb1->distance(tb3));
      } else if (b == 0) {
        bc = turnBase(&_b2, &_b1);
        tb1 = bc->change(&_b2);
        tb2 = bc->change(&_b1);
        tb3 = bc->change(&_b3);
        r21 = fixDiff(a, tb1->distance(tb2));
        r31 = fixDiff(c, tb1->distance(tb3));
      } else {
        bc = turnBase(&_b3, &_b1);
        tb1 = bc->change(&_b3);
        tb2 = bc->change(&_b1);
        tb3 = bc->change(&_b2);
        r21 = fixDiff(a, tb1->distance(tb2));
        r31 = fixDiff(b, tb1->distance(tb3));
      }

      // search 2 points
      double g = (r31 * (tb2->x / r21) - tb3->x) / tb3->y;
      double i = 1 - (tb2->x / r21) * (tb2->x / r21);
      double h = (tb3->x * tb3->x + tb3->y * tb3->y - r31 * r31 + r31 * r21 * i) / (2 * tb3->y);

      double d = - (i + g * g);
      double e = tb2->x * i - 2 * g * h;
      double f = (r21 * r21 / 4) * i * i - h * h;

      double delta = e * e - 4 * d * f;
      // In case of double precision issue
      if (delta > -0.00001 && delta <= 0)
        delta = 0;
      if (delta < 0) {
        RF_SERIAL.println("Delta negativ : " + String(delta));
      }
      double sqrtDelta = sqrt(delta);
      double tx1 = (- e + sqrtDelta) / (2 * d);
      double tx2 = (- e - sqrtDelta) / (2 * d);

      double ty1 = g * tx1 + h;
      double ty2 = g * tx2 + h;

      // restore in orig base
      _foundP1 = bc->restore(tx1, ty1);
      _foundP2 = bc->restore(tx2, ty2);

      delete bc;
      delete tb1;
      delete tb2;
      delete tb3;

      Point* goodPoint = keepGoodPoint(_foundP1, _foundP2, a, b, c);
      Point* finalPoint = new Point(goodPoint->x, goodPoint->y);

      return finalPoint;
    }

    Point* getFoundP1() {
      return _foundP1;
    }

    Point* getFoundP2() {
      return _foundP2;
    }
};

// from : https://forum.pjrc.com/archive/index.php/t-7531.html
#define INPUT_PULLDOWN 3
#define OUTPUT_OPENDRAIN 4
void myPinMode(uint8_t pin, uint8_t mode) {
  volatile uint32_t *config;

  if (pin >= CORE_NUM_DIGITAL) return;
  config = portConfigRegister(pin);

  if (mode == OUTPUT || mode == OUTPUT_OPENDRAIN) {
    *portModeRegister(pin) = 1;
    __disable_irq();
    *config &= ~PORT_PCR_MUX_MASK;
    *config |= (PORT_PCR_SRE | PORT_PCR_DSE | PORT_PCR_MUX(1));
    if (mode == OUTPUT_OPENDRAIN) {
      *config |= PORT_PCR_ODE;
    } else {
      *config &= ~PORT_PCR_ODE;
    }
    __enable_irq();
  } else if (mode == INPUT || mode == INPUT_PULLUP || mode == INPUT_PULLDOWN) {
    *portModeRegister(pin) = 0;
    __disable_irq();
    *config &= ~PORT_PCR_MUX_MASK;
    *config |= PORT_PCR_MUX(1);
    if (mode == INPUT_PULLUP) {
      *config |= (PORT_PCR_PE | PORT_PCR_PS); // pullup
    } else if (mode == INPUT_PULLDOWN) {
      *config |= (PORT_PCR_PE); // pulldown
      *config &= ~(PORT_PCR_PS);
    }
    __enable_irq()
  }
}

#include <avr/io.h>
#include <avr/interrupt.h>

#define PIN_25_1_1 0
#define PIN_25_1_2 1
#define PIN_25_2_1 2
#define PIN_25_2_2 3
#define PIN_25_3_1 4
#define PIN_25_3_2 5
#define PIN_25_3_3 6

#define PIN_32_1_1 0
#define PIN_32_1_2 1
#define PIN_32_2_1 2
#define PIN_32_2_2 3
#define PIN_32_3_1 4
#define PIN_32_3_2 5
#define PIN_32_3_3 6

#define FREQ_25 0
#define FREQ_32 1

// 11800 µs -> 4m at sound speed
#define TIME_WINDOW 11800

short pins25[] = {2, 3, 4, 5, 6, 7, 8};
short pins32[] = {14, 15, 16, 17, 18, 19, 20};

//Point b1 = Point(0, 0);
//Point b2 = Point(0, 2000);
//Point b3 = Point(3000, 1000);

Point bases[] = {
  // 25
  Point(-10, -60),
  Point(-37, -10),
  Point(-37, 2010),
  Point(-10, 2060),
  Point(3015, 1030),
  Point(3003, 1000),
  Point(2985, 970),
  
  // 32.8
  Point(-10, -60),
  Point(-37, -10),
  Point(-37, 2010),
  Point(-10, 2060),
  Point(3015, 1030),
  Point(3003, 1000),
  Point(2985, 970)
};

FangThreePointsLateration tpl = FangThreePointsLateration();

volatile unsigned long started[] = {0, 0};
volatile int times[] = {-1, -1, -1, -1, -1, -1, -1, // 25kHz
                        -1, -1, -1, -1, -1, -1, -1}; // 32.8kHz

/*
void runTestTable() {
  Serial.println("Run test");
  for (int x = 0; x < 3000; x += 100) {
    for (int y = 0; y < 2000; y += 100) {
      Point realPos = Point(x, y);

      double r1 = b1.distance(&realPos);
      double r2 = b2.distance(&realPos);
      double r3 = b3.distance(&realPos);

      //      r1 += Math.random() * ERROR;
      //      r2 += Math.random() * ERROR;
      //      r3 += Math.random() * ERROR;

      Point* foundP;

      if (r1 <= r2 && r1 <= r3) {
        foundP = tpl.findPoint(0, r2 - r1, r3 - r1);
      } else if (r2 <= r1 && r2 <= r3) {
        foundP = tpl.findPoint(r1 - r2, 0, r3 - r2);
      } else if (r3 <= r1 && r3 <= r2) {
        foundP = tpl.findPoint(r1 - r3, r2 - r3, 0);
      } else {
        foundP = new Point(-1, -1);
      }

      double error = realPos.distance(foundP);
      Serial.print(String(x));
      Serial.print(", ");
      Serial.print(y);
      Serial.print(" found : ");
      Serial.print(foundP->x);
      Serial.print(", ");
      Serial.print(foundP->y);
      Serial.print(" with error : ");
      Serial.println(error);

      delete foundP;
    }
  }
}*/

void updatePin25(int pin) {
  //Serial.println("Pin up : " + String(pin));
  if (started[FREQ_25] == 0) {
    started[FREQ_25] = micros();
    times[pin] = 0;
  } else {
    int time = micros() - started[FREQ_25];
    if (time < TIME_WINDOW && times[pin] == -1)
      times[pin] = time;
  }
}

void pin25_1_1_Interrupt() {
  cli();
  updatePin25(PIN_25_1_1);
  sei();
}

void pin25_1_2_Interrupt() {
  cli();
  updatePin25(PIN_25_1_2);
  sei();
}

void pin25_2_1_Interrupt() {
  cli();
  updatePin25(PIN_25_2_1);
  sei();
}

void pin25_2_2_Interrupt() {
  cli();
  updatePin25(PIN_25_2_2);
  sei();
}

void pin25_3_1_Interrupt() {
  cli();
  updatePin25(PIN_25_3_1);
  sei();
}

void pin25_3_2_Interrupt() {
  cli();
  updatePin25(PIN_25_3_2);
  sei();
}

void pin25_3_3_Interrupt() {
  cli();
  updatePin25(PIN_25_3_3);
  sei();
}

void updatePin32(int pin) {
  //Serial.println("Pin up : " + String(pin));
  if (started[FREQ_32] == 0) {
    started[FREQ_32] = micros();
    times[pin] = 0;
  } else {
    int time = micros() - started[FREQ_32];
    if (time < TIME_WINDOW && times[pin] == -1)
      times[pin] = time;
  }
}

void pin32_1_1_Interrupt() {
  cli();
  updatePin32(PIN_32_1_1);
  sei();
}

void pin32_1_2_Interrupt() {
  cli();
  updatePin32(PIN_32_1_2);
  sei();
}

void pin32_2_1_Interrupt() {
  cli();
  updatePin32(PIN_32_2_1);
  sei();
}

void pin32_2_2_Interrupt() {
  cli();
  updatePin32(PIN_32_2_2);
  sei();
}

void pin32_3_1_Interrupt() {
  cli();
  updatePin32(PIN_32_3_1);
  sei();
}

void pin32_3_2_Interrupt() {
  cli();
  updatePin32(PIN_32_3_2);
  sei();
}

void pin32_3_3_Interrupt() {
  cli();
  updatePin32(PIN_32_3_3);
  sei();
}

double soundSpeed() {
  return 344.854;
}

/**
 * Concert micro seconds to millimeters at sound speed
 */
double timeToDistance(int us) {
  return us / 1000.0 * soundSpeed();
}

//void debugPoint(Point *po) {
//  Serial.print(po->x);
//  Serial.print(", ");
//  Serial.print(po->y);
//  Serial.println("");
//}

void filterClosedReceivers(int distances[], int from, int to) {
  int first = 999999;
  for (int i = from; i <= to; i++)  {
    if (distances[i] != -1 && distances[i] < first)
      first = distances[i];
  }
  
  for (int i = from; i <= to; i++) {
    if (distances[i] != -1 && distances[i] > first + 200) {
      distances[i] = -1;
      if (DEBUG > 2) {
        RF_SERIAL.print("Removed : ");
        RF_SERIAL.print(distances[i]);
        RF_SERIAL.print(" : ");
        RF_SERIAL.println(i);
      }
    }
  }
}

SerialMessage sm = SerialMessage(&RF_SERIAL);
int ledState = 0;

void setup() {
  Serial.begin(9600);
  RF_SERIAL.begin(115200);

  for (int i = PIN_25_1_1; i <= PIN_25_3_3; i++) {
    myPinMode(pins25[i], INPUT_PULLDOWN);
  }

  attachInterrupt(pins25[PIN_25_1_1], pin25_1_1_Interrupt, RISING);
  attachInterrupt(pins25[PIN_25_1_2], pin25_1_2_Interrupt, RISING);
  attachInterrupt(pins25[PIN_25_2_1], pin25_2_1_Interrupt, RISING);
  attachInterrupt(pins25[PIN_25_2_2], pin25_2_2_Interrupt, RISING);
  attachInterrupt(pins25[PIN_25_3_1], pin25_3_1_Interrupt, RISING);
  attachInterrupt(pins25[PIN_25_3_2], pin25_3_2_Interrupt, RISING);
  attachInterrupt(pins25[PIN_25_3_3], pin25_3_3_Interrupt, RISING);

  for (int i = PIN_32_1_1; i <= PIN_32_3_3; i++) {
    myPinMode(pins32[i], INPUT_PULLDOWN);
  }

  attachInterrupt(pins32[PIN_32_1_1], pin32_1_1_Interrupt, RISING);
  attachInterrupt(pins32[PIN_32_1_2], pin32_1_2_Interrupt, RISING);
  attachInterrupt(pins32[PIN_32_2_1], pin32_2_1_Interrupt, RISING);
  attachInterrupt(pins32[PIN_32_2_2], pin32_2_2_Interrupt, RISING);
  attachInterrupt(pins32[PIN_32_3_1], pin32_3_1_Interrupt, RISING);
  attachInterrupt(pins32[PIN_32_3_2], pin32_3_2_Interrupt, RISING);
  attachInterrupt(pins32[PIN_32_3_3], pin32_3_3_Interrupt, RISING);
  
  pinMode(13, OUTPUT);
}

void computePos(short freq, short startPin, short endPin, short firstB1, short lastB1, short firstB2, short lastB2, short firstB3, short lastB3) {
  if (started[freq] != 0) {
    cli();
    if (micros() - started[freq] > TIME_WINDOW) { // time for sound to run 4 meters
      int _times[14];
      for (int i = startPin; i <= endPin; i++) {
        _times[i] = times[i];
        
        // reset
        times[i] = -1;
      }
      
      started[freq] = 0;
      sei();
      
      // process compute
      int _distances[14];
      for (int i = startPin; i <= endPin; i++) {
        if (_times[i] != -1)
          _distances[i] = timeToDistance(_times[i]);
        else
          _distances[i] = -1;
      }
      
      if (DEBUG > 1) {
        RF_SERIAL.print("Recept times : ");
        for (int i = startPin; i <= endPin; i++) {
          RF_SERIAL.print(_times[i]);
          RF_SERIAL.print(", ");
        }
        RF_SERIAL.println("");
      }
      
      Point foundSum = Point(0, 0);
      int numSum = 0;
      
      // filter closed receivers
      filterClosedReceivers(_distances, firstB1, lastB1);
      filterClosedReceivers(_distances, firstB2, lastB2);
      filterClosedReceivers(_distances, firstB3, lastB3);
      
      for (int i = firstB1; i <= lastB1; i++) {
        if (_distances[i] != -1) {
          for (int j = firstB2; j <= lastB2; j++) {
            if (_distances[j] != -1) {
              for (int k = firstB3; k <= lastB3; k++) {
                if (_distances[k] != -1) {
                  int a = -1, b = -1, c = -1;
                  if (_distances[i] <= _distances[j] && _distances[i] <= _distances[k]) {
                    a = 0;
                    b = _distances[j] - _distances[i];
                    c = _distances[k] - _distances[i];
                  } else if (_distances[j] <= _distances[i] && _distances[j] <= _distances[k]) {
                    a = _distances[i] - _distances[j];
                    b = 0;
                    c = _distances[k] - _distances[j];
                  } else if (_distances[k] <= _distances[i] && _distances[k] <= _distances[j]) {
                    a = _distances[i] - _distances[k];
                    b = _distances[j] - _distances[k];
                    c = 0;
                  }
                  
                  Point* foundP = tpl.findPoint(bases[i], bases[j], bases[k], a, b, c);
                  foundSum.x += foundP->x;
                  foundSum.y += foundP->y;
                  numSum++;
                  
                  if (DEBUG > 1) {
                    RF_SERIAL.print("Non filtered : ");
                    RF_SERIAL.print(foundP->x);
                    RF_SERIAL.print(", ");
                    RF_SERIAL.print(foundP->y);
                    RF_SERIAL.println(";");
                  }
                  
                  delete foundP;
                }
              }
            }
          }
        }
      }
      //Point* foundP = tpl.findPoint(b1, b2, b3, timeToDistance(_times[firstB1]), timeToDistance(_times[firstB2]), timeToDistance(_times[firstB3]));
      
      //debugPoint(foundP);
      Point filteredPoint = Point(foundSum.x / numSum, foundSum.y / numSum);
      if (filteredPoint.x > 0 && filteredPoint.x < 3000 && filteredPoint.y > 0 && filteredPoint.y < 2000) {
        if (DEBUG >= 1) {
          if (freq == FREQ_25)
            RF_SERIAL.print("25kHz : ");
          else
            RF_SERIAL.print("32.8kHz : ");
            
          RF_SERIAL.print(filteredPoint.x);
          RF_SERIAL.print(", ");
          RF_SERIAL.print(filteredPoint.y);
          RF_SERIAL.println("");
          /*
          RF_SERIAL.print("[");
          RF_SERIAL.print(filteredPoint.x);
          RF_SERIAL.print(", ");
          RF_SERIAL.print(filteredPoint.y);
          RF_SERIAL.println("],");
          */
        }
        
        char id = 0x00;
        if (freq == FREQ_25)
          id = 0x10;
        else
          id = 0x11;
        Message msg = Message(id);
        msg.packFloat(filteredPoint.x);
        msg.packFloat(filteredPoint.y);
        sm.sendMessage(&msg);
        
        if (ledState == 0) {
          digitalWrite(13, 0);
          ledState = 1;
        } else {
          digitalWrite(13, 1);
          ledState = 0;
        }
      }
    } else {
      sei();
    }
  }
}

unsigned long delayPing = 0;
void loop() {
  computePos(FREQ_25, PIN_25_1_1, PIN_25_3_3, PIN_25_1_1, PIN_25_1_2, PIN_25_2_1, PIN_25_2_2, PIN_25_3_1, PIN_25_3_3);
  computePos(FREQ_32, PIN_25_1_1, PIN_25_3_3, PIN_25_1_1, PIN_25_1_2, PIN_25_2_1, PIN_25_2_2, PIN_25_3_1, PIN_25_3_3);
  if (millis() - delayPing > 1000) {
    delayPing = millis();
    Message msg = Message(0x00);
    sm.sendMessage(&msg);
  }
}

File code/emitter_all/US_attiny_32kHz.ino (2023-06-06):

/*
 * Expect 8MHz clock.
 * Will generate a loop at 25/32.8 kHz modulation of (8 square, 16 periods low) 3 times, and wait 50ms low
 */

#define FREQ25 false
#define FREQ32 true

int longWait = 0;
int pulsePart = 0;
int ledState = 0;

unsigned char trainTCCR1() {
  if (FREQ25)
    return _BV(CTC1) | _BV(CS12) | _BV(CS11); // clk / 32
  else if (FREQ32)
    return _BV(CTC1) | _BV(CS12) | _BV(CS10); // clk / 16
}

int trainTCNT1HalfTime(boolean half, int pulsePart) {
  if (FREQ25) {
    if (half)
      return 80; // 320µs
    else
      return 160; // 640µs
  } else if (FREQ32) {
    if (half) {
      if (pulsePart == 0)
        return 137; // 274.4µs 9 pulses
      else
        return 107; // 213.4µs 7 pulses
    } else
      return 183; // 365.9µs 12 pulses
  }
}

unsigned char pwmTCCR0BPrescaler() {
  if (FREQ25)
    return 0b010; // clk / 8
  else if (FREQ32)
    return 0b001; // clk
}

unsigned char pwmOCR0(boolean a) {
  if (FREQ25) {
    if (a)
      return 40;
    else
      return 20;
  } else if (FREQ32) {
    if (a)
      return 250;
    else
      return 125;
  }
}

void setup() {
  pinMode(0, OUTPUT);
  pinMode(1, OUTPUT);
  
  /*
    Control Register A for Timer/Counter-0 (Timer/Counter-0 is configured using two registers: A and B)
    TCCR0A is 8 bits: [COM0A1:COM0A0:COM0B1:COM0B0:unused:unused:WGM01:WGM00]
    2<<COM0A0: sets bits COM0A0 and COM0A1, which (in Fast PWM mode) clears OC0A on compare-match, and sets OC0A at BOTTOM
    2<<COM0B0: sets bits COM0B0 and COM0B1, which (in Fast PWM mode) clears OC0B on compare-match, and sets OC0B at BOTTOM
    3<<WGM00: sets bits WGM00 and WGM01, which (when combined with WGM02 from TCCR0B below) enables Fast PWM mode
  */
  TCCR0A = 0b01100011;
  
  /*
    Control Register B for Timer/Counter-0 (Timer/Counter-0 is configured using two registers: A and B)
    TCCR0B is 8 bits: [FOC0A:FOC0B:unused:unused:WGM02:CS02:CS01:CS00]
    0<<WGM02: bit WGM02 remains clear, which (when combined with WGM00 and WGM01 from TCCR0A above) enables Fast PWM mode
    1<<CS00: sets bits CS01 (leaving CS01 and CS02 clear), which tells Timer/Counter-0 to not use a prescalar
  */
  //TCCR0B = 0b00001001;
  TCCR0B = TCCR0B & 0b11110000 | 0b1010;
  OCR0A = pwmOCR0(true);
  OCR0B = pwmOCR0(false);
  
  // Timer 1
  TCCR1 = 0;                  //stop the timer
  TCNT1 = 0;                  //zero the timer
  GTCCR = _BV(PSR1);          //reset the prescaler
  //start timer, ctc mode    
  TCCR1 = trainTCCR1();
}

void loop() {
  if (longWait == 1) {
    if (TCNT1 >= 73) { // 75ms
      TCCR1 = 0;                  //stop the timer
      GTCCR = _BV(PSR1);          //reset the prescaler
      // start timer, ctc mode    
      TCCR1 = trainTCCR1();
      // reset timer
      TCNT1 = 0;
      
      // start pwm
      TCCR0B = TCCR0B & 0b11111000 | pwmTCCR0BPrescaler();
      // Goto short wait
      longWait = 0;
    }
  } else {
    int timeout = 0;
    if (pulsePart %2 == 0) {
      if (TCNT1 >= trainTCNT1HalfTime(true, pulsePart)) {
        // stop pwm
        TCCR0B = TCCR0B & 0b11111000;
        timeout = 1;
      }
    } else {
      if (TCNT1 >= trainTCNT1HalfTime(false, pulsePart)) {
        // start pwm
        TCCR0B = TCCR0B & 0b11111000 | pwmTCCR0BPrescaler();
        timeout = 1;
      }
    }
    
    if (timeout == 1) {
      pulsePart++;
      if (pulsePart > 4) {
        // init timer for long wait
        TCCR1 = 0;                  //stop the timer
        GTCCR = _BV(PSR1);          //reset the prescaler
        //start timer, ctc mode    
        TCCR1 = _BV(CTC1) | _BV(CS13) | _BV(CS12) | _BV(CS11);
        
        longWait = 1;
        pulsePart = 0;
        
        // blink the led
        if (ledState == 0) {
          digitalWrite(0, HIGH);
          ledState = 1;
        } else {
          digitalWrite(0, LOW);
          ledState = 0;
        }
      }
      
      // reset timer
      TCNT1 = 0;
    }
  }
}

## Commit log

2023-06-05 Project init from archive, Kicad update from 2013 version to verion 5
    [Commande.xls, emetteur-2023-06-02-15-33-03.sch, emetteur-2023-06-05-13-58-40.sch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]
2023-06-06 Add some documentation
    [recepteur 25khz 1.sch, recepteur 32khz.sch]
2023-06-09 Elec: add readme
    [emetteur.csv]
